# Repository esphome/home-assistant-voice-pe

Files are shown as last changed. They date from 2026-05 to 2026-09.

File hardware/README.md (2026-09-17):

# Home Assistant Voice Preview Edition

This repo contains the KiCad project files for the Home Assistant Voice Preview Edition device.

It is licensed under the CERN-OHL-P v2.

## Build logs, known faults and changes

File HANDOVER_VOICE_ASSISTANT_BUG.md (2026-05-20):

# Handover: Voice Assistant Microphone Restart Bug

## Summary

**Bug**: Voice PE starts listening before TTS audio finishes playing, causing the device to hear itself and re-trigger STT.

**Root Cause**: In `esphome/components/voice_assistant/voice_assistant.cpp`, the `RESPONSE_FINISHED` state transitions to `START_MICROPHONE` without waiting for the media player to finish playing.

**Fix Location**: `esphome/esphome` repository, file `esphome/components/voice_assistant/voice_assistant.cpp`

---

## Related Issues

- **Existing Issue**: https://github.com/esphome/home-assistant-voice-pe/issues/563
  - Title: "Microphone re-opens before announcement finishes playing in continuous conversation mode"
  - Status: Open
  - Created: 2026-03-20
  - Has 2 thumbs up reactions

- **Slack Thread**: https://openhomefoundation.slack.com/archives/C08MUM89GUW/p1779288998390289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

---

## Bug Details

### Symptoms

1. User configures Voice PE with:
   - OpenAI gpt-4o-transcribe for STT
   - Claude Sonnet for conversation engine
   - OpenAI TTS

2. When the assistant asks a follow-up question, the microphone starts listening **before** the TTS audio finishes playing

3. The device hears its own TTS output and re-triggers STT, causing conversation failures

### Log Evidence (from Slack)

**With OpenAI TTS (BROKEN)** - Only 2 seconds for 4+ second audio:
```
[16:32:34][D][voice_assistant:490]: Desired state set to STREAMING_RESPONSE
[16:32:34][D][voice_assistant:631]: Event Type: 2
[16:32:34][D][voice_assistant:773]: Assist Pipeline ended
[16:32:34][D][http_media_source:069]: Starting
[16:32:36][D][voice_assistant:483]: State changed from STREAMING_RESPONSE to RESPONSE_FINISHED
[16:32:36][D][voice_assistant:483]: State changed from RESPONSE_FINISHED to START_MICROPHONE
```

**With HA Cloud TTS (WORKING)** - 9 seconds matches audio length:
```
[16:44:04][D][http_media_source:069]: Starting
[16:44:13][D][voice_assistant:483]: State changed from STREAMING_RESPONSE to RESPONSE_FINISHED
```

### Why It Happens

- OpenAI TTS streams audio data faster than real-time playback
- The HTTP download completes in ~2 seconds
- But the audio file is 4+ seconds long
- The state machine sees "streaming complete" and transitions immediately
- No check exists for media player playback completion

---

## Technical Analysis

### State Machine Flow

```
STREAMING_RESPONSE 
    → (audio data streaming finishes)
    → RESPONSE_FINISHED 
    → (if continue_conversation_) 
    → START_MICROPHONE  ← BUG: No wait for media player!
```

### Current Code (voice_assistant.cpp)

```cpp
case State::RESPONSE_FINISHED: {
#ifdef USE_SPEAKER
  if (this->speaker_ != nullptr) {
    // Checks for speaker buffer - works for internal speaker
    if (this->speaker_buffer_size_ > 0) {
      this->write_speaker_();
      break;
    }
    if (this->speaker_->has_buffered_data() || this->speaker_->is_running()) {
      break;
    }
    // ... speaker cleanup
  }
#endif
  // BUG: When using media_player_ (not speaker_), no wait occurs!
  if (this->continue_conversation_) {
    this->set_state_(State::START_MICROPHONE, State::START_PIPELINE);
  } else {
    this->set_state_(State::IDLE, State::IDLE);
  }
  break;
}
```

### The Problem

When `speaker_` is `nullptr` (user configured `media_player:` instead of `speaker:`), the speaker buffer checks are skipped entirely. The code immediately checks `continue_conversation_` and transitions to `START_MICROPHONE`.

---

## Proposed Fix

Add a media player announcement check before transitioning to `START_MICROPHONE`:

```cpp
case State::RESPONSE_FINISHED: {
#ifdef USE_SPEAKER
  if (this->speaker_ != nullptr) {
    if (this->speaker_buffer_size_ > 0) {
      this->write_speaker_();
      break;
    }
    if (this->speaker_->has_buffered_data() || this->speaker_->is_running()) {
      break;
    }
    ESP_LOGD(TAG, "Speaker has finished outputting");
    this->speaker_->stop();
    this->cancel_timeout("speaker-timeout");
    this->cancel_timeout("playing");
    this->clear_buffers_();
    this->wait_for_stream_end_ = false;
    this->stream_ended_ = false;
    this->tts_stream_end_trigger_.trigger();
  }
#endif

  // === NEW CODE START ===
#ifdef USE_MEDIA_PLAYER
  // When using media_player (not internal speaker), wait for announcement to finish
  if (this->speaker_ == nullptr && this->media_player_ != nullptr) {
    if (this->media_player_->is_announcing()) {
      break;  // Keep waiting until media player finishes
    }
    ESP_LOGD(TAG, "Media player has finished announcing");
  }
#endif
  // === NEW CODE END ===

  if (this->continue_conversation_) {
    this->set_state_(State::START_MICROPHONE, State::START_PIPELINE);
  } else {
    this->set_state_(State::IDLE, State::IDLE);
  }
  break;
}
```

### Why This Fix Works

1. Only activates when `speaker_` is null AND `media_player_` is configured
2. Uses existing `is_announcing()` method from MediaPlayer component
3. Keeps looping in `RESPONSE_FINISHED` state until announcement completes
4. Minimal change, follows existing pattern for speaker checks

---

## Files to Modify

| File | Change |
|---|---|
| `esphome/components/voice_assistant/voice_assistant.cpp` | Add media player check in `RESPONSE_FINISHED` case |

---

## Testing

1. Configure Voice PE with:
   ```yaml
   voice_assistant:
     media_player: external_media_player
     # ... other config
   ```

2. Use a TTS provider that streams faster than real-time (OpenAI TTS)

3. Trigger a conversation that results in a follow-up question

4. Verify:
   - Microphone does NOT start until TTS audio finishes playing
   - Device does NOT hear itself
   - Continuous conversation works correctly

---

## Component Structure Reference

```
esphome/components/voice_assistant/
├── __init__.py          # ESPHome codegen, config schema
├── voice_assistant.h    # Class definition, State enum
└── voice_assistant.cpp  # Implementation, state machine (FIX HERE)
```

### Key Types

```cpp
enum class State {
  IDLE,
  START_MICROPHONE,
  STARTING_MICROPHONE,
  WAIT_FOR_VAD,
  WAITING_FOR_VAD,
  START_PIPELINE,
  STARTING_PIPELINE,
  STREAMING_MICROPHONE,
  STOP_MICROPHONE,
  STOPPING_MICROPHONE,
  AWAITING_RESPONSE,
  STREAMING_RESPONSE,
  RESPONSE_FINISHED,  // ← Bug is in handling of this state
};

// Member variables involved:
// - media_player::MediaPlayer *media_player_{nullptr};
// - speaker::Speaker *speaker_{nullptr};
// - bool continue_conversation_{false};
```

---

## PR Checklist

- [ ] Add media player check in `RESPONSE_FINISHED` state
- [ ] Add debug log message when media player finishes
- [ ] Test with OpenAI TTS + continuous conversation
- [ ] Test with HA Cloud TTS (regression check)
- [ ] Test with internal speaker (regression check)
- [ ] Link to issue #563 in PR description

---

## References

- Voice Assistant docs: https://esphome.io/components/voice_assistant/
- MediaPlayer component: https://esphome.io/components/media_player/
- Issue #563: https://github.com/esphome/home-assistant-voice-pe/issues/563
- ESPHome voice_assistant source: https://github.com/esphome/esphome/blob/dev/esphome/components/voice_assistant/voice_assistant.cpp

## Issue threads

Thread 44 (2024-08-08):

Enable out-of-the-box compatibility with third-party voice-kits like the FutureProofHomes Satellite1 PCB Dev Kit and Seeed Studio’s newReSpeaker Lite Voice Assistant Kit?

Hedda, 2024-08-08:
Maybe this is the wrong place to ask but wondering if there are plans to work in some template framework for ESPHome components like the [voice_assistant](https://github.com/esphome/voice-kit/tree/dev/esphome/components/voice_assistant) components and the [i2s_audio](https://github.com/esphome/voice-kit/tree/dev/esphome/components/i2s_audio) component for ESPHome to allow for out-of-the-box compability with third-party voice-kits that are also based on ESPHome and using similar hardware with the XMOS DSP chips and ESP32-S3 combination but perhaps are using different pins or maybe another SKU/model of XMOS xCORE DSP chip? Perhaps also reusable firmware builds for the most common XMOS xCORE DSP chips?

I know this is all still very early in development and Nabu Casa has not even yet formerly announced your upcoming voice-kit hardware platform but there are already some third-party ESP32-based voice-kits being made available or announced, such as example the newly released "**_ReSpeaker Lite Voice Assistant Kit_**" by @Seeed-Studio and the upcoming "**_Satellite1 PCB Dev Kit_**" open-source hardware product from @FutureProofHomes (which I understand is that project that @gnumpi and @ben-gineering also joined), and I am sure that we will see a few more related projects with hardware specifications before the end of this year. See:

- https://wiki.seeedstudio.com/xiao_respeaker/
  - https://wiki.seeedstudio.com/respeaker_lite_ha/
  - https://www.seeedstudio.com/ReSpeaker-Lite-Voice-Assistant-Kit-Full-Kit-of-2-Mic-Array-pre-soldered-XIAO-ESP32S3-Mono-Enclosed-Speaker-and-Enclosure.html
  - https://www.seeedstudio.com/ReSpeaker-Lite-Voice-Assistant-Kit-p-5929.html

- https://futureproofhomes.net/products/satellite1-pcb-dev-kit
  - https://github.com/FutureProofHomes/Satellite1-Hardware
  - https://www.youtube.com/watch?v=dRTLjQHfjSM

I spotted @nielsnl68 and @nanosonde writing they are using XMOS’s XK-VOICE-L71 (xCORE Voice Reference Design Evaluation Kit)and XFV3610-IN respectively which though very expensive might be still be interesting as an reference hardware for development if could use the same codebae for custom firmware builds with different XMOS DSP chips:

* https://www.xmos.com/xk-voice-l71

Then there should maybe is the future consideration of additional other projects that might not use XMOS xCORE DSPs but other hardware accelerated DSP solutions, such as for example this project by @alextrical where he is instead using ZL38063, though I understand if that would be out of scope at this point in time.

- https://community.home-assistant.io/t/far-field-satellite-with-an-elegant-3d-printed-enclosures/699893/
  - https://community.rhasspy.org/t/question-would-anyone-be-interested-in-a-open-source-dsp-mic-array/4941/

PS: Off-topic but just wanted to add that personally I am hoping to also see one ore more variants of updated ready-made clones of the "Onju Voice" open-source hardware PCB design project in the future with XMOS xCORE DSP chips that are drop-in replacements for all various models of Google Nest speakers and Google Home displays or Amazon Echo / Show voice assistant products that can work out-of-the-box so that users can reuse the enclosure and speakers of their existing products that might soon be outdated or irrelevant once we start fully moving over to Home Assistant's Voice Assistants ecosystem.

* https://github.com/justLV/onju-voice/
  * https://github.com/justLV/onju-voice/issues/59

tbrasser, 2024-08-08:
Quick reaction/question (on that last part), what is the current onju lacking with respect to xmos based i2s dacs? (that voice-kit relies on?)

Hedda, 2024-08-08:
> Quick reaction/question (on that last part), what is the current onju lacking with respect to xmos based i2s dacs? (that voice-kit relies on?)

Current onju-voice PCB design does not feature an XMOS chip, instead it only has ESP32-S3. See feature request discussion here:

* https://github.com/justLV/onju-voice/issues/59

kahrendt, 2024-08-11:
We are moving fast and breaking things as we figure out the best way for these components to interact, but we will add all the code to the base ESPHome project once things are stable and working well. One goal for this repo is to not be reliant on specific hardware configurations. These other boards you linked are quite exciting, and I believe they should be compatible (or relatively easily made compatible) with our changes. For example, all the I2S settings and pins are still configurable in yaml, so it should be straightforward to add support for similar boards.

Very little of the code is reliant specifically on the XMOS chip (and the few lines that are should be adaptable or won't even be there in the final version as we clean up the code), so it should be possible to add support for other DSPs in the future.

Hedda, 2024-08-13:
> it should be possible to add support for other DSPs in the future.

This is great! Yeah, I think that could be a very cool idea there could be to use the RP2040 or the new RP2350 MCU chip (from Raspberry Pi) and run open-source software audio DSP instead of the propriatory XMOS xCORE MCU chip.

That is, combine an ESP32 with RP2040 (or RP2350) on the same development board as I believe that combinatu would make for interesting development kit that could attract developers from other projects as well.

There are a few projects that use the PIO (Programmable Input Output) of the RP2040 / RPi Pico to create a audio DSP. However I could not find any projects that have voice specific software for audio DSPs, but maybe someone else know of such?

There are even projects that make sure of RP2040 (and Raspberry Pi Pico) as a GPU for graphic output to a display.

PS: I would think that having an reference hardware platform as a dev-kit for sale that would be attractive to other projects as well would be benefitial to achievibg better economy-of-scale that should keep the price down, which in turn should attract even more developers, especially those who like the concept of keeping everything 100% open-source.

Hedda, 2024-08-13:
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

@kahrendt Awesome timing! FYI, Raspberry Pi Foundation themselves has just a few days ago posted this bog article about Real-time ML audio noise suppression on Raspberry Pi Pico 2:

https://www.raspberrypi.com/news/real-time-ml-audio-noise-suppression-on-raspberry-pi-pico-2/

That blog delve into how an existing ML-based audio noise suppression algorithm can be deployed to Raspberry Pi’s RP2350 microcontroller used in the new Pico 2 board.

nielsnl68, 2024-08-16:
> I spotted @nielsnl68 and @nanosonde writing they are using XMOS’s XK-VOICE-L71 (xCORE Voice Reference Design Evaluation Kit)and XFV3610-IN
You spotted that wrong 😆 i'm using the M5Atom Echo for my Combadge project and th Raspaudio protokits for my inhouse audio services :D

Closed 2024-08-19.

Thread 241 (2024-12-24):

Voice PE bootloops after power reconnect and wifi is connected (watchdog) (v 24.12.8)

BobMcGlobus, 2024-12-24:
I received two voice pe today. After the first setup the bootloop problems started. When I reflash the boards everything works until I remove the power, then they just bootloop.
Does anyone have the same problem, or has an idea?
```
[18:01:54][I][wifi:617]: WiFi Connected!
[18:01:54][C][wifi:428]:   Local MAC: 20:F8:3B:09:30:F4
[18:01:54][C][wifi:433]:   SSID: 'MyWifi'[redacted]
[18:01:54][C][wifi:436]:   IP Address: 192.168.2.78
[18:01:54][C][wifi:439]:   BSSID: 5C:E9:31:B1:71:F2[redacted]
[18:01:54][C][wifi:441]:   Hostname: 'home-assistant-voice-0930f4'
[18:01:54][C][wifi:443]:   Signal strength: -44 dB ▂▄▆█
[18:01:54][C][wifi:447]:   Channel: 6
[18:01:54][C][wifi:448]:   Subnet: 255.255.255.0
[18:01:54][C][wifi:449]:   Gateway: 192.168.2.1
[18:01:54][C][wifi:450]:   DNS1: 192.168.2.160
[18:01:54][C][wifi:451]:   DNS2: 1.1.1.1
[18:01:54][C][api:026]: Setting up Home Assistant API server...
[18:01:54][C][micro_wake_word:083]: Setting up microWakeWord...
[18:01:54][C][micro_wake_word:109]: Micro Wake Word initialized
[18:01:54][I][app:062]: setup() finished successfully!
[18:01:58][D][esp-idf:000][wifi]: I (20245) wifi:
[18:01:58][D][esp-idf:000][wifi]: <ba-add>idx:1 (ifx:0, 5c:e9:31:b1:71:f2), tid:0, ssn:0, winSize:64
[18:01:58][D][esp-idf:000][wifi]:
[18:01:58]
[18:01:59]E (21342) task_wdt: Task watchdog got triggered. The following tasks/users did not reset the watchdog in time:
[18:01:59]E (21342) task_wdt:  - loopTask (CPU 0)
[18:01:59]E (21342) task_wdt: Tasks currently running:
[18:01:59]E (21342) task_wdt: CPU 0: IDLE0
[18:01:59]E (21342) task_wdt: CPU 1: IDLE1
[18:01:59]E (21342) task_wdt: Aborting.
[18:01:59]E (21342) task_wdt: Print CPU 0 (current core) backtrace
[18:01:59]
[18:01:59]
[18:01:59]
[18:01:59]
[18:01:59]Backtrace: 0x40383577:0x3fcaffc0 0x420b2d31:0x3fcaffe0 0x4038717b:0x3fcb0000
[18:01:59]
[18:01:59]
[18:01:59]
[18:01:59]
[18:01:59]ELF file SHA256: c77aced757c7321d
[18:01:59]
[18:01:59]Rebooting...
```

aaron-baff-ad-net, 2024-12-26:
I'm getting the exactly same thing. I'm using a discrete IOT VLAN/WiFi, which has no Internet access. Successfully got it added (after doing `esptool erase_flash` and then re-flashing with `ha-voice-8mb-esp32s3.factory.bin`. Tried with both 24.12.8, and now 24.12.9 just today. I was logging from the USB Serial port, from the first boot, adding to WiFi, then clicking the Setup Voice Assistant on the ESPHome Device and subsequent start of boot loop.

[voice-pe.log](https://github.com/user-attachments/files/18256057/voice-pe.log)

Drizzt321, 2024-12-27:
I'm getting the exactly same thing. I'm using a discrete IOT VLAN/WiFi, which has no Internet access. Successfully got it added (after doing esptool erase_flash and then re-flashing with ha-voice-8mb-esp32s3.factory.bin. Tried with both 24.12.8, and now 24.12.9 just today. I was logging from the USB Serial port, from the first boot, adding to WiFi, then clicking the Setup Voice Assistant on the ESPHome Device and subsequent start of boot loop.

Deleted and re-added to be my personal account, not my work account, oops.

[voice-pe.log](https://github.com/user-attachments/files/18256467/voice-pe.log)

Bre77, 2024-12-27:
I am getting the same thing, seperate IOT VLAN except it has full internet access, and plently of other ESPHome devices on it. Moving my Voice PE to the same subnet as my Home Assistant instance has fixed the issue.

Drizzt321, 2024-12-27:
My HA instance is dual-homed, a VM on FreeBSD, with 2 virtual NICs, one on my Public, and one on my IOT VLANs, so there's no particular reason why there would be an issue. Both have the same IPs, so not routed.

eastman-tech, 2024-12-27:
I am experiencing the same issue (specifically task watchdog trigged/forced repeating reboot). I do have vlans in my network, but they are unrelated and HA and the Voice PE device are on the same vlan.

Drizzt321, 2024-12-27:
@eastman-tech is the VLAN that HA & Voice PE are on able to connect to the internet or not?

Drizzt321, 2024-12-27:
I actually just had a thought, when starting the Voice Setup, I see the UI in HA saying something about checking for updates, and I wonder if something in that, with the Voice PE firmware, since in my case it can't connect to the internet, even though HA can, but on a different NIC than the Voice PE, unable to connect to the internet is why Voice PE is bootlooping?

eastman-tech, 2024-12-27:
> @eastman-tech is the VLAN that HA & Voice PE are on able to connect to the internet or not?

Yes, but I do have a pihole and Unifi gear with some custom rules.

Drizzt321, 2024-12-27:
Hmph. I wonder if, despite the 24.12.8 supposedly fixing it (according to the email I got back from support), it still expects to be able to talk to the Internet, rather than HA talking to the internet, and the Voice PE not, officially, needing to since it's supposed to be able to do everything locally via HA.

jackwilsdon, 2024-12-27:
Update checks (and updating from the official releases) are performed by the Voice PE itself, so it needs internet for that.

Drizzt321, 2024-12-27:
@jackwilsdon I thought part of the point of Voice PE was being able to be completely offline, including HA. I'll definitely agree that any updates would necessarily need access to the internet somehow, although I would imagine that manual updates would be possible if someone was so drive to download elsewhere and copy the files over, or that it could be updated from HA, rather than itself.

I would still contend that lack of internet shouldn't cause a crash/bootloop however.

eastman-tech, 2024-12-28:
It might have been an issue with my piholes. Rebooted and patched them, and I'm not experiencing the issue anymore currently. Will report back if the issue returns.

I concur though that I'd love for those of us trying to run as much as possibly locally, including not bootlooping if it thinks the internet is down for some reason.

Drizzt321, 2024-12-28:
Because, well, the internet can be down sometimes anyways!

jf-uu, 2024-12-28:
I think it's pretty clear that it isn't intended for it to crash without internet - there's a fix open on the esphome repo already.

The Voice PE was never marketed as an offline device from what I can tell - it's marketed as a privacy focused device. It is meant to work without internet, you just won't get updates.

I agree it would be nice if it didn't require internet for updates. You could take control of the device in ESPHome Device Builder, which would allow pushing updates (but it seems like it's not recommended if you aren't making changes).

Drizzt321, 2024-12-28:
> The Voice PE was never marketed as an offline device from what I can tell - it's marketed as a privacy focused device. It is meant to work without internet, you just won't get updates.
>
> I agree it would be nice if it didn't require internet for updates. You could take control of the device in ESPHome Device Builder, which would allow pushing updates (but it seems like it's not recommended if you aren't making changes).

The way I read https://voice-pe.home-assistant.io/guides/update/ is that HomeAssistant was the one that checked for updates, not the device itself.

And on it's main page https://www.home-assistant.io/voice-pe/

```
Let’s make open, local, and private voice assistants a reality
```

Local, to me, means offline, with some which way to update it as needed.

Under `Can I run this voice assistant fully local?`
```
Yes, provided your language is supported and you have hardware powerful enough to run local text-to-speech and speech-to-text models at a speed that is acceptable to you. Speech-to-text is the main limiting factor for many languages to run locally, as it has mixed results and often requires powerful hardware.
```

Which is talking about the host (aka HA) hardware requirements, but "Yes", to me, is not needing to access the Internet. Other than to install any necessary HA Add-Ons or the like of course.

So I suppose it's a communications/expectations failure/misalignment. I expected updates to come through the HA instance that it was connected to, and otherwise never need the internet. Unless I wanted to use the HA Cloud Voice part, in which case that would be done through the HA instance that the device was connected.

Drizzt321, 2024-12-28:
Hopefully the potential bugfix in upstream ESPHome gets pulled in quickly, and a new Voice PE firmware version gets built soon.

latargere, 2024-12-30:
Same issue on my side, any update for the fix?

aaron-baff-ad-net, 2024-12-30:
> Same issue on my side, any update for the fix?

The linked ticket https://github.com/esphome/esphome/pull/8018 in ESPHome hasn't been merged yet. Seems ready to go, but with the holidays and all it's not surprising that it hasn't been finished off and merged. Wish it would be, but it is what it is.

Drizzt321, 2024-12-30:
> Same issue on my side, any update for the fix?

The linked ticket https://github.com/esphome/esphome/pull/8018 in ESPHome hasn't been merged yet. Seems ready to go, but with the holidays and all it's not surprising that it hasn't been finished off and merged. Wish it would be, but it is what it is.

Drizzt321, 2025-01-09:
Confirming this works fine after the new firmware.

Closed 2025-01-02.

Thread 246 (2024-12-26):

tensorflow/lite/core/c/common.h: No such file or directory

VACIndustries, 2024-12-26:
Received two PEs; setup in earlier today (maybe 8 hours ago?) and the firmware update went fine.  Just tried to setup the second one and now I'm receiving this:

```
INFO ESPHome 2024.12.2
INFO Reading configuration /config/esphome/home-assistant-voice-0916d9.yaml...
INFO Updating https://github.com/esphome/home-assistant-voice-pe@dev
WARNING GPIO0 is a strapping PIN and should only be used for I/O with care.
Attaching external pullup/down resistors to strapping pins can cause unexpected failures.
See https://esphome.io/guides/faq.html#why-am-i-getting-a-warning-about-strapping-pins
WARNING GPIO3 is a strapping PIN and should only be used for I/O with care.
Attaching external pullup/down resistors to strapping pins can cause unexpected failures.
See https://esphome.io/guides/faq.html#why-am-i-getting-a-warning-about-strapping-pins
WARNING GPIO45 is a strapping PIN and should only be used for I/O with care.
Attaching external pullup/down resistors to strapping pins can cause unexpected failures.
See https://esphome.io/guides/faq.html#why-am-i-getting-a-warning-about-strapping-pins
INFO Generating C++ source...
INFO Updating https://github.com/espressif/esp-protocols.git@mdns-v1.3.2
INFO Updating https://github.com/espressif/esp-tflite-micro@v1.3.1
INFO Compiling app...
Processing home-assistant-voice-0916d9 (board: esp32-s3-devkitc-1; framework: espidf; platform: https://github.com/pioarduino/platform-espressif32.git#51.03.07)
--------------------------------------------------------------------------------
HARDWARE: ESP32S3 240MHz, 320KB RAM, 8MB Flash
 - framework-espidf @ 3.50105.0 (5.1.5)
 - tool-cmake @ 3.21.3
 - tool-esptoolpy @ 4.8.1
 - tool-mklittlefs @ 3.2.0
 - tool-ninja @ 1.7.1
 - tool-riscv32-esp-elf-gdb @ 12.1.0+20221002
 - tool-xtensa-esp-elf-gdb @ 12.1.0+20221002
 - toolchain-esp32ulp @ 2.35.0-20220830
 - toolchain-riscv32-esp @ 12.2.0+20230208
 - toolchain-xtensa-esp32s3 @ 12.2.0+20230208
Reading CMake configuration...
Dependency Graph
|-- esp-audio-libs @ 1.0.0
|-- noise-c @ 0.1.6
|-- ESPMicroSpeechFeatures @ 1.1.0
Compiling .pioenvs/home-assistant-voice-0916d9/src/esphome/components/api/api_connection.cpp.o
Compiling .pioenvs/home-assistant-voice-0916d9/src/esphome/components/i2c/i2c.cpp.o
Compiling .pioenvs/home-assistant-voice-0916d9/src/esphome/components/i2c/i2c_bus_arduino.cpp.o
Compiling .pioenvs/home-assistant-voice-0916d9/src/esphome/components/i2c/i2c_bus_esp_idf.cpp.o
Compiling .pioenvs/home-assistant-voice-0916d9/src/esphome/components/i2s_audio/i2s_audio.cpp.o
Compiling .pioenvs/home-assistant-voice-0916d9/src/esphome/components/i2s_audio/speaker/i2s_audio_speaker.cpp.o
Compiling .pioenvs/home-assistant-voice-0916d9/src/esphome/components/light/addressable_light.cpp.o
In file included from src/esphome/components/i2s_audio/i2s_audio.h:5,
                 from src/esphome/components/i2s_audio/i2s_audio.cpp:1:
/data/cache/platformio/packages/framework-espidf@src-6e6cd5244a43bdfe453daac50cfe73b6/components/driver/deprecated/driver/i2s.h:27:2: warning: #warning "This set of I2S APIs has been deprecated, please include 'driver/i2s_std.h', 'driver/i2s_pdm.h' or 'driver/i2s_tdm.h' instead. if you want to keep using the old APIs and ignore this warning, you can enable 'Suppress leagcy driver deprecated warning' option under 'I2S Configuration' menu in Kconfig" [-Wcpp]
   27 | #warning "This set of I2S APIs has been deprecated, \
      |  ^~~~~~~
Compiling .pioenvs/home-assistant-voice-0916d9/src/esphome/components/light/automation.cpp.o
Compiling .pioenvs/home-assistant-voice-0916d9/src/esphome/components/light/esp_color_correction.cpp.o
In file included from src/esphome/components/i2s_audio/speaker/../i2s_audio.h:5,
                 from src/esphome/components/i2s_audio/speaker/i2s_audio_speaker.h:5,
                 from src/esphome/components/i2s_audio/speaker/i2s_audio_speaker.cpp:1:
/data/cache/platformio/packages/framework-espidf@src-6e6cd5244a43bdfe453daac50cfe73b6/components/driver/deprecated/driver/i2s.h:27:2: warning: #warning "This set of I2S APIs has been deprecated, please include 'driver/i2s_std.h', 'driver/i2s_pdm.h' or 'driver/i2s_tdm.h' instead. if you want to keep using the old APIs and ignore this warning, you can enable 'Suppress leagcy driver deprecated warning' option under 'I2S Configuration' menu in Kconfig" [-Wcpp]
   27 | #warning "This set of I2S APIs has been deprecated, \
      |  ^~~~~~~
In file included from src/esphome/components/micro_wake_word/micro_wake_word.h:6,
                 from src/esphome/components/voice_assistant/voice_assistant.h:16,
                 from src/esphome/components/api/api_connection.cpp:22:
src/esphome/components/micro_wake_word/streaming_model.h:9:10: fatal error: tensorflow/lite/core/c/common.h: No such file or directory
    9 | #include <tensorflow/lite/core/c/common.h>
      |          ^~~~~~~~~~~~~~~~~~~~~~~~~~~~~~~~~
compilation terminated.
*** [.pioenvs/home-assistant-voice-0916d9/src/esphome/components/api/api_connection.cpp.o] Error 1
========================== [FAILED] Took 5.03 seconds ==========================

```

kahrendt, 2024-12-26:
The I2S deprecation is just a warning, the code itself runs fine.

I'm not sure why you are getting this error, as it seems to be missing the TensorFlow libraries, but they should automatically be added by ESPHome. How are you running the ESPHome device builder?

In general, you do not need to take control of the Voice PE firmware unless you are modifying it. You should be able to add, use, and update the device in HA without needing the ESPHome device builder.

VACIndustries, 2024-12-26:
Correct! That's why I was taking control/updating before replicating the repo and making some adjustments -- just running the ESPHome Device Builder add on off of my HAOS x86 laptop

VACIndustries, 2024-12-30:
Problem went away "magically" (I assume a backend dependency issue?).  Closing as a result

Closed 2024-12-30.

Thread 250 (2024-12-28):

Can't join WiFI with WPA3 enabled

lordexorr, 2024-12-28:
It seems the Voice PE devices are unable to connect to WiFi networks with WPA3 enabled. I was unable to get either of my 2 devices to connect to my network. As a test I created a guest network with WPA2 only and was able to connect the devices to WiFi.

My network also has Management Frame Protection enabled; but I'm not sure this is related. I suspect it's the WPA3 item, but wanted to mention it just in case.

I was running the Firmware Shipped with the devices at the time; I have since upgraded to the latest (24.12.8).

The thread below shows another user had the same issue.

https://community.home-assistant.io/t/voice-pe-unable-to-connect-to-wifi/817454/8

Drizzt321, 2024-12-28:
Is your WiFi WPA3 _only_, or does it allow mixed WPA3 & WPA2 devices?

I think they're at the mercy of ESP WiFi hardware, which probably only supports WPA2.

lordexorr, 2024-12-28:
It allows mixed; WPA2/3 as well as using MLO to combine 2.4/5/6GHz bands in one. If it doesn’t support some of these types of networks or frequencies that should be documented and noted prior to purchasing.

Drizzt321, 2024-12-28:
Hm, what channel width on 2.4GHz are you running with?

So the [specs](https://www.home-assistant.io/voice-pe/) specifically say 2.4GHz WiFi, and says ESP32-S3. So easy to find the [datasheet](https://www.espressif.com/sites/default/files/documentation/esp32-s3_datasheet_en.pdf). Which for WiFi specs/MAC says, most important bits:

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

So make sure your WiFi settings would on 2.4GHz would support it, allow older N clients, and only 20 or 40 MHz channels.

lordexorr, 2024-12-29:
The specs say 2.4GHz WiFi and my network supports 2.4GHz WiFi. I have many other smart home devices that support only 2.4GHz devices and have no issues joining my network (the first one below). Below are screenshots of the network configurations.

Network that does NOT work;
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

Network that does work;
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

What aspect of the first network is preventing it from working? It still seems like a bug to me which is why I'm posting it here.

Drizzt321, 2024-12-29:
Do you know if any of those other devices are ESP chips? If so then it's something with this particular firmware.

I'm unfamiliar with whatever AP/router software that those are screenshots of, but what's the channel width on whichever WiFi that it's unable to connect to? Specifically on the 2.4GHz network. It can only handle 20 or 40 MHz channel width. Which for 2.4GHz, unless you live way out away from other folks, the 20MHz channels are better, and choose one of 1, 6, or 11.

lordexorr, 2024-12-29:
It's not something I can specifically set when using WiFi 7/MLO. However, it supports below. Any device that requires any of these should be supported and should be able to join the network without me needing to configure anything else.

2.4GHz BE: 4x4 (Tx/Rx) 4096 QAM 20/40MHz, up to 1376Mbps
5GHz BE: 4x4 (Tx/Rx) 4096 QAM 20/40/80/160MHz, up to 5764Mbp
6G-1Hz BE: 4x4 (Tx/Rx) 4096 QAM 20/40/80/160/320MHz, up to 11529Mbp
6G-2Hz BE: 4x4 (Tx/Rx) 4096 QAM 20/40/80/160/320MHz, up to 11529Mbp

I do not know if anything else uses ESP chips; that's above my knowledge :)

Drizzt321, 2024-12-30:
Hm, so I see there's a WiFi7 checkbox. Does that mean it's WiFi7 only? Or just WiFi7 with WiFi7 clients? Really not sure what's going on here. Maybe someone more familiar with WiFi7, or WiFi in general, could help troubleshoot what might be the issue? I still suspect it's something to do with the modes that it's in that isn't compatible with the underlying ESP32 hardware.

lordexorr, 2024-12-30:
Ok; its not the ESP32 hardware. I ordered 2 ratgdo32's for my garage doors and set them up today. They had zero issues connecting to my WiFi.

aaron-baff-ad-net, 2024-12-30:
That's a great sample, really not sure what's going on then.

Drizzt321, 2024-12-30:
That's a great sample, not sure what's going on then.

kbx81, 2025-01-09:
FWIW, all of my ESPHome devices are connecting to an SSID shared among 2.4, 5 and 6 GHz bands and with only WPA3 enabled. I have no issues with it at all and there's nothing special in my ESPHome configs.

sokyrko, 2025-02-24:
@lordexorr looking on you screenshots, I have the same or similar router. I tried wpa2 network too, but it did not work. However, disabling `Roaming assistant` feature on 2.4Ghz band helped, not a single disconnect since then.

lordexorr, 2025-04-05:
I decided to reset these to factory defaults today and add again. This time it joined my normal network with no issues. A firmware update must've resolved this issue.

Closed 2025-04-05.

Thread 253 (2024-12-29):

stops responding to wake word

bbrendon, 2024-12-29:
The button on top works to activate and recognize commands but it stops recognizing the wake word. Reboot fixes it for a few hours. So far I've been rebooting 3-5 times per day.

I have two units, and it happens to both of them.

RichardMawdsley, 2025-01-03:
+1 for me too. I have two of these but it only happens to one of them.

If I change a setting on the device such as the wake word or anything, then it usually kicks it into gear and it starts listening again. It's as if it goes to sleep or something.

RichardMawdsley, 2025-01-09:
> "Hey Jarvis" does not work well. Only one or two tries, then it needs a reboot. If you switch to "Okay Nabu" it works quite stable for me.

I've got two and it's absolutley fine on one, and has this issue on the other. Not convinced the wake word is the issue.

bbrendon, 2025-01-10:
I'm starting to try ok nabu and it seems to be better. Jarvis is atrocious.

jlpouffier, 2025-01-17:
Do you have logs of pressing the button and not being able to use the wake words afterwards please?

bbrendon, 2025-01-19:
@jlpouffier I don't think anyone here has that issue.

RichardMawdsley, 2025-01-20:
I've pretty much narrowed this down to 'Hey Jarvis', but only on one of my units.  If I leave it set as Hey Nabu or Hey Mycroft, it's absolutely fine and always responds.  Leave it on Hey Jarvis, it becomes intermittent after a 'while' (anywhere from hours to days).

Again, this only happens on one of my two units.  The other, set to Hey Jarvis, is absolutely perfect.

Unsure how to troubleshoot this further, if there's any particular information you need please let me know.

jlpouffier, 2025-01-22:
> [@jlpouffier](https://github.com/jlpouffier) I don't think anyone here has that issue.

Then what is the issue exactly.
> The button on top works to activate and recognize commands but it stops recognizing the wake word.

For what I understand, if you use the center button, then the wake word does not work afterwards?

RocketRammer, 2025-01-22:
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

The issue is the 'Hey Jarvis' wake word stops responding.  Pressing the center button works as expected and then afterwards, Hey Jarvis responds absolutely fine.. until it doesn't again.

It's as if its going to sleep on it...  though I say that when actually some of the time it seems like it's not listening at its maximum ability.  If I get completely, lip to lip close to it and 'Hey Jarvis' it, it works... and then continues to work from normal distances.

I completely understand I'm giving very odd circumstances, just trying to report what I'm finding with this one unit.  If there's anything specific I can provide please let me know.

jlpouffier, 2025-01-22:
If I read between the lines, it's just a problem of difficulties triggering a wake word.
The center button has nothing to do with this, right?

RocketRammer, 2025-01-22:
Correct.  There is no fault with the center button.  That works every time.

jlpouffier, 2025-01-23:
OK, then this is, unfortunately, expected.
We're working hard on improving the wake words, but you need to understand that there is no shortcut on this process, unfortunately.

Wake words are initially trained on synthetic samples of the wake word generated from Piper.
What is skyrocketing the quality of our wake word is to fine-tune it with real data samples.

This is why we opened the Wake Word Collective, you can read more about it on [our blog](https://www.home-assistant.io/blog/2024/10/24/wake-word-collective/)

As of today, we are working on improving the quality of `OK Nabu`.
We may open the wake word collective to other wake words once we are happy with the quality of `OK Nabu`.

I suggest participating in the wake word collective, and, again, unfortunately, being patient.

Again, there are no shortcuts when creating good quality wake words, it's a huge undertaking.

Thx for your understanding!

Closing this issue for now.

JLo

RocketRammer, 2025-01-23:
If only people wanted 'OK Nabu'...

bbrendon, 2025-01-24:
I would suggest removing Jarvis until it’s at least usable.

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

Closed 2025-01-23.

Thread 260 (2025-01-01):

Radio Stream fails on Music Assistant

ramapge123, 2025-01-01:
Attempting to play a Radio stream from Music Assistant on the device however fails after a few seconds up to 30 seconds on different stations.

Radio stations work fine on other devices such as a satellite or google homes.

Is there further debugging I can do to get better logs?

[14:31:44][D][media_player:080]: 'Media Player' - Setting
[14:31:44][D][media_player:087]:   Media URL: http://192.168.1.4:8098/flow/media_player.home_assistant_voice_0908c7_media_player/3b53ed54ca384bb2a6bc20e49a379b5d.mp3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
[14:31:44][D][nabu_media_player.pipeline:173]: Reading MP3 file type
[14:31:46][D][nabu_media_player.pipeline:184]: Decoded audio has 2 channels, 48000 Hz sample rate, and 16 bits per sample
[14:31:48][E][nabu_media_player:299]: The media pipeline's audio decoder encountered an error.

ramapge123, 2025-01-02:
Issue was fixed with Music Assistant Update.

kahrendt, 2025-01-03:
This should be fixed with Music Assistant 2.3.5. Previous versions were sending an mp3 stream instead of FLAC, and the mp3 decoder on the device is a bit fragile. If it still is problematic after updating, please reopen!

marcelveldt, 2025-01-22:
One additional comment on this is that you may have to delete the player from MA and re-add it to clear any old config where the codec was enforced to MP3. Also, if you are not running the default firmware for Voice PE provided by Nabu Casa but a custom one, ensure that you do not change the model name. We currently use a [hardcoded list of model names ](https://github.com/music-assistant/server/blob/dev/music_assistant/providers/hass_players/__init__.py#L101)to detect ESPHome based media players that run the new media player component.

Closed 2025-01-03.

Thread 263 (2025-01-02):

Built-in speaker and 3.5mm at the same time

mackeapple22, 2025-01-02:
I would like to use the Voice PE mainly as a network media player. I have connected it using 3.5mm to an AV receiver, but once I connect it with 3.5mm it shuts off the internal speaker of the Voice PE.
I would like a choice of having Assist responses through the Voice PE's internal speaker, and music playing through my AV system (I can't get an audio response from the Voice PE if my receiver is turned off).

jackwilsdon, 2025-01-03:
It looks like the speaker muting is implemented in hardware from the [schematic](https://voice-pe.home-assistant.io/resources/home_assistant_voice_pe_schematic_v1.0_241009.pdf):

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

MICDET is normally connected to GND but is disconnected when a jack is inserted, causing Q2 to turn on (pulled up by R26). This pulls AMP_CTL down and turns off the amplifier for the built-in speaker. The ESP can control the amplifier with AUDIO_PA_EN, but it can't overpower Q2.

ItsHarper, 2025-02-25:
The ReSpeaker's headphone jack detection circuit seems to work similarly to this one (at a bare minimum in that `MICDET` is connected to ground when no plug is inserted into the jack), and their documentation explains that you can short `MICDET` to ground in order to disable detection, enabling software control. It even documents how to switch the output on the TLV320AIC3204 DAC/codec (the same one used in the Voice PE).

https://github.com/respeaker/ReSpeaker_Lite?tab=readme-ov-file#disable-the-headphone-jack-detection-circuit

Now, the ReSpeaker is physically designed so that it's very easy to short `MICDET` to ground. I don't know if the Voice PE is set up that way or not (and of course you'll have to disassemble the device regardless).

BTW, I'm sure it's not a coincidence that the circuitry is similar and that they use the same codec, as it appears that both devices were designed by Seeed Studio.

WhiteSockedDancer, 2025-03-01:
I got exactly the same usecase.

But this would just disable the detection of the jack? How would we control output with software then?

Closed 2025-01-03.

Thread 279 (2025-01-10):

Turn off the microfrontend autogain and noise_suppression?

StuartIanNaylor, 2025-01-10:
https://github.com/google-ai-edge/LiteRT/tree/main/tflite/experimental/microfrontend

I wasn't sure if the config_yaml actually disables microfrontend autogain and noise_suppression or remember if they are disabled training params.
The xmos algs have AGC and NS so if active you likely have a duplication and the microfrontend libs are likely inferior
noise_suppression_level: 0
auto_gain: 0 dbfs

https://github.com/google-ai-edge/LiteRT/blob/main/tflite/experimental/microfrontend/python/ops/audio_microfrontend_op.py
```
def audio_microfrontend(audio,
                        sample_rate=16000,
                        window_size=25,
                        window_step=10,
                        num_channels=32,
                        upper_band_limit=7500.0,
                        lower_band_limit=125.0,
                        smoothing_bits=10,
                        even_smoothing=0.025,
                        odd_smoothing=0.06,
                        min_signal_remaining=0.05,
                        enable_pcan=True,
                        pcan_strength=0.95,
                        pcan_offset=80.0,
                        gain_bits=21,
                        enable_log=True,
                        scale_shift=6,
                        left_context=0,
                        right_context=0,
                        frame_stride=1,
                        zero_padding=False,
                        out_scale=1,
                        out_type=dtypes.uint16):
```
Seems to be enabled in the python microfrontend for training so presuming is also in https://github.com/google-ai-edge/LiteRT/blob/main/tflite/experimental/microfrontend/ops/audio_microfrontend_op.cc
Dunno but likely both should be disabled when using the xmos and datasets normalised to xmos levels

kahrendt, 2025-01-17:
The mWW models do not work well if you just turn off the AGC and NS, as they were trained with them on. Ideally, we would train on audio processed by XMOS's algorithms, but there doesn't seem to be a straightforward way to do this.

We tested several different versions of the audio fed into mWW. Only AEC applied, AEC + Noise Supression, AEC + NS + Interference Cancellation, and AEC + NS + IC + Automatic Gain Control. We had the best results with AEC + NS + IC, so that's what the firmware uses. Duplicating the AGC increased the number of false activations. The XMOS NS and IC algorithms don't seem to interfere with the microfeature's NS algorithm.

StuartIanNaylor, 2025-01-17:
I am saying turn off AGC and NS in training so you can turn off AGC and NS of audio fed into mWW.
Its very likely the TF4Micro NS is more rudimentary than the Xmos NS/Voice extraction but is further up the audio stream so reducing Xmos input to the TF4Micro NS alg...

You tested several different versions of the audio fed into mWW and never changed the training ?!
AGC is just Automatic Gain Control and recording via a constant wyoming broadcast with no mWW would give you a dataset to assess at the 0.3-3m what levels the AGC give that you can duplicate in a dataset.
It would be really good if the Xmos USB Audio class libs where enabled but unfortunately only the DFU driver is enabled.
Then it would be plug&play from Pi to PC but a straight to Wyoming setup could be used to analyse the AGC.
The need for TF4Micro NS is likely it produces artifacts that are being introduced in training...

Its not just you are wasting the purchased in speech enhancement by forcing it through basic algs to run on a selection of low end microcontrollers you are wasting all those ops on the esp32-S3.
'closed this as not planned' ?!? ok...

Closed 2025-01-17.

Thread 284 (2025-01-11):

The components are not compatible with the i2s microphone

KristopherMackowiak, 2025-01-11:
If we want to use the code in a DIY project, after changing the microphone from nuba to i2s the device gets a bootloop

Error:
Guru Meditation Error: Core 1 panic'ed (LoadProhibited). Exception was unhandled.

KristopherMackowiak, 2025-01-11:
To test you can flash esphome code to clean ESP32 S3 board with replace microphone section to

microphone:
  - platform: i2s_audio
    id: asr_mic
    i2s_din_pin: GPIO15
    adc_type: external
    bits_per_sample: 32bit
    i2s_audio_id: i2s_input

and set mic id in wake word and assistant section

synesthesiam, 2025-01-14:
The various nabu components are being upstreamed into ESPHome, but this will take time.

ItsHarper, 2025-02-25:
ESPHome 2025.2 moves a lot of the code here upstream, I would look into this again

whc2001, 2025-03-18:
Same here, the microphone component on 2025.3 still does not support `TickType_t ticks_to_wait`, and using the microphone component in this repo I got something wrong in the underlying I2S reading process:
```
[20:13:21][D][micro_wake_word:379]: Starting wake word detection
[20:13:21]Guru Meditation Error: Core  0 panic'ed (LoadProhibited). Exception was unhandled.
[20:13:21]
[20:13:21]Core  0 register dump:
[20:13:21]PC      : 0x4205f2c8  PS      : 0x00060630  A0      : 0x8200e0d3  A1      : 0x3fcc8e50
WARNING Decoded 0x4205f2c8: i2s_read at C:\Users\WHC\.platformio\packages\framework-espidf\components\driver\deprecated/i2s_legacy.c:1739 (discriminator 2)
[20:13:21]A2      : 0x00000000  A3      : 0x3c1f4670  A4      : 0x00000140  A5      : 0x3fcc8e90
[20:13:21]A6      : 0x00000000  A7      : 0x3fca2e28  A8      : 0x3fca2e28  A9      : 0x00000001
[20:13:21]A10     : 0x03cc8200  A11     : 0x3fcc8200  A12     : 0xb33fffff  A13     : 0xfffffffd
[20:13:21]A14     : 0x00000404  A15     : 0x0000000a  SAR     : 0x00000001  EXCCAUSE: 0x0000001c
[20:13:21]EXCVADDR: 0x00000014  LBEG    : 0x400570e8  LEND    : 0x400570f3  LCOUNT  : 0x00000000
[20:13:21]
[20:13:21]
[20:13:21]Backtrace: 0x4205f2c5:0x3fcc8e50 0x4200e0d0:0x3fcc8e90 0x420ed479:0x3fcc8ec0 0x4201331a:0x3fcc8ee0
WARNING Found stack trace! Trying to decode it
WARNING Decoded 0x4205f2c5: i2s_read at C:\Users\WHC\.platformio\packages\framework-espidf\components\driver\deprecated/i2s_legacy.c:1739 (discriminator 2)
WARNING Decoded 0x4200e0d0: esphome::i2s_audio::I2SAudioMicrophone::read(short*, unsigned int) at E:\ESPHome_Projects\esp32-voice-assistant\.esphome\build\esp32-voice-assistant/src/esphome/components/i2s_audio/microphone/i2s_audio_microphone.cpp:161
WARNING Decoded 0x420ed479: esphome::microphone::Microphone::read(short*, unsigned int, unsigned long) at E:\ESPHome_Projects\esp32-voice-assistant\.esphome\build\esp32-voice-assistant/src/esphome/components/microphone/microphone.h:31
WARNING Decoded 0x4201331a: esphome::micro_wake_word::MicroWakeWord::preprocessor_task_(void*) at E:\ESPHome_Projects\esp32-voice-assistant\.esphome\build\esp32-voice-assistant/src/esphome/components/micro_wake_word/micro_wake_word.cpp:165
```

Hedda, 2025-05-09:
Will be solved by https://github.com/esphome/home-assistant-voice-pe/pull/392 once or ESPHome 2025.5.0 has been released?

* https://github.com/esphome/home-assistant-voice-pe/pull/392

  * https://github.com/esphome/esphome/pull/8645

    * https://esphome.io/changelog/

Closed 2025-05-21.

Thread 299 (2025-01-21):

Poor wake word pickup

vhamburger, 2025-01-21:
Hey, got my device last week and I notice that it really is poorly performing when using the wake word.
I have set it to "Okay Nabu" and it sits in my living room next to my Alexa (which I want to get rid of...).
However, when I calmly say "Okay Nabu" it never picks up my voice - from like 2m away. I have to raise my voice clearly to let it pick up.
On the funny side - I have a self built voice assistant based on a raspberry pi and mic hat - which picks up my command every time - but it is sitting some 12 meters away in my home office. That cant be correct.

Is there a way to adopt the microphone gain / or set the xmos different to make it work better? Because right now, wife approval factor is below 0 since it never picks up any command.
I am happy to adopt it in ESP home and change the params manually if necessary - just want to make it work reliably.

RocketRammer, 2025-01-23:
+1 for wife approval factor.  I understand that these are Preview kits, but that's not how consumer law works when you've marketed it as having X feature.  Having to sit with my face pressed against it is not how it's marketed.

Warren-0, 2025-01-30:
I have this issue too. Okay Nabu will only wait it 1 in 43 times or so. I tried Hey Jarvis and I have to be few inches away from it to respond.

Australian accent here though. I do have the pi zero* and mic hat and that picks up every time.  I can use the PE this in the office for now, but not in a room where it must sit 1 to 8 meters away at any time. Just feedback nothing more from me.

RassK, 2025-02-02:
Not sure if this is mic / hw issue. Faster whisper with large-v3 model seems very good even with a very rare accent (estonian). In the other hand, wake word works very poorly here too.

grigi, 2025-02-05:
I found that if I deliberately say the wake words in a higher pitch it's significantly more likely to get it, but it's really not good enough for me.
I tried to setup openwakeword (the add-on) but i can't get it added to wyoming, nor can I find where to configure it in the assist config. If it was deprecated the documentation isn't making it clear. A bit frustrating.

jf-uu, 2025-02-05:
@grigi the Voice PE uses microWakeWord to perform on-device wake word detection, so you won't be able to use openWakeWord with it.

vhamburger, 2025-02-20:
Is anyone working on this one or is this only my device. Since ESPHome 2025.2.0 it has gotten worse. I practically have to yell at the device standing 1m in front of it. Is my device broken? Do I have to return it - or is this just "how it is"?
Can anyone let me know if you see a similar pattern?
For comparison - I have built an assist satellite on an RPI with a 2mic hat and it works flawlessly any time - even from across the room. However, it streams the wake word to HA which probably has a more powerful detection engine and noise cancellation capabilities.

The current state makes the Voice PE unusable in my household, no one wants to use it as it is never picking up the wake word. Sad.

RocketRammer, 2025-02-20:
I've entirely stopped using mine for Voice @vhamburger and purely use them as speakers now.  Raised a few times across issues here that they are terrible at this, but much like the PE, it seems to fall on deaf ears.

For voice now, I've just setup the action button on our Samsung Galaxy Watches to be Assist and it works incredibly well.  I use local Whisper/Piper with fallback to OpenAI and it's absolutely Rapid.  I wish PE was capable to provide this too.

RassK, 2025-02-22:
Same here, unusable without a good wake word support.

vhamburger, 2025-02-24:
Hey all - so since no one from Home Assistant or the Voice PE team even got back to this (not sure if just ignoring or too much to do otherwise) I started to experiment around on my own. For the following "fix" you need to adopt your device and _slightly_ edit the firmware yaml - if that is not for you, may be the home assistant folks pick this up and fix it in a later release.
I must say I am a bit disappointed that I did not even get a reaction to this - they claim they get so much good response to the device and that it is awesome - which it is don't get me wrong - but also if you look in the issues part in GitHub you can clearly see that I am not the only one with this issue.

However - "Never give up, never surrender" (quote: Captain Peter Quincy Taggart) - so I started to play with. options and I think a found a combination wich works great for my setting (I am a native German speaker - so it might vary for you ;)

I made the following changes to the original yaml:
```
micro_wake_word:
  id: mww
  models:
    - model: https://github.com/kahrendt/microWakeWord/releases/download/okay_nabu_20241205.4/okay_nabu.json # original: https://github.com/kahrendt/microWakeWord/releases/download/okay_nabu_20241226.3/okay_nabu.json
      id: okay_nabu
      probability_cutoff: 0.78 # Added this to lower detection barrier - may lead to more false positives though
```

So I switched to an older "okay nabu" model by @kahrendt (thanks for all your hard work on that buddy!) Interestingly, the older model seems to be picking up my voice much easier, better and faster. I no more have to "yell" at the device. The lower probability cutoff helps as well.
Note: I have played with lowering the cutoff only, but that didn't create the wanted results. It helped a bit to detect more wake words, but it also lead to a lot of false positives (mostly during movies where someone said something with "Ok" and a German word that is phonetically similar to "nabu" like "nanu, Kanu, Manu, etc..)

Long story short: Since I switched to an older wake word model it improved a lot for me. Until @kahrendt might improve the existing model, I plan to stick to that one. It also proves that my devices microphones are fine (I could verify that easily since all voice commands always work - it is just the wake word pickups that is flawed).

I hope this might help some people. The only "barrier" to this is that you need to adopt the device in ESP Home. If you have never done it, it is quite straightforward. Just remember you probably need to setup your wifi and api encryption key to make it work - but there are plenty of guides on how to do that.

Enjoy your voice PE. I will keep this updated if I find out more... (or another improvement - still need to test it more with the whole family...)

StrandmonYellow, 2025-03-03:
I thought it was just me, but it feels like it got worse indeed with later versions when compared to an erlier one. Is this being picked up? @synesthesiam  🙃

StuartIanNaylor, 2025-03-17:
Its sort of the same here with no reply but the wake words are never going to work well with the dataset and training routines they have that are incredably poor.

https://github.com/kahrendt/microWakeWord/issues/28#issuecomment-2564783183

mirml, 2025-03-21:
Both of my google mini and nest picks wake word far better than voice assistant pe 😔👎

vhamburger, 2025-05-18:
Hey - this topic seems to be highly ignored by the Voice PE team - I wonder why that is?
So maybe I do have a faulty device - it is hard to tell. The other day I set up an M5 Stack Mini and it was picking up "OK Nabu" from across the room when Voice PE did not pick it up? How is that even possible with its tiny microphone...

Is there a way to debug the wake word sound? Can you set it to debug mode or something to examine the audio it picks up. I am really upset now since basically my whole family is rejecting the device as it almost never picks up the wake word - never.
Everybody is revering back to Alexa now and is making fun of it... Kind of sad, as I wanted to get rid of the Amazon spy...

StrandmonYellow, 2025-05-18:
I don't want to judge because the team is doing many things, but indeed this topic has been open for a while. I have to say the wakeword twice or three times allmost every time for it to trigger correctly. I don't know why that is the case and currently do not have the time to dig deeper into this issue unfortunately.

kahrendt, 2025-05-20:
Let me start by apologizing for our delay in responding to this issue! I do understand that the wake word performance can be a frustrating experience with the device, and hopefully we can improve it.

This will be a longer response, so let me first start by sharing some summarized plans to help improve this, and then I will go into more details on the reasoning/difficulties each one has.

First, the next Voice PE firmware will include a [selector for wake word sensitivity](https://github.com/esphome/home-assistant-voice-pe/pull/403). Keep in mind, it being more sensitive means it's more likely to have false accepts where no one said the wake word.

Second, the microphone gain for the audio fed into microWakeWord is too low for some specific devices, causing false rejections. We will share some experimental firmwares to help find the best settings. One firmware will have an auto-tuned gain level and the other will have expose all the settings to experiment with the many different settings on the device. We want to collect feedback on what works and what doesn't. Once we are confident with either the auto-tuning algorithm or better default settings are an improvement, then we will include it in the stable firmware.

Third, the training process for microWakeWord needs to be improved. This is an open-ended problem with no clear approaches that will guarantee better performance, but there are many research papers available on this topic that could potentially help.

-----

Technical details for those curious and those who want to help:

When I tuned the probability cutoffs, I set it so that there were no false accepts on the [Dinner Party corpus](https://www.amazon.science/publications/dipco-dinner-party-corpus), which contains several hours of recordings (from many different microphones) where groups of people converse. This is probably too strict, and having a selector will let you have a choice in the false rejection vs false acceptance rate that is best for you. One thing other note is that the "Hey Mycroft" models and "Hey Jarvis" models don't fully meet the no false-accepts standard I set above. When I trained those two models, the probability cutoffs were only tuned against the first channel on the first microphone unit. The "Okay Nabu" model is tuned against every microphone channel and unit. All future models I train will train will be tuned against all channels and units.
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
StrandmonYellow, 2025-05-20:
@kahrendt Thankyou for the detailed explanation and the amount of work that is going into this! Very much appreciated!

vhamburger, 2025-05-20:
Thanks for this very thorough and detailed reply! Highly appreciated!
Also - if there is any data you need for improvement - let us know and I am sure most of us would be happy to share!

StrandmonYellow, 2025-05-23:
I updated my VPE, I will do some tests this evening!

kahrendt, 2025-05-27:
I have one of the experimental firmwares ready to go for testing. [This PR comment](https://github.com/esphome/home-assistant-voice-pe/pull/410#issuecomment-2912639610) has instructions on how to download and upload the firmware to your VPE.

It attempts to set the gain level so that the RMS sound level is near a target value. It initially targets -75 dB, but there is a number entity to change what it targets. Keep in mind this is meant to change things on long time scales, so it won't necessarily immediately be noticeable. The device needs to be in a quiet room for it to start adapting (quiet room meaning the RMS and peak dB levels are within 20 dB over the span of 30 seconds).

I'd appreciate anyone taking the time to run it and reporting there results! I'm curious if it affects how many false activations and false rejections you experience. If you experiment with the target dB level, please report if any particular setting is better or worse!

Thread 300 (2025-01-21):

[REQUEST] Add an ESP32-C6 as "coprocessor" and "IEEE 802.15.4 radio" module to future voice boards (making a single PCB that have both a ESP32-S3 and a ESP32-C6) so that second SoC can be used as Touchscreen Display Controller and/or Thread Border Router

Hedda, 2025-01-21:
For the next-generation voice satellite board design/schematics please consider also adding another ESP32 SoC to the same PCB board as well as code support for that secondary ESP32 SoC to in the future be used as a Touchscreen Display Controller and/or Thread Border Router. Specifically suggest adding an [ESP32-C6](https://www.espressif.com/en/products/socs/esp32-c6) as a second radio SoC to the same so PCB and make that secondary act as a "co-processor" and "IEEE 802.15.4 radio" module.

The two main real-world use cases I see justify adding an ESP32-C6 SoC as coprocessor and radio module are primarily two-fold:

1. That ESP32-C6 could be used as a display/controller (or offload some other related things to free up resources and make it more future-proof):

2. Perhaps more interestingly, the ESP32-C6 has a built-in IEEE 802.15.4 radio which means it can be used as a "Thread Border Router" (with OpenThread Border Router RCP firmware), to enable a Thread network and another entry point that can be used by Matter standard fabric. So if add this and could get it working as a TBR/OTBR then it would be super easy for users to add multiple Thread Border Routers to their network.

* https://www.home-assistant.io/integrations/thread/
    * https://www.home-assistant.io/integrations/matter/

Regardless if having an integrated "Thread Border Router" would be the most practical new feature or not in the long-run. For the short-term I personally believe that the coolness of having a alternative model variant of Home Assistant voice satellite is the coolest fearute that woulc attract the most new users and developers, as having at least one early model with a a relativly large touchscreen should attract interest for even those users and developers who are not interested in voice.

As such having the suggested secondary ESP32 on the same board should in theory allow support for a capacitive touchscreen display with a local UI without sacrificing resources on the primary ESP32. It would at least be awesome to have a variant of a Home Assistant Voice Satellite with a large touchscreen display (.i.e. something similar in design to the existing Google Nest Hub / Google Home Hub and the Amazon Echo Show products).

  * Check out for example this 7-inch series of capacitive touchscreen displays from Elecrow with display driver for embedded ESP32 (which actually do have a microphone so could potentially be used as-is for development) -> https://www.cnx-software.com/2025/01/17/crowpanel-advance-esp32-s3-displays-with-replaceable-wifi-6-thread-zigbee-lora-and-2-4ghz-wireless-modules/    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

From a marketing point of view it would also allow you to add Thread's Thread Border Router icons on the product box

* https://csa-iot.org/wp-content/uploads/2023/08/Matter-Retail-Education-Presenation.pdf

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

One downside of adding an extra ESP32 (ESP32-C6 or ESP32-H2) it obviously that it would take up some additional space on the PCB and complitate FCC certification a little because of it now having multiple radios, however I do not believe it would add that much larger BOM cost, but the additional possibilities such an extra ESP32 SoC could add should hopefully more than make-up for that slightly higher cost(?).

While I think that it having "Thread Border Router" will be of most interest to many users in the future, and alternativly use case for ESP32-C6 could be to instead use it as a remote Zigbee Coordinator (also known as a Serial-over-IP Zigbee controller adapter) for [Home Assistant's built-in ZHA integration (native Zigbee Gateway)](https://www.home-assistant.io/integrations/zha), see/follow this work-in-progress but note that the ESP Zigbee radio for zigpy is is still very experimental and not yet fully working with ZHA:

* https://github.com/lhespress/zigpy-espzb
  * https://github.com/zigpy/zigpy-cli/pull/45
    * https://github.com/zigpy/zigpy/issues/1052

And yet another option could of course be to also use the ESP32-C6 as a "coprocessor" module a a dedicated Bluetooth Proxy chip with ESPHome:

* https://esphome.io/components/bluetooth_proxy.html

Note that the reason main you want to combine ESP32-S3 and ESP32-C6 is not only to off-load those processes but more importantly so you separate Wi-Fi signals from Thread/Zigbee signals, and that is due to WiFi tendacy to overwhelm and interfer with Thread/Zigbee communication because how they both work. Same goes by the way for WiFi and Bluetooth Low Entergy but it usually is not a great impact on user experience as for Thread/Zigbee:

* https://www.home-assistant.io/integrations/zha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
* https://www.home-assistant.io/integrations/bluetooth#bluetooth-interference-with-other-devices

Anyway, what I think what would make a products like Home Assistant voice satellites perfect as a "Thread Border Router" is that a user can add multiple Thread Border Routers (TBR/OTBR) to their Thread/Matter network for redundacy (using fail-over) and having multiple voice assistant hardware apöliances around thier home is something that many Home Assistant users are likely to have many of and placed all over their home, so having many Thread Border Routers is one of the keys to getting a more robust Thread network.

* https://www.home-assistant.io/integrations/thread/#about-thread-border-routers

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

_Image taken from [the Thread Smart Home Fact Sheet](https://www.threadgroup.org/support#Resources) by the Thread Group. It illustrates the landscape of Matter, Thread, and Border routers. Instead of Matter, you could also see another protocol here, such as HomeKit._

_Unlike other IoT protocols, Thread can use multiple border routers in a single network. This increases wireless coverage and reduces the risk of a single point of failure. Ideal for home automation, with a potentially large number of devices spread over a large area._

Slightly different image here on the threadgroup.org when they describe a Thread based Matter fabric using the same text but also mentioning that _Thread Border Router can be built int many devices such as access points, **smart speakers**, etc._:

* https://www.threadgroup.org/BUILT-FOR-IOT/Smart-Home

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

Also check out this blog which better describe what a Thread Border Router actually is and why it is very good to have many:

* https://www.threadgroup.org/news-events/blog/ID/356/WHAT-IS-A-THREAD-BORDER-ROUTER-AND-HOW-IS-IT-DIFFERENT-FROM-A-HUB-OR-BRIDGE

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

As proof-of-concept for the idea of using a ESP32-S3 + ESP32-H2 combination board made for this purpose check out the "**_ESP Thread Border Router_**" board which is an official Espressif official SDK reference hardware for this purpose (can that use used as either Thread Border Router or as a remote Zigbee Coordinator):

* https://openthread.io/guides/border-router/espressif-esp32

  * https://www.sparkfun.com/products/25497

Not tested myself but suposedly you can already get those working with Home Assistant's Thread integration:

* https://www.youtube.com/watch?v=nHH7j--lfDo

  * https://github.com/home-assistant-libs/python-otbr-api/issues/61

Development is primarily being done with Espressif's ESP Thread Border Router SDK hardware (based on ESP32-H2-MINI-1 module):

- https://docs.espressif.com/projects/esp-thread-br/en/latest/
  - https://github.com/espressif/esp-zigbee-sdk/tree/main/examples/esp_zigbee_gateway
    - https://github.com/espressif/esp-thread-br
    - https://github.com/espressif/esp-idf/tree/master/examples/openthread/ot_br
    - https://openthread.io/guides/border-router/espressif-esp32

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

OpenThread Border Router Example as in a similar two-SoC setup combining both a ESP32-S3 and ESP32-H2 in the same solution:

* https://github.com/espressif/esp-idf/tree/master/examples/openthread/ot_br

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

Hedda, 2025-03-11:
For reference, FYI, looks like [clydebarrow](https://github.com/clydebarrow) is working on adding a serial packet transport platform to ESPHome which could maybe be used to facilitate sending data between two ESPHome devices?

- https://github.com/esphome/esphome/pull/8214

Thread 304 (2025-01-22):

new Voice PE - unable to listen (deaf)

frostworx, 2025-01-22:
I received my Voice PE today.
It was immediately detected after enabling BLE.
Adding it to the network worked straightforward.

Initially it was not allowed to access the internet, but did not complain.

Problem:

I am not allowed to test the "Okay Nabu" in the setup wizard, as the device was set to "deaf":

```
Sag „Okay Nabu“, um das Gerät zu aktivieren

Die Einrichtung wird fortgesetzt, sobald das Gerät aktiviert ist.

Dein Gerät ist taubgeschaltet

Bitte hebe die Taubschaltung deines Geräts auf, um fortzufahren.
```

Button presses are registered, but don't make the device listen.

toggling `home_assistant_voice_XXXXX_mute` doesn't help as well.

after enabling internet access in the firewall, a firmware update was found which flashed without any problems _(Firmware: 25.1.0 (ESPHome 2024.12.2)_

the problem persists though and is reproducible when re-entering the "Voice Assistant Set Up"

no idea if voice testing in the debug mode is implemented (especially as only text mode is documented here https://www.home-assistant.io/voice_control/troubleshooting/) but it is greyed out here.

12 entities were created, HA switches do work, button presses on the device as well.
`binary.sensor.home_assistant_voice_XXXXX_assist_in_arbeit `is disabled, in case that is important.

no idea how to proceed from here without deeper troubleshooting.
would be nice if someone has a clue.

dgolovach, 2025-01-22:
Same here, debugging via serial shows that nic doesn't seem to work
https://github.com/esphome/home-assistant-voice-pe/issues/303

frostworx, 2025-01-23:
thank you for confirming, @dgolovach! (sorry for the late reply, I did not get any notification email...).

Just wanted to update the issue and mention that removing the device from HA, factory resetting it and adding it again into HA didn't help as well.

So no need to try the steps from [this manual](https://voice-pe.home-assistant.io/guides/reset/)

cogneato, 2025-01-23:
Is the physical mute switch toggled? I saw someone else who thought it was a power switch.

frostworx, 2025-01-23:
waaaah, that's the first thing I tried yesterday, but now it just worked indeed! a bit embarrassing tbh...
Thank you so much, I guess I would not have tried it again so fast :)

frostworx, 2025-01-23:
@dgolovach
As you have a separate issue open anyway, I'll close here. I wish you good luck with your (likely different) problem!

Closed 2025-01-23.

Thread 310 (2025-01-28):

Music (file) starts then stops

BillBlight, 2025-01-28:
The media pipeline's audio decoder encountered an error.

Have tested with multiple formats, same result, occasionally a file will play completely but about 1 in 25

Have tried with just Media and Music Assistant, same results.

relevant log section:

`[16:01:02][D][debug:035]: ESPHome version 2024.12.4
[16:01:02][D][debug:039]: Free Heap Size: 122960 bytes
[16:01:02][D][debug:217]: Chip: Model=ESP32-S3, Features=WIFI_BGN,BLE, Cores=2, Revision=2
[16:01:02][D][debug:226]: ESP-IDF Version: 5.1.5
[16:01:02][D][debug:231]: EFuse MAC: 20:F8:3B:09:29:38
[16:01:02][D][debug:137]: Reset Reason: Software Reset Digital Core
[16:01:02][D][debug:279]: Wakeup Reason: Unknown
[16:01:29][D][media_player:080]: 'Media Player' - Setting
[16:01:29][D][media_player:087]:   Media URL: http://172.16.16.10:8097/flow/media_player.jarvis_1_media_player/c5d7ca9f337d4d6488419cfeaa49f0f6.mp3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
[16:01:29][D][ring_buffer:034]: Created ring buffer with size 48000
[16:01:29][D][ring_buffer:034]: Created ring buffer with size 48000
[16:01:29][D][ring_buffer:034]: Created ring buffer with size 65536
[16:01:29][D][ring_buffer:034]: Created ring buffer with size 65536
[16:01:29][D][nabu_media_player.pipeline:173]: Reading MP3 file type
[16:01:31][D][nabu_media_player.pipeline:184]: Decoded audio has 2 channels, 48000 Hz sample rate, and 16 bits per sample
[16:01:31][D][ring_buffer:034][speaker_task]: Created ring buffer with size 19200
[16:01:31][D][i2s_audio.speaker:111]: Starting Speaker
[16:01:31][D][i2s_audio.speaker:116]: Started Speaker
[16:01:32][E][nabu_media_player:299]: The media pipeline's audio decoder encountered an error.
[16:03:36][D][media_player:080]: 'Media Player' - Setting
[16:03:36][D][media_player:087]:   Media URL: http://172.16.16.10:8097/flow/media_player.jarvis_1_media_player/c5d7ca9f337d4d6488419cfeaa49f0f6.mp3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
[16:03:36][D][nabu_media_player.pipeline:173]: Reading MP3 file type
[16:03:40][D][nabu_media_player.pipeline:184]: Decoded audio has 2 channels, 48000 Hz sample rate, and 16 bits per sample
[16:03:41][E][nabu_media_player:299]: The media pipeline's audio decoder encountered an error.
[16:03:52][D][media_player:080]: 'Media Player' - Setting
[16:03:52][D][media_player:087]:   Media URL: http://172.16.16.10:8097/flow/media_player.jarvis_1_media_player/37af76f39f5e4a15b02828fb4ee05ddc.mp3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
[16:03:52][D][nabu_media_player.pipeline:173]: Reading MP3 file type
[16:03:54][D][nabu_media_player.pipeline:184]: Decoded audio has 2 channels, 48000 Hz sample rate, and 16 bits per sample
[16:03:54][E][nabu_media_player:299]: The media pipeline's audio decoder encountered an error.
[16:03:58][D][media_player:080]: 'Media Player' - Setting
[16:03:58][D][media_player:087]:   Media URL: http://172.16.16.10:8097/flow/media_player.jarvis_1_media_player/be097d8151334db2bef61b3f979d11d1.mp3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
[16:03:58][D][nabu_media_player.pipeline:173]: Reading MP3 file type
[16:04:00][D][nabu_media_player.pipeline:184]: Decoded audio has 2 channels, 48000 Hz sample rate, and 16 bits per sample
[16:04:01][E][nabu_media_player:299]: The media pipeline's audio decoder encountered an error.
[16:09:45][D][media_player:080]: 'Media Player' - Setting
[16:09:45][D][media_player:087]:   Media URL: http://172.16.16.10:8097/flow/media_player.jarvis_1_media_player/1bc3c244b0604927bdb5c70837aa2003.mp3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
[16:09:45][D][nabu_media_player.pipeline:173]: Reading MP3 file type
[16:09:46][D][nabu_media_player.pipeline:184]: Decoded audio has 2 channels, 48000 Hz sample rate, and 16 bits per sample
[16:10:54][D][media_player:080]: 'Media Player' - Setting
[16:10:54][D][media_player:087]:   Media URL: http://172.16.16.10:8097/flow/media_player.jarvis_1_media_player/3e56bc6baf344438bfa0c0e3abf76d6b.mp3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
[16:10:54][W][component:237]: Component nabu.media_player took a long time for an operation (75 ms).
[16:10:54][W][component:238]: Components should block for at most 30 ms.
[16:10:54][D][nabu_media_player.pipeline:173]: Reading MP3 file type
[16:10:56][D][nabu_media_player.pipeline:184]: Decoded audio has 2 channels, 48000 Hz sample rate, and 16 bits per sample
[16:11:24][D][media_player:080]: 'Media Player' - Setting
[16:11:24][D][media_player:087]:   Media URL: http://172.16.16.10:8097/flow/media_player.jarvis_1_media_player/1b07dfce94564203b42382fa4be2f6f7.mp3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
[16:11:25][D][nabu_media_player.pipeline:173]: Reading MP3 file type
[16:11:27][D][nabu_media_player.pipeline:184]: Decoded audio has 2 channels, 48000 Hz sample rate, and 16 bits per sample
[16:11:29][E][nabu_media_player:299]: The media pipeline's audio decoder encountered an error.
`

efschu, 2025-04-16:
same for me

kahrendt, 2025-05-22:
Thanks for reporting! A potential fix is included in the latest beta firmware (25.5). If it continues to be a problem with that VPE firmware, then please open a new issue.

Closed 2025-05-22.

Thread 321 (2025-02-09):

Home Assistant Voice PE Microphone Not Responding to Wake Word Activation

BlueMahib, 2025-02-09:
I followed the setup instructions for adding the Home Assistant Voice PE Microphone to my Home Assistant system. However, the device does not respond to speech for wake word activation. I have tried multiple wake words (Okay Nabu, Hey Jarvis, Hey Mycroft), but none seem to work.

Steps Taken:

- Successfully added the device to Home Assistant.
- Verified that the device appears in the Home Assistant UI.
- Attempted multiple wake words with no response.
- Repeated the setup process multiple times (factory reset) without success.

Expected Behavior:

- The device should detect the wake word as expected.

Actual Behavior:

- The device does not respond to any wake words, even after multiple attempts.

Would appreciate any troubleshooting guidance or insights from others who have experienced a similar issue.

fly2806, 2025-02-09:
Hello everyone, I have the same problem and an additional issue:

- I was able to connect the Voice PE to Home Assistant via the setup process. I can use HA to control the LED ring, for example.

- The microphones do not work at all. They do not respond to the wake word, nor does the voice recognition work. They appear to be muted, even though they are not (neither via the switch nor via the software).

- Audio via the loudspeaker does not work. The playback is so slow and distorted that you can't understand anything. This applies to text to speech, playback of music and even if you perform a reset (press and hold the button), the announcement cannot be understood.

I have already reinstalled the software. Unfortunately no improvement. Any support is welcome. Let me know if there is anything I can do to help with more information, testing, etc.

lstanton428, 2025-02-10:
I too am having this issue. In the logs (viewing from here https://esphome.github.io/home-assistant-voice-pe/) I see:
```
...
[13:17:30][E][voice_kit:026]: Communication with Voice Kit failed
[13:17:30][E][component:119]: Component voice_kit was marked as failed.
[13:17:30][E][component:164]: Component voice_kit set Error flag: unspecified
...
```
And then
```
...
[13:17:41][E][component:082]:   Component voice_kit is marked FAILED
...
```

lstanton428, 2025-03-26:
Yes, I was also able to have my hardware replaced.

BlueMahib, 2025-03-29:
Closing this issue as the hardware needs to be replaced.

Closed 2025-03-29.

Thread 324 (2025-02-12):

Not compiling on esphome beta

tbrasser, 2025-02-12:
```yaml
substitutions:
  name: home-assistant-voice-0905d2
  friendly_name: Eetkamer Voice
packages:
  Nabu Casa.Home Assistant Voice PE: github://esphome/home-assistant-voice-pe/home-assistant-voice.yaml@dev
esphome:
  name: ${name}
  name_add_mac_suffix: false
  friendly_name: ${friendly_name}

wifi:
  ssid: !secret wifi_ssid
  password: !secret wifi_password
```
```
INFO ESPHome 2025.2.0b1
INFO Reading configuration /config/esphome/home-assistant-voice-0905d2.yaml...
INFO Updating https://github.com/esphome/home-assistant-voice-pe@dev
WARNING GPIO0 is a strapping PIN and should only be used for I/O with care.
Attaching external pullup/down resistors to strapping pins can cause unexpected failures.
See https://esphome.io/guides/faq.html#why-am-i-getting-a-warning-about-strapping-pins
WARNING GPIO3 is a strapping PIN and should only be used for I/O with care.
Attaching external pullup/down resistors to strapping pins can cause unexpected failures.
See https://esphome.io/guides/faq.html#why-am-i-getting-a-warning-about-strapping-pins
Failed config light.esp32_rmt_led_strip: [source /data/packages/f1018e04/home-assistant-voice.yaml:556]
platform: esp32_rmt_led_strip
id: leds_internal
pin: GPIO21
This feature is not available for the IDF framework version 5.
rmt_channel: 1
num_leds: 12
rgb_order: GRB
chipset: WS2812
default_transition_length: 0ms
power_supply: led_power
```

aryajuanda, 2025-02-13:
the `rmt_channel: 1` is not available in new idf framework, need to be removed

tbrasser, 2025-02-13:
after fixing that (using !remove) I get:

```
Traceback (most recent call last):
File "/usr/local/bin/esphome", line 8, in <module> sys.exit(main()) ^^^^^^
File "/esphome/esphome/__main__.py", line 1049, in main return run_esphome(sys.argv) ^^^^^^^^^^^^^^^^^^^^^
File "/esphome/esphome/__main__.py", line 1036, in run_esphome rc = POST_CONFIG_ACTIONS[args.command](args, config) ^^^^^^^^^^^^^^^^^^^^^^^^^^^^^^^^^^^^^^^^^^^^^^^
File "/esphome/esphome/__main__.py", line 503, in command_run exit_code = write_cpp(config) ^^^^^^^^^^^^^^^^^
File "/esphome/esphome/__main__.py", line 212, in write_cpp generate_cpp_contents(config)
File "/esphome/esphome/__main__.py", line 224, in generate_cpp_contents CORE.flush_tasks()
File "/esphome/esphome/core/__init__.py", line 674, in flush_tasks self.event_loop.flush_tasks()
File "/esphome/esphome/coroutine.py", line 246, in flush_tasks next(task.iterator)
File "/esphome/esphome/__main__.py", line 204, in wrapped await coro(conf)
File "/esphome/esphome/components/audio/__init__.py", line 121, in to_code cg.add_library("esphome/esp-audio-libs", "1.1.1")
File "/esphome/esphome/cpp_generator.py", line 603, in add_library CORE.add_library(Library(name, version, repository))
File "/esphome/esphome/core/__init__.py", line 748, in add_library raise ValueError( ValueError:
Version pinning failed!
Libraries esphome/esp-audio-libs@1.1.1 and esphome/esp-audio-libs@1.0.0 requested with conflicting versions!
```

goofy1988, 2025-02-13:
Hey there,

i have the same issue.

Ive got the same error message when compiling. My try to remote the LED and Add a new one without the rmt_channel: 1 gave me the same error as you mentioned:

INFO ESPHome 2025.2.0b2
INFO Reading configuration /config/esphome/home-assistant-voice-090fa9.yaml...
INFO Updating https://github.com/esphome/home-assistant-voice-pe@dev
WARNING 'wz_nabu_voiceassistant': Using the '_' (underscore) character in the hostname is discouraged as it can cause problems with some DHCP and local name services. For more information, see https://esphome.io/guides/faq.html#why-shouldn-t-i-use-underscores-in-my-device-name
WARNING GPIO3 is a strapping PIN and should only be used for I/O with care.
Attaching external pullup/down resistors to strapping pins can cause unexpected failures.
See https://esphome.io/guides/faq.html#why-am-i-getting-a-warning-about-strapping-pins
WARNING GPIO45 is a strapping PIN and should only be used for I/O with care.
Attaching external pullup/down resistors to strapping pins can cause unexpected failures.
See https://esphome.io/guides/faq.html#why-am-i-getting-a-warning-about-strapping-pins
INFO Generating C++ source...
Traceback (most recent call last):
  File "/usr/local/bin/esphome", line 8, in <module>
    sys.exit(main())
             ^^^^^^
  File "/esphome/esphome/__main__.py", line 1049, in main
    return run_esphome(sys.argv)
           ^^^^^^^^^^^^^^^^^^^^^
  File "/esphome/esphome/__main__.py", line 1036, in run_esphome
    rc = POST_CONFIG_ACTIONS[args.command](args, config)
         ^^^^^^^^^^^^^^^^^^^^^^^^^^^^^^^^^^^^^^^^^^^^^^^
  File "/esphome/esphome/__main__.py", line 503, in command_run
    exit_code = write_cpp(config)
                ^^^^^^^^^^^^^^^^^
  File "/esphome/esphome/__main__.py", line 212, in write_cpp
    generate_cpp_contents(config)
  File "/esphome/esphome/__main__.py", line 224, in generate_cpp_contents
    CORE.flush_tasks()
  File "/esphome/esphome/core/__init__.py", line 674, in flush_tasks
    self.event_loop.flush_tasks()
  File "/esphome/esphome/coroutine.py", line 246, in flush_tasks
    next(task.iterator)
  File "/esphome/esphome/__main__.py", line 204, in wrapped
    await coro(conf)
  File "/esphome/esphome/components/audio/__init__.py", line 121, in to_code
    cg.add_library("esphome/esp-audio-libs", "1.1.1")
  File "/esphome/esphome/cpp_generator.py", line 603, in add_library
    CORE.add_library(Library(name, version, repository))
  File "/esphome/esphome/core/__init__.py", line 748, in add_library
    raise ValueError(
ValueError: Version pinning failed! Libraries esphome/esp-audio-libs@1.1.1 and esphome/esp-audio-libs@1.0.0 requested with conflicting versions!

_____________________________________________

This is the remove and readd part in my code:

light:

  - id: !remove leds_internal

  # Hardware LED ring. Not used because remapping needed
  - platform: esp32_rmt_led_strip
    id: leds_internal
    pin: GPIO21
    #rmt_channel: 1
    num_leds: 12
    rgb_order: GRB
    chipset: WS2812
    default_transition_length: 0ms
    power_supply: led_power

rccoleman, 2025-02-17:
Simply bumping the `esp-audio-libs` dependency to 1.1.1 in https://github.com/esphome/home-assistant-voice-pe/blob/dev/esphome/components/nabu/media_player.py isn't enough (generates more errors during the compilation, so hopefully there's a PR out there to make the Voice PE config functional with the new ESPHome beta.

[esphome-2025.2-beta-voice-pe.txt](https://github.com/user-attachments/files/18832481/esphome-2025.2-beta-voice-pe.txt)

matze19999, 2025-02-19:
This now also happens on ESPHome Stable. Can we only use esphome/esp-audio-libs@1.0.0?

Magicpulse, 2025-02-19:
Upgraded ESPHome to 2025.2.0 and I confirm this happens.

vhamburger, 2025-02-19:
Same error here - seems the yaml / firmware needs some fixing please! (pretty please?)

kahrendt, 2025-02-19:
The yaml config has been updated in the last hour or two with the required change to make it build on ESPHome 2025.2.0. A new beta will be published soon as well if you haven't taken control of the firmware.

Thanks for reporting!

rccoleman, 2025-02-19:
Working fine for me, thanks!

Closed 2025-02-19.

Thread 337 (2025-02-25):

Device stops playing stream and returns to idle at random intervals.

nevvob, 2025-02-25:
Whilst playing a radio stream through the device after a short, usually random between 5-15 minutes the music stops and the device switches back to Idle, it does this regardless of whether I trigger it from an automation, or select the radio station manually through the browser, it also does this for music being streamed from a samba share on the local network.

I have made sure it is running the latest firmware.

Please see https://community.home-assistant.io/t/voice-assistant-pe-randomly-stops-playing-radio-station/840851 for other users experiencing the same.

Happy to help debug.

Thanks

kahrendt, 2025-03-04:
Could you try using Music Assistant to send the audio instead of using the radio browser in HA and reporting back if it is still problematic?

bradwick, 2025-03-04:
I also have this issue. I exclusively play filesystem content from Music Assistant. Most recent stable versions of PE firmware, Music Assistant, and Home Assistant.

nevvob, 2025-03-05:
Hi - yes it happens if I stream files from the SSD on my Home Assistant Yellow as well.

jgdf42, 2025-04-12:
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

I'm having the same issue playing back locally stored mp3. I retired my google home speakers to use voice device with an external speaker and the results are worse due to this bug.

tommyjlong, 2025-04-15:
Playing from the radio to the Voice PE use to work (forget the release but around 25.1.0 when I last tested), but now it only plays a couple of seconds and fails (this is after the VAPE has been running a couple of days).

Here is the versions:
```
[17:53:00.842][I][app:100]: ESPHome version 2025.3.3 compiled on Apr  1 2025, 00:42:56
[17:53:00.842][I][app:102]: Project Nabu Casa.Home Assistant Voice PE version 25.3.4
```
Here is the error
```
[17:43:23.731][D][media_player:074]: 'Media Player' - Setting
[17:43:23.733][D][media_player:081]:   Media URL: https://MY_HA_URL/api/esphome/ffmpeg_proxy/af4c9c675d7cb094c1dac9ec15481fa6/RP8fjACrQz0R87liRNxVMA.flac
[17:43:23.734][D][speaker_media_player:426]: State changed to PLAYING
[17:43:24.298][D][esp-idf:000][med_read]: I (532236525) esp-x509-crt-bundle: Certificate validated

[17:43:24.429][D][ring_buffer:034][med_read]: Created ring buffer with size 1000000
[17:43:24.429][D][speaker_media_player.pipeline:114]: Reading FLAC file type
[17:43:27.879][D][speaker_media_player.pipeline:124]: Decoded audio has 2 channels, 48000 Hz sample rate, and 16 bits per sample
[17:43:37.069][D][ring_buffer:034]: Created ring buffer with size 19200
[17:43:37.070][D][speaker_mixer:310]: Starting speaker mixer
[17:43:37.083][D][speaker_mixer:318]: Started speaker mixer
[17:43:38.823][E][speaker_media_player:330]: The media pipeline's audio decoder encountered an error.
[17:43:40.043][D][speaker_media_player:426]: State changed to IDLE
[17:43:40.044][D][speaker_mixer:323]: Stopping speaker mixer
```
Here is the action I use for testing purposes:
```
action: media_player.play_media
data:
  media_content_id: >-
    https://samcloud.spacial.com/api/listen?sid=111415&rid=194939&f=mp3,any&br=128000,any&m=sc
  media_content_type: audio/mpeg
target:
  device_id: MY_HA_VAPE_DEVICE_ID
```

If I power cycle the VAPE, it works again, but sometimes only for a couple of minutes, and then rolls over without any errors in the logs.
(BTW, I'm connecting to VAPE using aioesphomeapi-logs to capture logs)

Mirkbot, 2025-05-10:
I am experiencing the same issue. It used to work for me (unfortunately I can't tell exactly with which update it stopped), but now the voice PE goes to idle and pauses playback after a couple of seconds every time I try to play some media.

jszust, 2025-05-14:
I’m having a very similar issue. My voice PE will play the first song in a Tidal playlist then will go idle and the playlist queue clears and no other songs play

xkjq, 2025-08-03:
Just to confirm this issue still occurs on 2025.7.0

Happy to provide logs if someone can guide me how to get them.

2600box, 2025-08-07:
Hello, I found this thread searching for the same issue, except I don't don't use voice PE or music assistant or anything like that as far as I know.

I have a dlna speaker, and have home assistant media player, play a long nature sounds file from the media folder, on single repeat.

At some point randomly, it returns to idle. Can be an hour or 36 hours...

I am thinking to solve this by monitoring for the idle status and restarting automatically at that time.

This would appear to be a home assistant core issue? Or a coincidence?

Closed 2025-05-21.

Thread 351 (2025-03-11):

[REQUEST] Extend and improve ESPHome's native media player(s) to make it/them have both high-quality audio output and advanced music playback features similar to Squeezelight client?

Hedda, 2025-03-11:
Do Nabu Casa developers have a plan to further improve ESPHome's native media player(s) and music streaming client playback?

Are there any ongoing development efforts or roadmap to make ESPHome native media player have much more advanced music playback features like multi-room audio grouping and stereo pair support similar to Squeezelight client to be able to make Home Assistant Voice Preview Edition hardware and similar products based on ESPHome and ESP32 + XMOS act like a reference that is capable of replacing other so-called "music streamers" (i.e. network music streamer receivers meant for)?

Could there be a roadmap goal of improving ESPHome native media player(s) to make it have feature parity with competing open-source music streaming clients like Squeezelite and Snapcast or similar?

PS: My reason to hope and push for such efforts are partially because all of Google's Chromecast Audio (audio-only Google Cast device) dongle just now stopped working globally for everyone in the whole world as there are no alternatives which are inexpensive and have similal feature set, like multi-room audio grouping and stereo pair support. So for exsiting Chromecast Audio users there is currently no equivalent Google Cast audio-only product you can buy as a replacement as a Google Cast audio (music) music receiver and network-attached audio-jack output adapter product, so many users are stuck in limbo now. For more information see this Home Assistant community forum thread:

* https://community.home-assistant.io/t/chromecast-audio-and-2nd-gen-chromecast-video-all-stopped-working-worldwide-in-google-home-with-untrusted-device-error/861989

janhense, 2025-03-11:
Maybe you can use the Music Assistant Addon https://www.home-assistant.io/blog/2024/05/09/music-assistant-2/ . There is also a blueprint for voice control [https://github.com/music-assistant/voice-support]

Hedda, 2025-03-12:
> Maybe you can use the Music Assistant Addon https://www.home-assistant.io/blog/2024/05/09/music-assistant-2/ .

Not by itself as Music Assistant depends on what media player features are supported by the "Player Provider" on the client-side, see:

* https://www.music-assistant.io/player-support/

As the fact is ESPHome's native media player(s) does not yet support those features (like audio grouping and stereo pair, etc).. See:

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

Hedda, 2025-03-18:
> I spoke to the music assistant team and they mentioned they do have plans to get voice PE working as a multi-room setup with snapcast but I don't think there is a timeline.
>
> You can see it here https://github.com/orgs/music-assistant/discussions/3391

Yes have seen that, though again noted that support for Squeezelite client/  Slim Protocol (a.k.a. SlimProto) is currently the best today:

* https://www.music-assistant.io/player-support/squeezelite/

Subsonic/Airsonic could be another open-source alternative today, but Music Assistant do not yet have an Subsonic player provider:

* https://www.music-assistant.io/player-support/

PS: Long-term for the future I hope that "Matter Casting" also will be extended upstream too and adopted by the whole industry:

* https://github.com/esphome/home-assistant-voice-pe/issues/353

kahrendt, 2025-05-22:
This is a more general ESPHome feature request rather than a VPE specific request, so I'm going to close it here.

We are working on adding synced audio support to ESPHome, but it is in the early stages. One task related to it as already available on our project board: https://github.com/orgs/esphome/projects/7?pane=issue&itemId=109541647&issue=esphome%7Cbacklog%7C20

Closed 2025-05-22.

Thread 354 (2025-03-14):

Home Assistant Voice PE microphone not responding to wake word activation; no sound through media player

bwip, 2025-03-14:
Similar to #321

Successfully added the device to Home Assistant.
It worked for one day.

After one day, no response on the wake word.

Verified that the device appears in the Home Assistant UI.
Attempted multiple wake words with no response.
Repeated the setup process multiple times (factory reset) without success.

The device is controlable via HA (led ring, ...).

The media player and voice inputs do not work and produce a lot of errors in the esp log:

```
[23:17:25][W][i2s_audio.speaker:143]: Error writing to I2S: ESP_ERR_INVALID_SIZE
[23:17:25][W][i2s_audio.speaker:143]: Error writing to I2S: ESP_ERR_INVALID_SIZE
[23:17:25][W][i2s_audio.speaker:143]: Error writing to I2S: ESP_ERR_INVALID_SIZE
[23:17:25][W][i2s_audio.speaker:143]: Error writing to I2S: ESP_ERR_INVALID_SIZE
[23:17:26][W][i2s_audio.speaker:143]: Error writing to I2S: ESP_ERR_INVALID_SIZE
[23:17:26][W][i2s_audio.speaker:143]: Error writing to I2S: ESP_ERR_INVALID_SIZE
[23:17:26][W][i2s_audio.speaker:143]: Error writing to I2S: ESP_ERR_INVALID_SIZE
[23:17:26][W][i2s_audio.speaker:143]: Error writing to I2S: ESP_ERR_INVALID_SIZE
[23:17:26][D][voice_assistant:646]: Event Type: 0
[23:17:26][E][voice_assistant:783]: Error: stt-stream-failed - speech-to-text failed
[23:17:26][D][voice_assistant:628]: Signaling stop...
[23:17:26][D][voice_assistant:509]: State changed from STREAMING_MICROPHONE to STOP_MICROPHONE
[23:17:26][D][voice_assistant:516]: Desired state set to IDLE
[23:17:26][D][voice_assistant:509]: State changed from STOP_MICROPHONE to STOPPING_MICROPHONE
[23:17:26][D][light:036]: 'voice_assistant_leds' Setting:
[23:17:26][D][light:051]:   Brightness: 76%
[23:17:26][D][light:058]:   Red: 100%, Green: 0%, Blue: 0%
[23:17:26][D][light:109]:   Effect: 'Error'
[23:17:26][D][voice_assistant:646]: Event Type: 2
[23:17:26][D][voice_assistant:742]: Assist Pipeline ended
[23:17:26][D][voice_assistant:509]: State changed from STOPPING_MICROPHONE to IDLE
[23:17:26][D][voice_assistant:509]: State changed from IDLE to IDLE
[23:17:26][W][i2s_audio.speaker:143]: Error writing to I2S: ESP_ERR_INVALID_SIZE
[23:17:26][W][i2s_audio.speaker:143]: Error writing to I2S: ESP_ERR_INVALID_SIZE
[23:17:26][W][i2s_audio.speaker:143]: Error writing to I2S: ESP_ERR_INVALID_SIZE
[23:17:26][D][power_supply:033]: Enabling power supply.
[23:17:26][W][i2s_audio.speaker:143]: Error writing to I2S: ESP_ERR_INVALID_SIZE
[23:17:26][D][power_supply:033]: Enabling power supply.
[23:17:27][D][power_supply:033]: Enabling power supply.
[23:17:27][D][light:036]: 'voice_assistant_leds' Setting:
[23:17:27][D][light:047]:   State: OFF
[23:17:27][D][light:109]:   Effect: 'None'
[23:17:37][D][power_supply:048]: Disabling power supply.
```

[esp-web-tools-logs.txt](https://github.com/user-attachments/files/19255388/esp-web-tools-logs.txt)

Is this a hardware problem?

BR

kahrendt, 2025-03-17:
Could you capture and post the logs right after rebooting showing all the setup? I'm suspecting a hardware failure where the XMOS chip isn't running and so it isn't generating a clock signal and the I2S driver can't send or receive audio data.

bwip, 2025-03-17:
Thank you for your interest, here is a log with a reboot: [esp-web-tools-logs (1).txt](https://github.com/user-attachments/files/19299229/esp-web-tools-logs.1.txt)

I returned the unit today and wait for a new one. The short time I could test it I was happy with it, especially with the good wake word detection.

kahrendt, 2025-03-17:
> Thank you for your interest, here is a log with a reboot: [esp-web-tools-logs (1).txt](https://github.com/user-attachments/files/19299229/esp-web-tools-logs.1.txt)
>
> I returned the unit today and wait for a new one. The short time I could test it I was happy with it, especially with the good wake word detection.

Thanks for those logs, they confirm a hardware failure with the XMOS chip since it says the voice_kit component failed. I'm glad to hear you returned it and requested a new one, as that should fix the problem.

ahmedsamer, 2025-04-18:
I'm facing the same problem, should I return it as well?

Closed 2025-03-17.

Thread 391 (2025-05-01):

Voice PE - hardware/molding issue causes mono playback with 3.5mm plug

whitty, 2025-05-01:
Apologies if this is the wrong place to log such an issue - this is physical issue with the Voice PE, and I could not find another place to log it, to ensure feedback gets to the right people before the next hardware revision.

An issue is discussed on the community Discourse:  https://community.home-assistant.io/t/voice-assistant-pe-voice-is-left-channel-only-music-is-dual-channel-stereo/837322

Description of Issue:

Mono playback can be heard when playing music through the 3.5mm connection.  You'll need music or sound files with clear left/right channels to demonstrate this.

The cause is summarised clearly [here](https://community.home-assistant.io/t/voice-assistant-pe-voice-is-left-channel-only-music-is-dual-channel-stereo/837322/2):

>  The plastic case of the VAPE has a hole that does not allow the connector housing of a 3.5 mm male to protrude inside. And female on the PCB inside is not close enough to the front so the receptable protrude. The result is that most 3.5 mm jacks do not properly connect.

The workaround proposed for users is to drill out the area as [shown here](https://community.home-assistant.io/t/voice-assistant-pe-voice-is-left-channel-only-music-is-dual-channel-stereo/837322/7)

Proposed solution:

The next revision of hardware should rework the plastic molding/recessing to allow the 3.5mm jack to be fully inserted.

kahrendt, 2025-05-01:
Thanks for reporting! More recently manufactured batches of the VPE have moved the 3.5mm connector closer to the edge of the PCB to minimize this issue.

nikita-squirrel, 2025-05-29:
This is an inexpensive non-destructive solution for VPEs that have the 3.5mm jack socket connection problem. [https://www.aliexpress.com/item/1005003232102582.html](url)

I had the problem with a new VPE purchased mid May 2025 but I realised that it was a fat jack plug that was snagging on the case rather than matching the slim jack socket. As it would not seat properly, it was to be expected that it would only work through the left channel. I found this cable on AliExpress and now that it has arrived, can confirm that the plug is slim enough to match the socket and thus does not snag the case.  The VPE is now playing back through both channels on my B&W Zeppelin and sounds awesome. I am delighted. Not only are the plugs slender, but also the cable is very lightweight and flexible. It was also coiled nicely in its package so does not have the awkward stiff kinks of the fat cable I tried first, that had been folded back on itself and tied with a wire fastener.

Closed 2025-05-01.

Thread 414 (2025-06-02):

Stuttering when getting a response sounds like it's buffering

kip3435423, 2025-06-02:
Just started happening when I get a response it sounds like it's buffering. It will stop mid way through a word and then continue.

I tested sending the same responses to other media devices no issues just to the voice PE

Installed lastest firmware

Firmware: 25.5.2 (ESPHome 2025.5.1)

kip3435423, 2025-06-02:
# [SOLVED] Voice PE constantly buffering on UniFi? Try this bandwidth fix

So my Voice PE has been driving me absolutely nuts with constant audio buffering. Like, every single TTS announcement would stutter and cut out. I was about ready to return it thinking it was broken.

## What was happening
- Audio buffering on literally everything - TTS, media, you name it
- Ping times all over the map (sometimes 9ms, sometimes 400ms+)
- UniFi controller showing "Poor Signal Balance" even though signal was strong
- Could upload fine but download speeds were garbage

## My setup
UniFi Dream Router 7 with a U6 Pro AP. Everything else on my network works perfectly.

## Turns out it's not broken
After way too much troubleshooting, figured out this is actually a known issue with ESP32 devices on UniFi networks. The access points basically send data too fast for the ESP32 to keep up with, so it starts dropping packets and everything goes to hell.

## The fix that actually worked
Create a bandwidth profile and limit the Voice PE:

1. UniFi Controller → Settings → Profiles → WiFi Speed Limit
2. Make a new one:
   - Name it whatever (I used "ESP32 Fix")
   - Set both download AND upload to **1 Mbps**
3. Go to Network → Clients, find your Voice PE, and apply that profile

## Why this works
1 Mbps is way more than enough for audio (only needs like 64k), but it stops UniFi from overwhelming the poor little ESP32 with data bursts.

## Results
Ping went from crazy variable (9-400ms) to super consistent (5-35ms). Zero buffering now, even during continuous playback.

I tried 100k first but the audio quality sucked. 1 Mbps is the sweet spot.

## Other stuff to check
- PMF should be "Optional" not "Required"
- Minimum data rate set to 1 Mbps not Auto
- Turn off band steering if you haven't already

Honestly can't believe something this simple fixed it. The Voice PE works great now - turns out it was never defective, just UniFi being too aggressive with data delivery.

Hope this saves someone else the headache I went through!

ethanbergstrom, 2025-09-27:
I had similar issues after upgrading firmware from 25.6.0 to 25.9.0, but not on a UniFi network. My case was with a Linksys EA6350v3 access point running OpenWrt 23.05.6.

Music streaming and text-to-speech were stuttering almost immediately after upgrading, when I'd not had issues prior.

Had tried implementing QoS to limit speeds, but it didnt seem to help in my case (OpenWRT uses NFTables to drop packets over the limit, which could just make jitter worse in my case).

Very preliminary, but seems to work much better for me after forcing the wifi channel width to 20MHz:

```
uci set wireless.radio0.htmode='HT20'
uci commit wireless
wifi reload
```

```
> iw dev phy0-ap0 info

Interface phy0-ap0
	ifindex 19
	wdev 0x5
	type AP
	wiphy 0
	channel 9 (2452 MHz), width: 20 MHz center1: 2452 MHz
	txpower 30.00 dBm
	multicast TXQ:
		qsz-byt	qsz-pkt	flows	drops	marks	overlmt	hashcol	tx-bytes	tx-packets
		0	0	1345	0	0	0	0	265780		1345
```

Closed 2025-06-02.

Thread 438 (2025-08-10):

Voice PE stuck "Enabling power supply"

EmilSepa, 2025-08-10:
After switching to Unifi APs my Voice PE is stuck in "Enabling power supply".
I attached one of my log files below.
I am aware of the "fast connect" problems for ESPs and hidden SSIDs.
The Wifi AP is a Unifi U7 Pro with a IoT VLAN for Homeassistant and the Voice PE on 2.4GhZ.

The different things I tried:

- different software version for Voice PE: 2025.5.1, 2025.5.2, 2025.6.0, 2025.7.0
- hidden SSID and not hidden
- IoT-only-Mode on Unifi
- Took over control with ESPHome and activated "Fast connect"

I have read some blog posts about using specific wifi channels for esp32.
Sadly, I don't have another AP to test this.
Before switching to Unifi, I've had a FritzBox and the Voice PE worked.

[esp-web-tools-logs.txt](https://github.com/user-attachments/files/21706055/esp-web-tools-logs.txt)

Deathbyteacup, 2025-08-14:
I had this issue (also with UniFi APs, coincidentally) when using a USB power supply that couldn't provide enough amps. USB on a computer for example won't be enough. I switched to an Anker USB adapter and it resolved it. So I think it is a power draw issue.

EmilSepa, 2025-09-04:
After debugging my voice pipeline for a while, I found the error.
It was never a power problem. My faster-whisper container was not working after changing my network setup for unraid.
Now I'm confused:
My piper is still working and reachable on the default network bridge (on unraid), my faster-whisper is not.
I had to move it to a custom bridge with an extra IP.

Closed 2025-09-04.

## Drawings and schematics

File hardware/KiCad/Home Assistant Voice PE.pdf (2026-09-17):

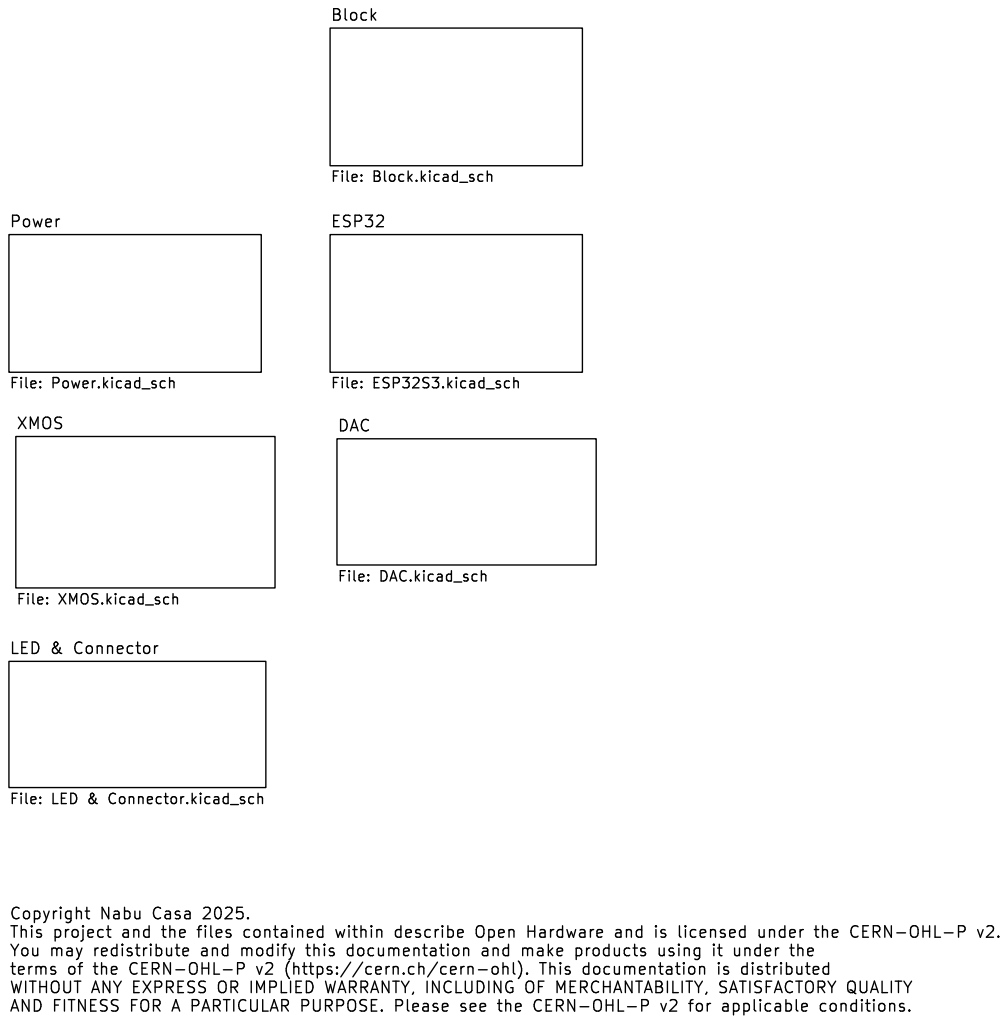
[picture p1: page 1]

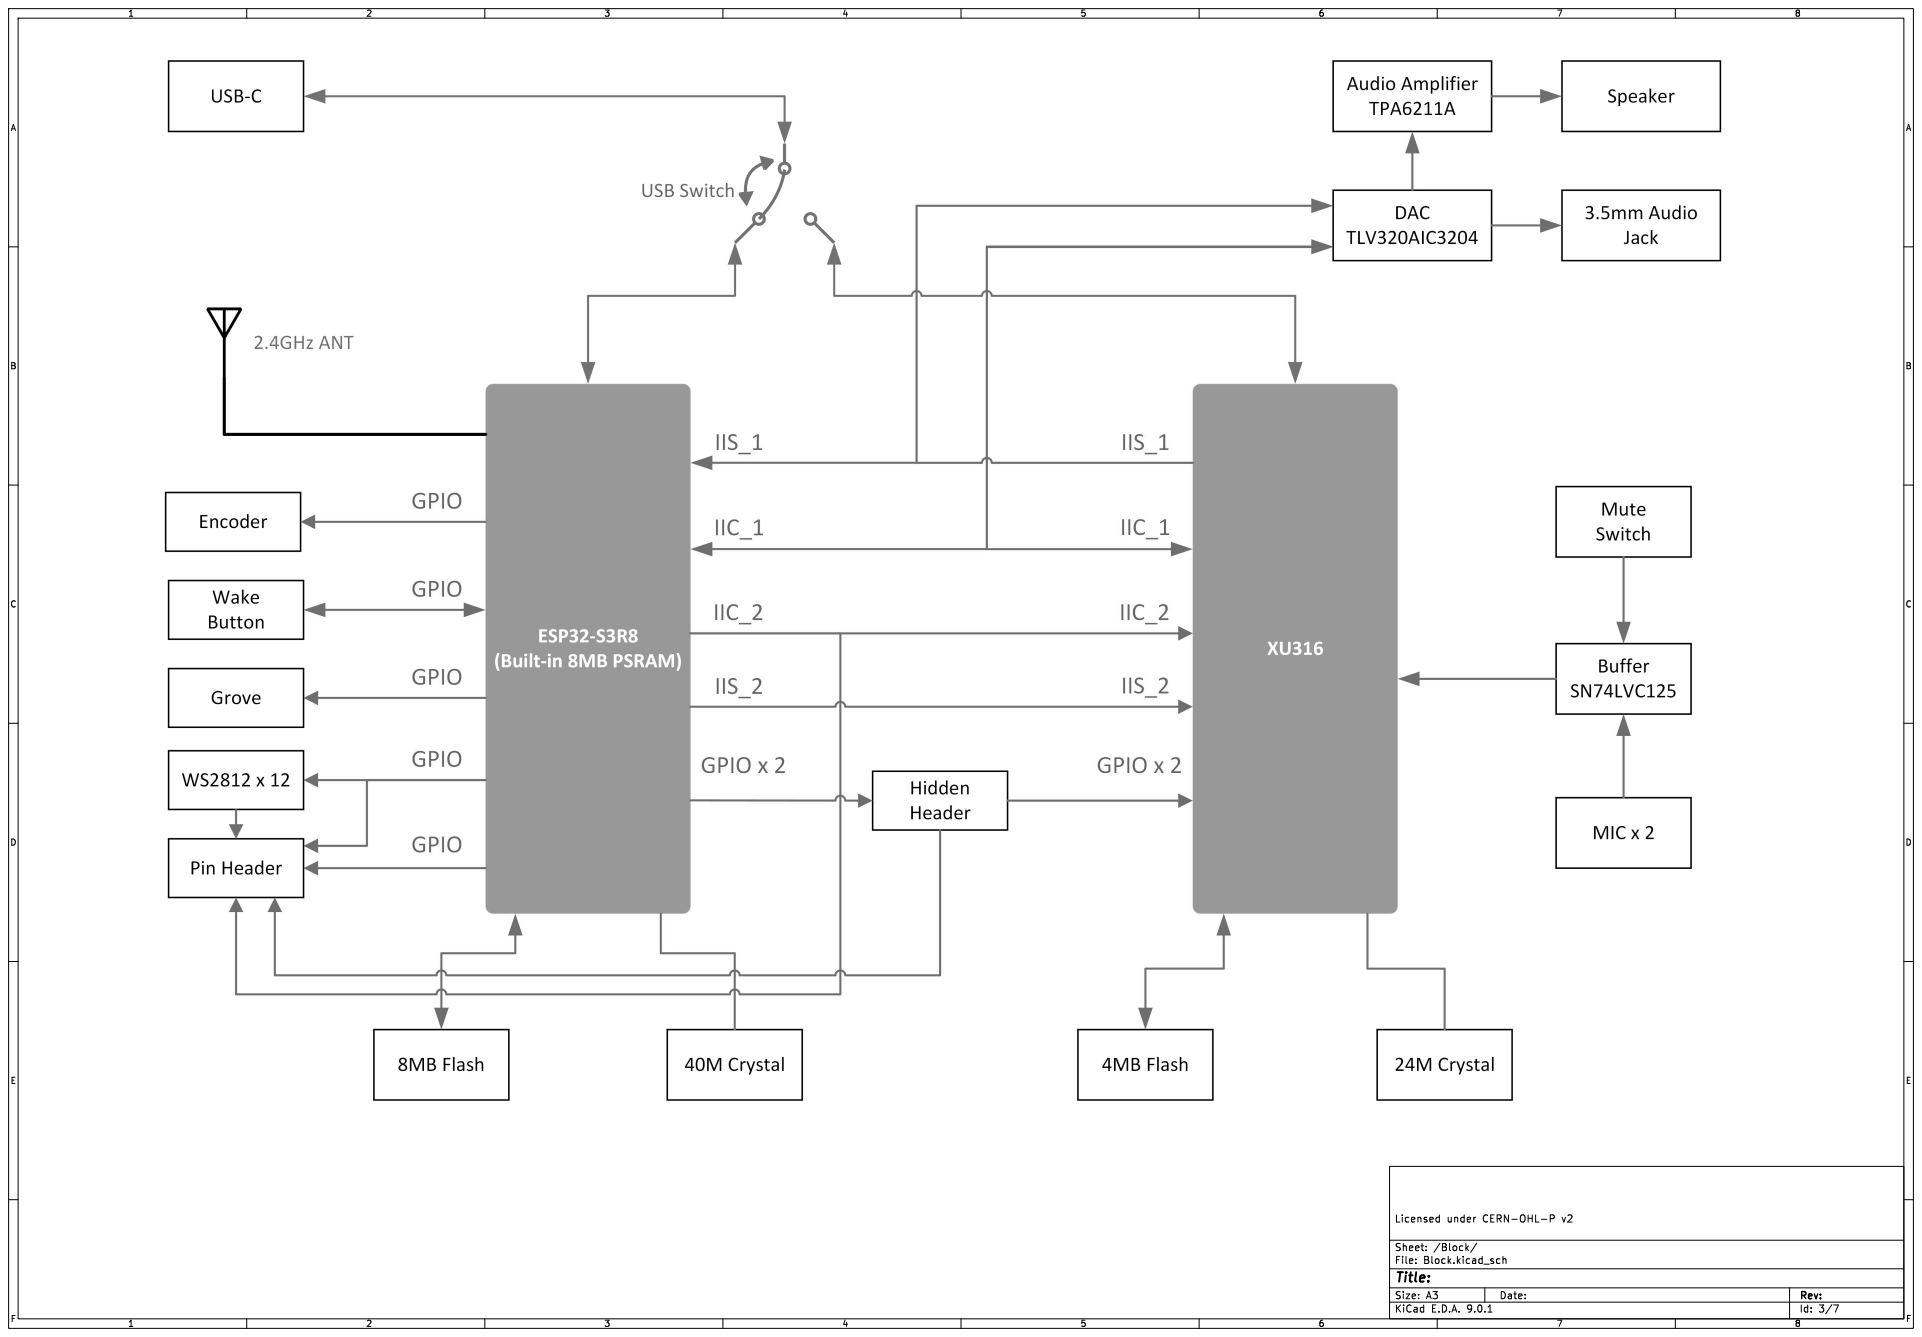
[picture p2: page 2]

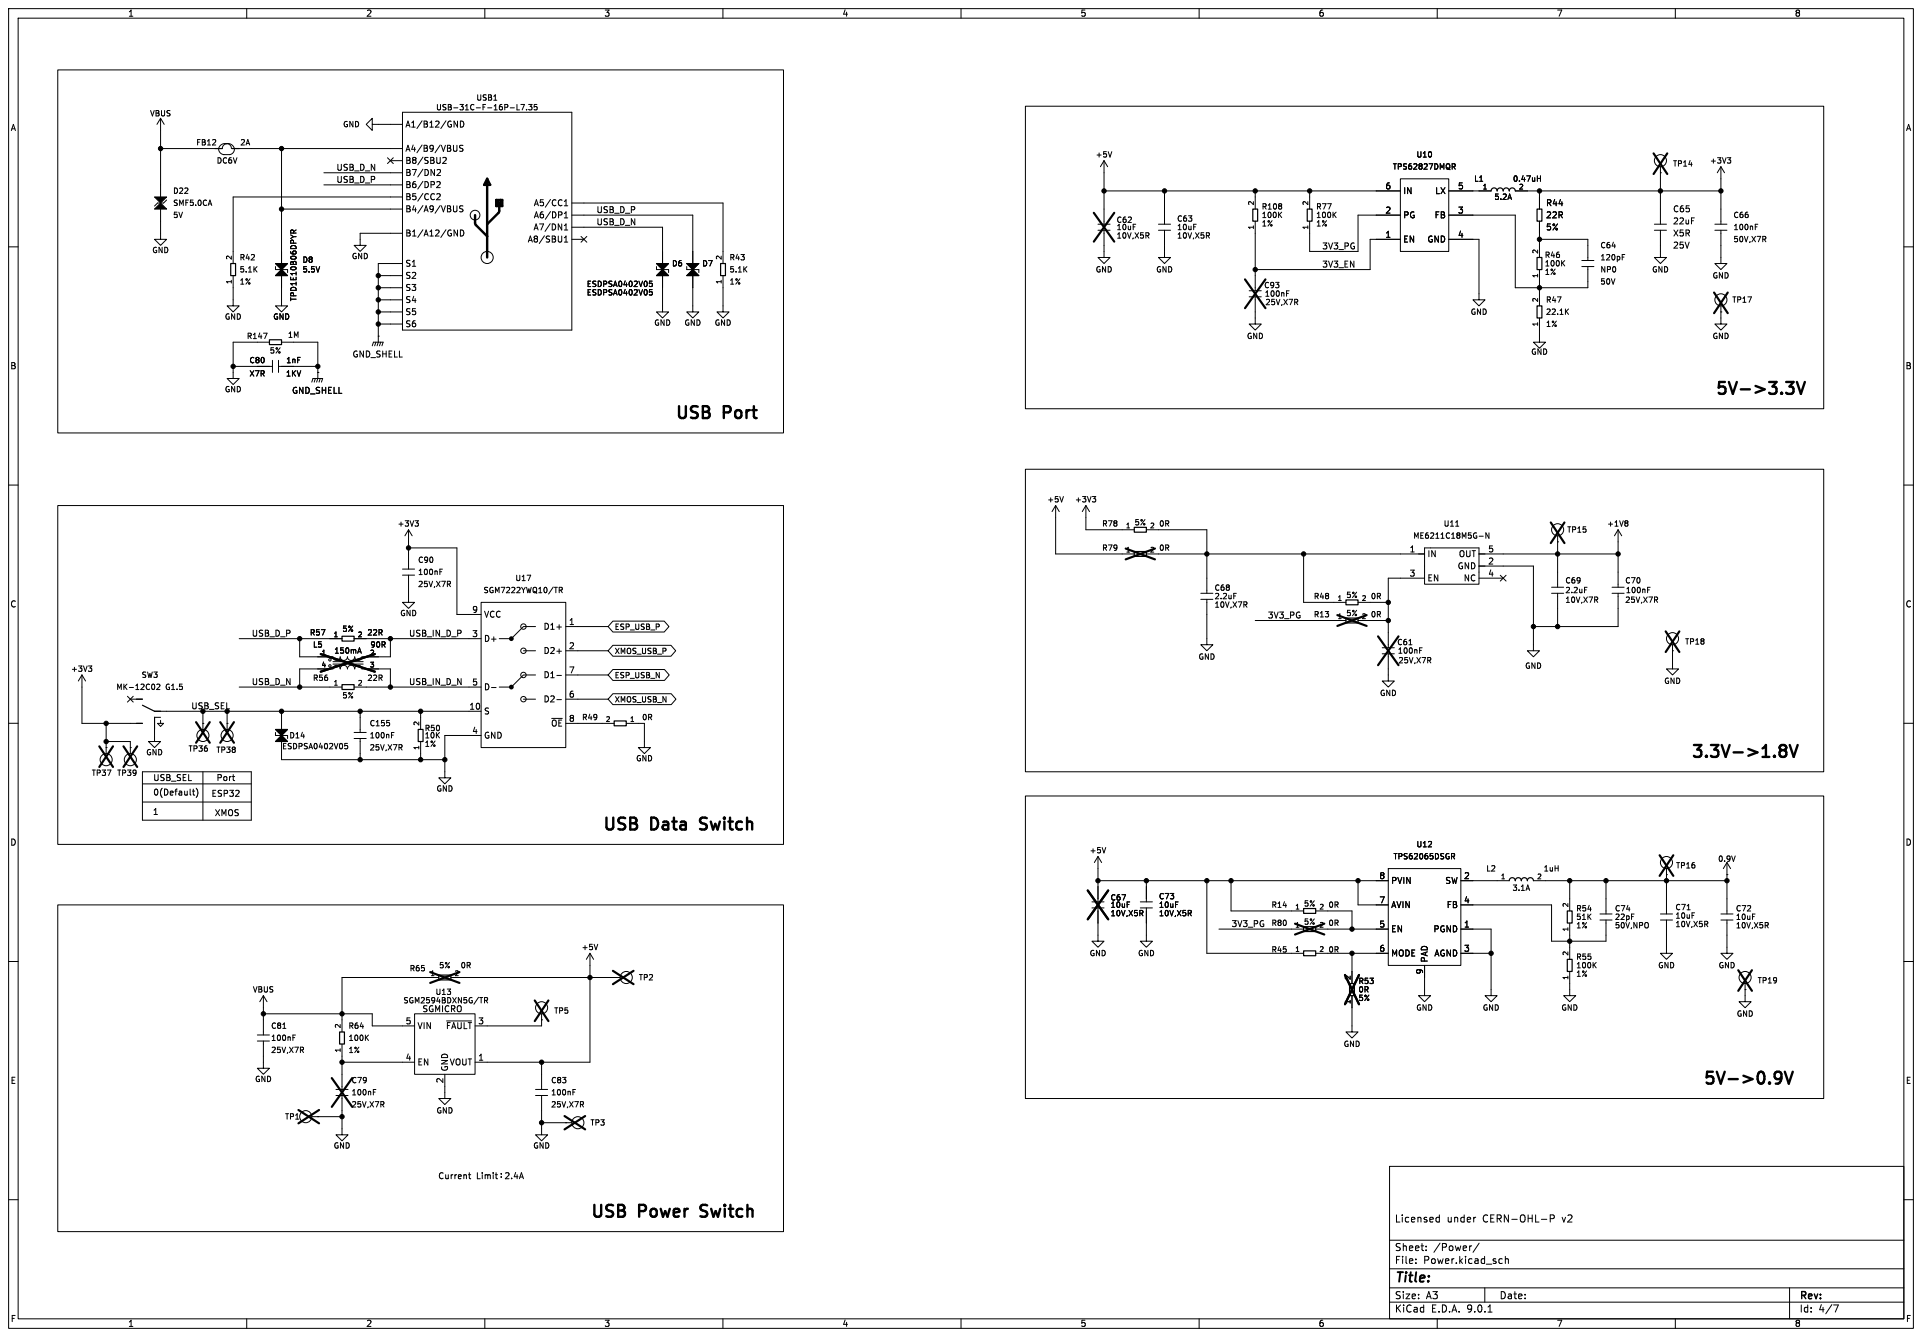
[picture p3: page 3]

9 SW 2 FB 4 PGND 1 AGND 3 U12 TPS62065DSGR

9 SW 2 FB 4 PGND 1 AGND 3 R53

2 ~{FAULT}3 VOUT 1 U13 SGM2594BDXN5G/TR SGMICRO

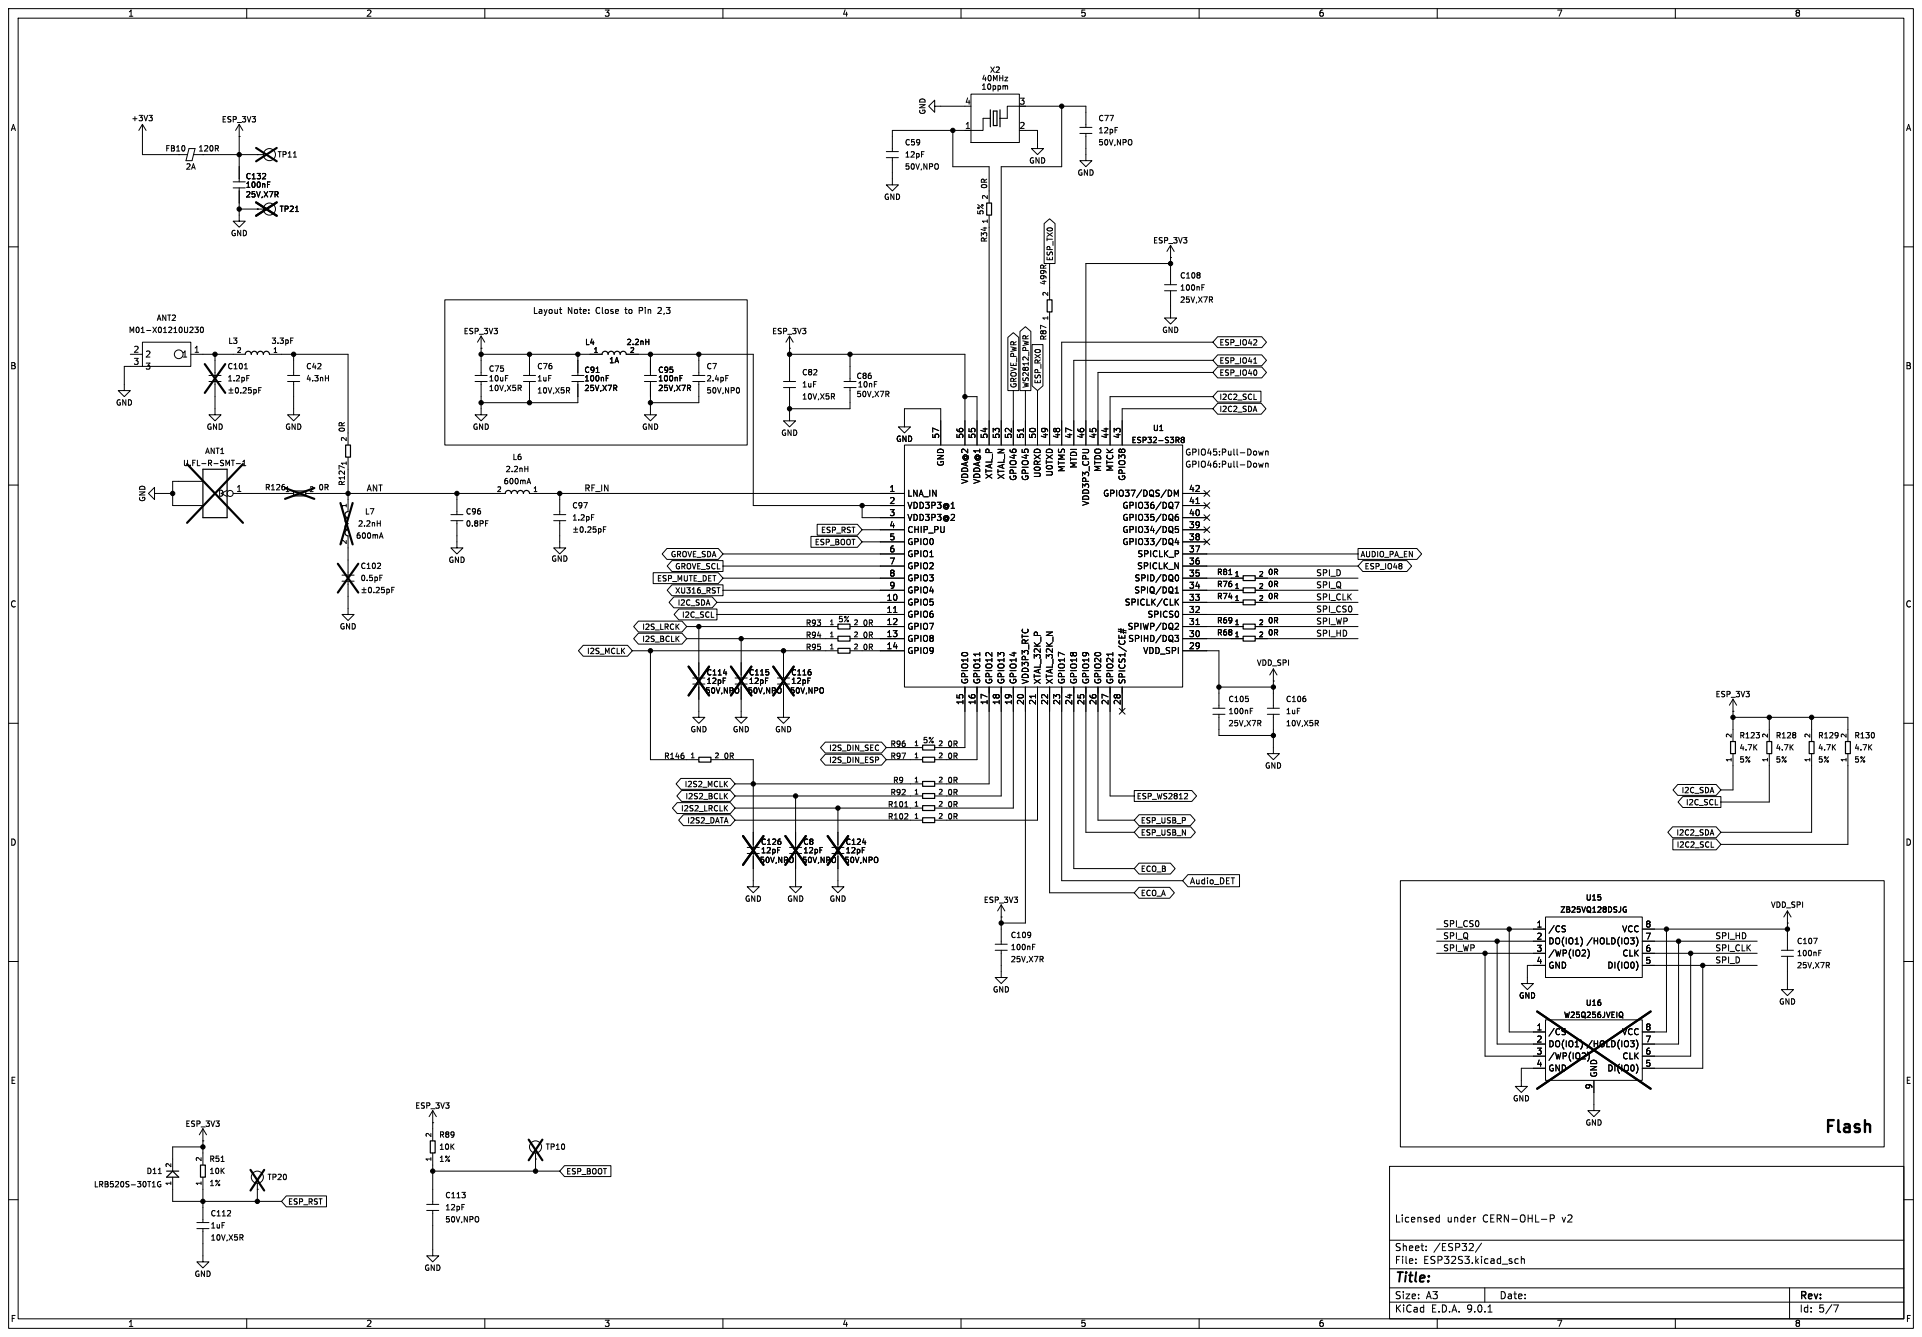
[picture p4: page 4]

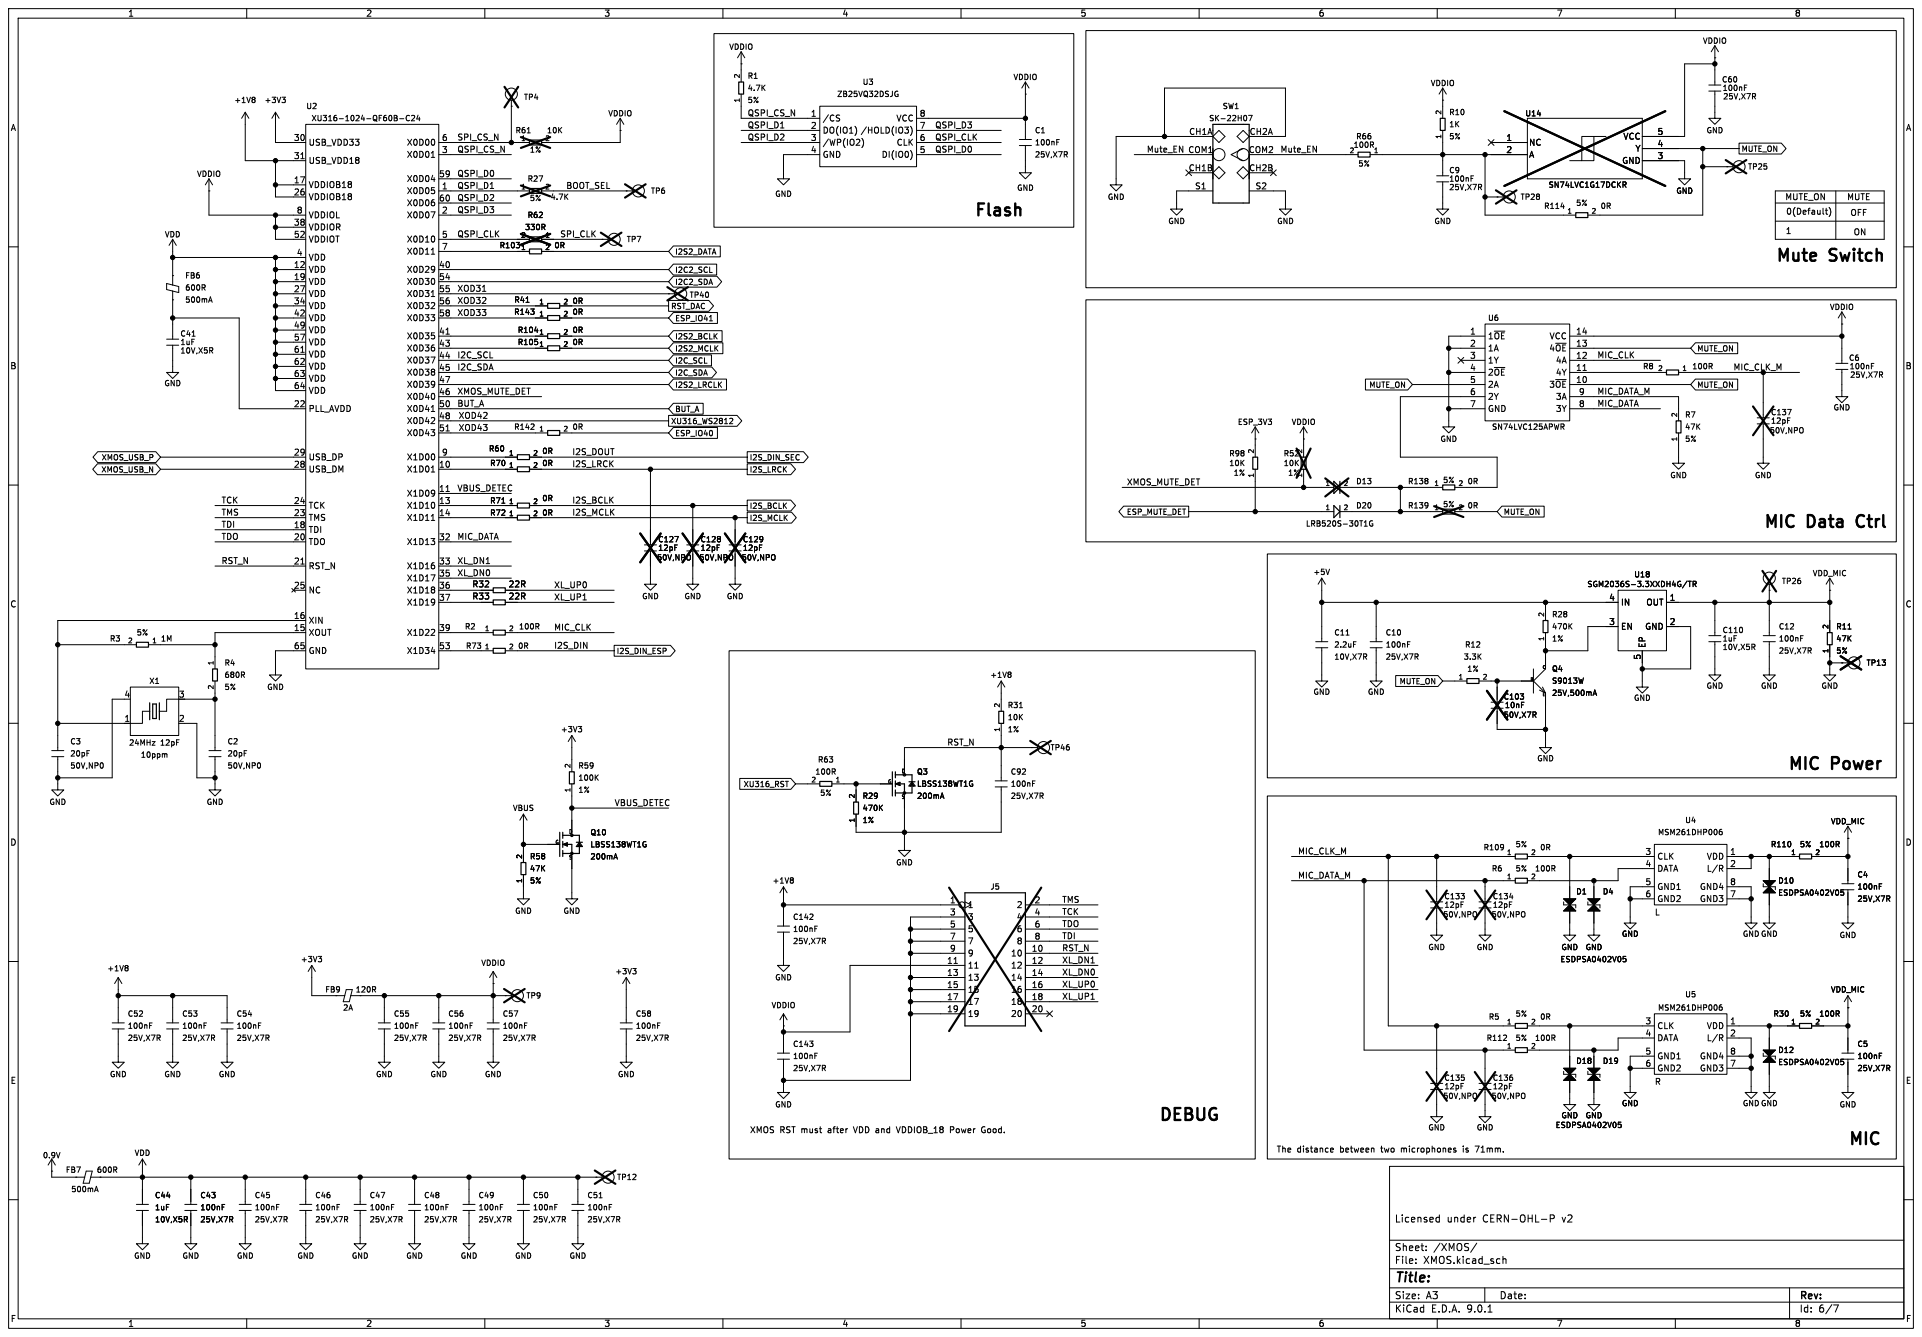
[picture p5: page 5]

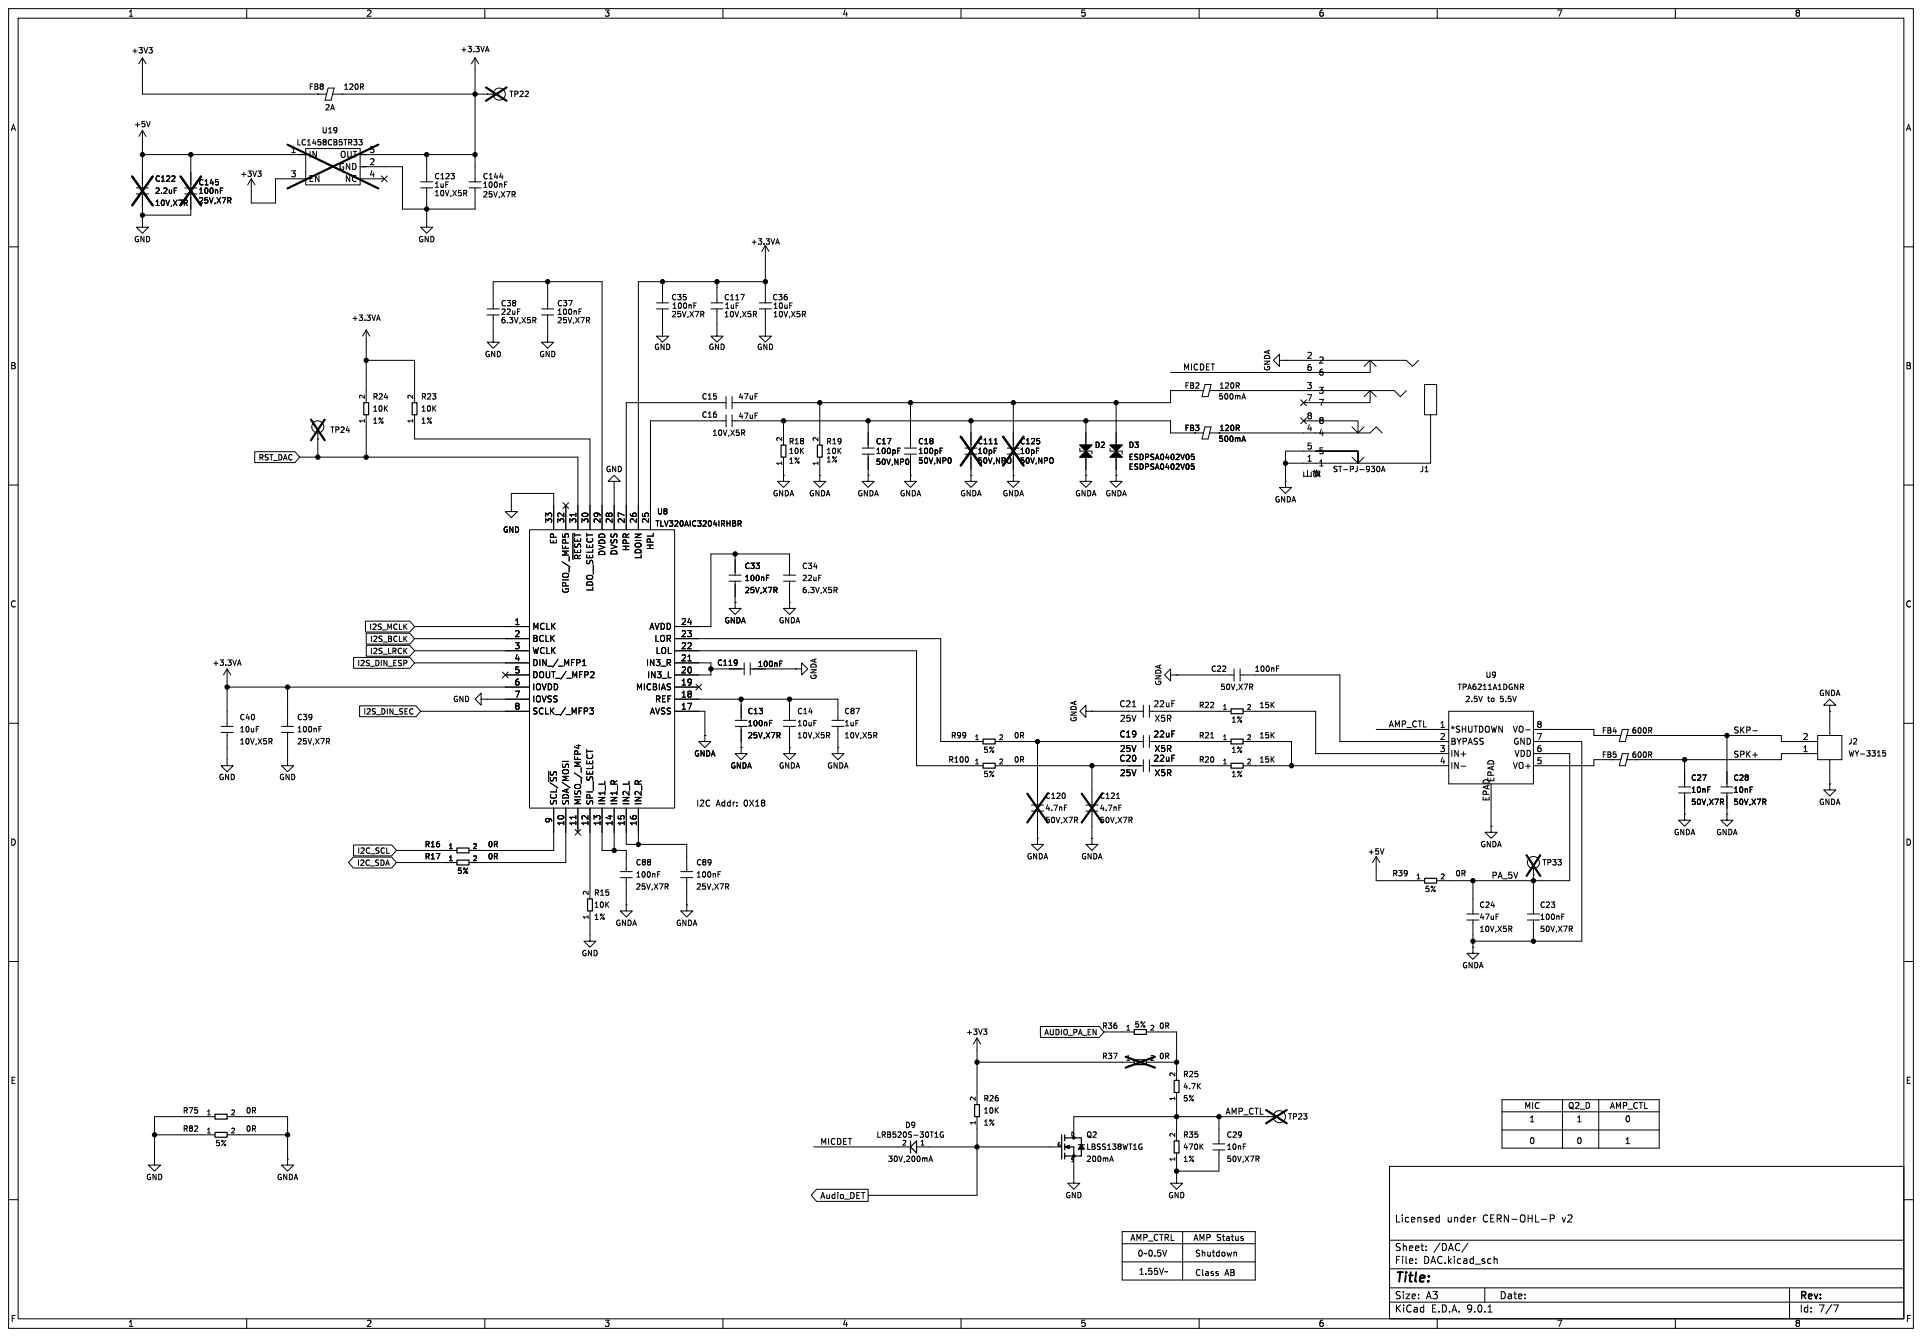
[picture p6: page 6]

VO- 8 GND 7 VDD 6 VO+ 5 U9 TPA6211A1DGNR

AMP Status Class AB
Shutdown

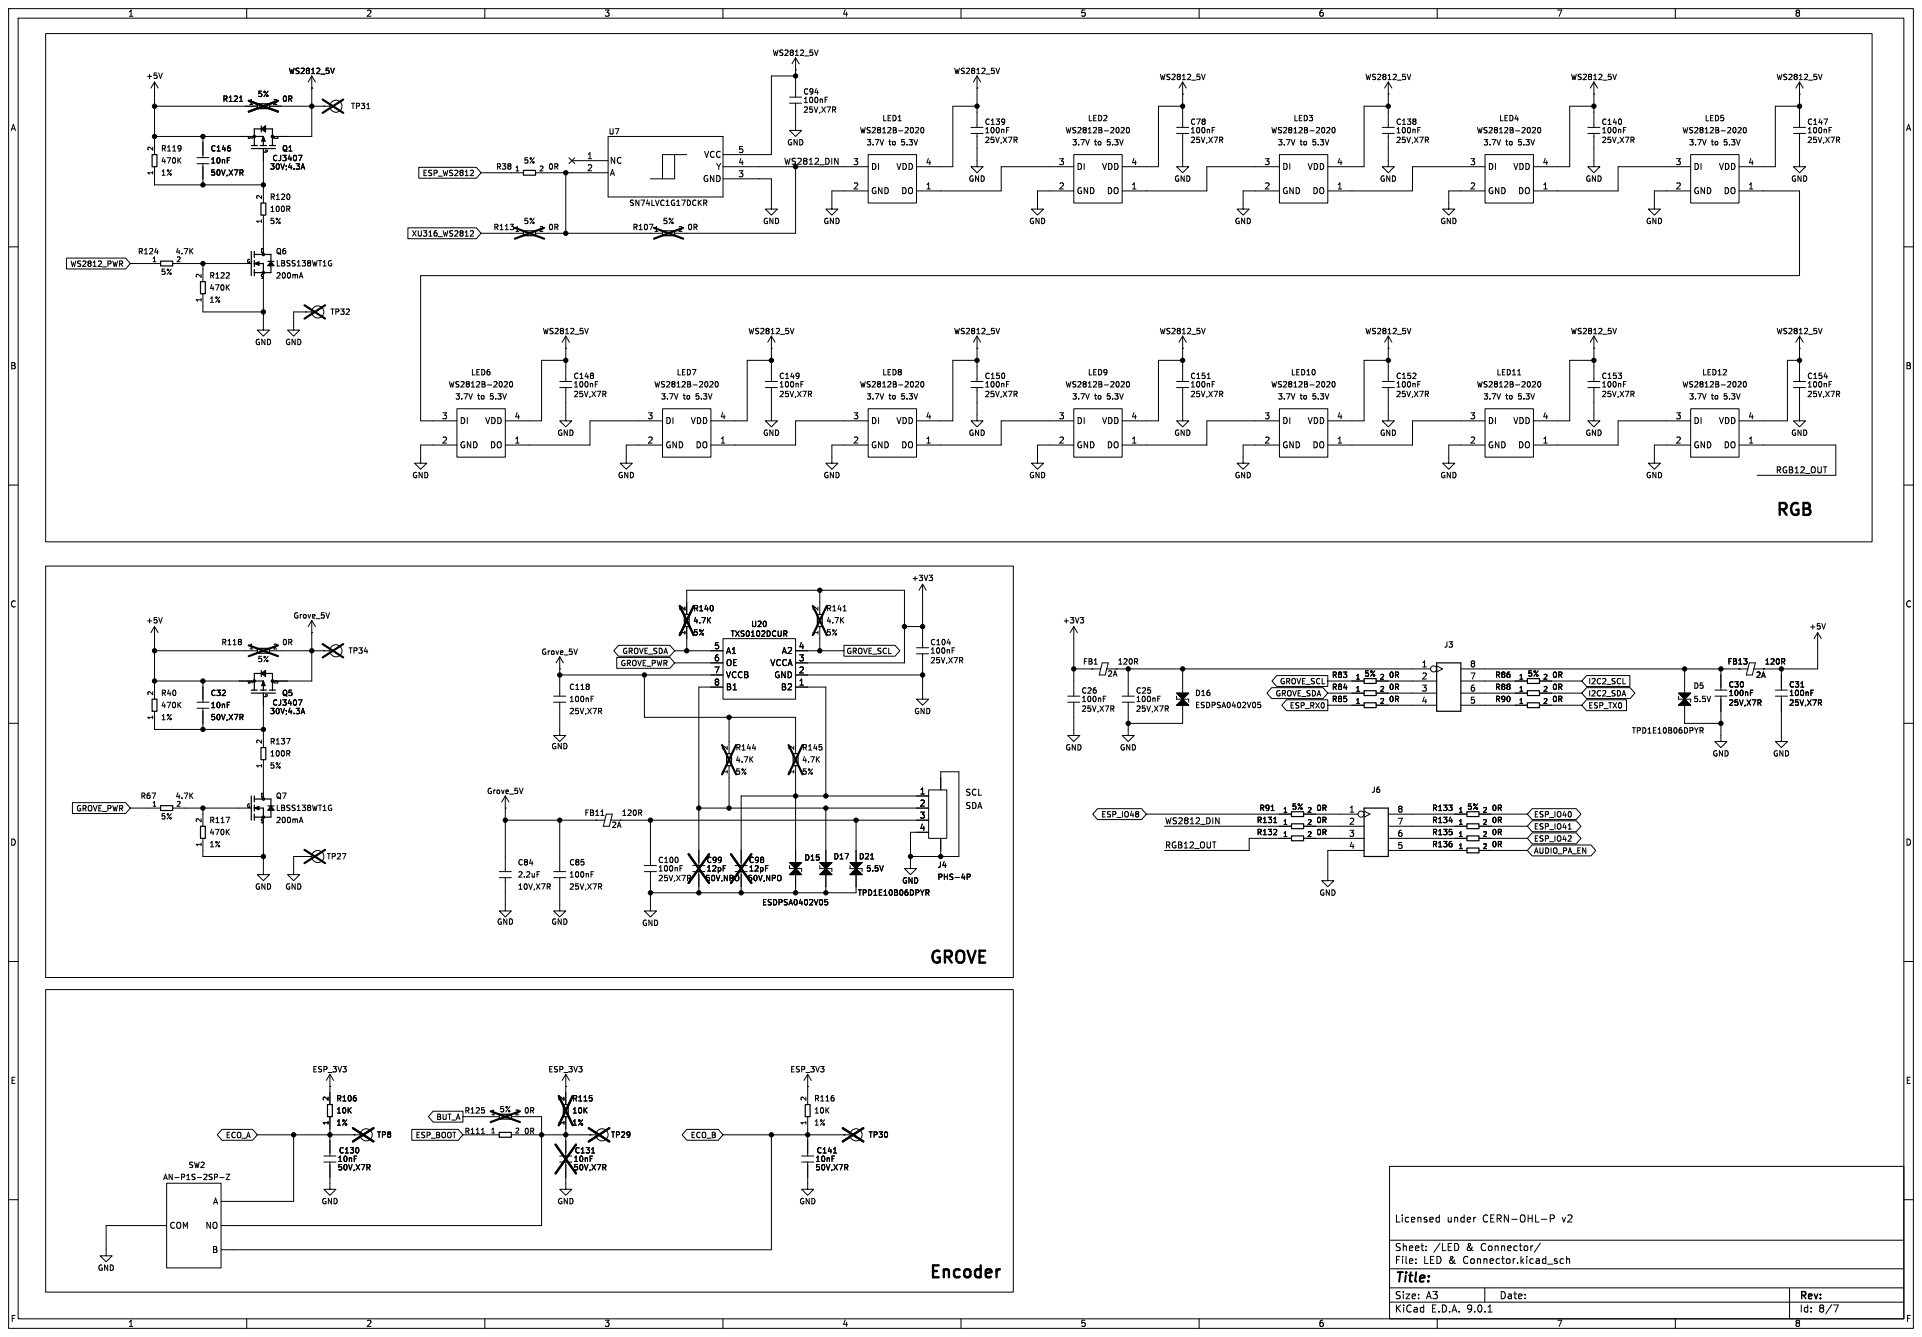
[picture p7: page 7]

2 U20 TXS0102DCURB2 1 GND 2 VCCA 3 A2 4 B1 8 VCCB 7 OE 6 A1 5 Q5 CJ3407
Grove_5V

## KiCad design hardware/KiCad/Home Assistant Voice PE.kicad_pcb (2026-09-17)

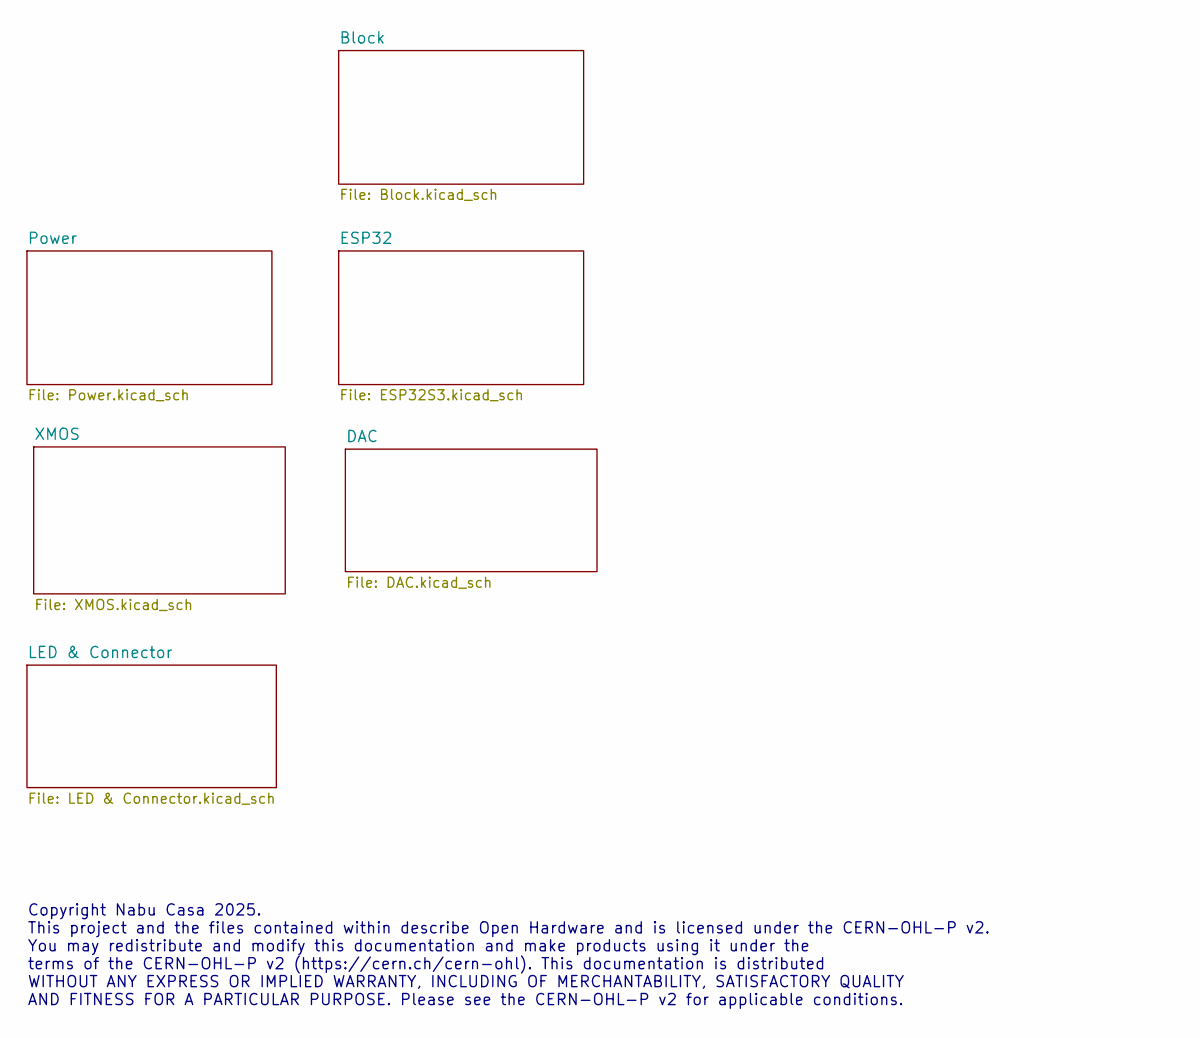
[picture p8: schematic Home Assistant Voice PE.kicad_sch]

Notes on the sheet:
Copyright Nabu Casa 2025. This project and the files contained within describe Open Hardware and is licensed under the CERN-OHL-P v2. You may redistribute and modify this documentation and make products using it under the terms of the CERN-OHL-P v2 (https://cern.ch/cern-ohl). This documentation is 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

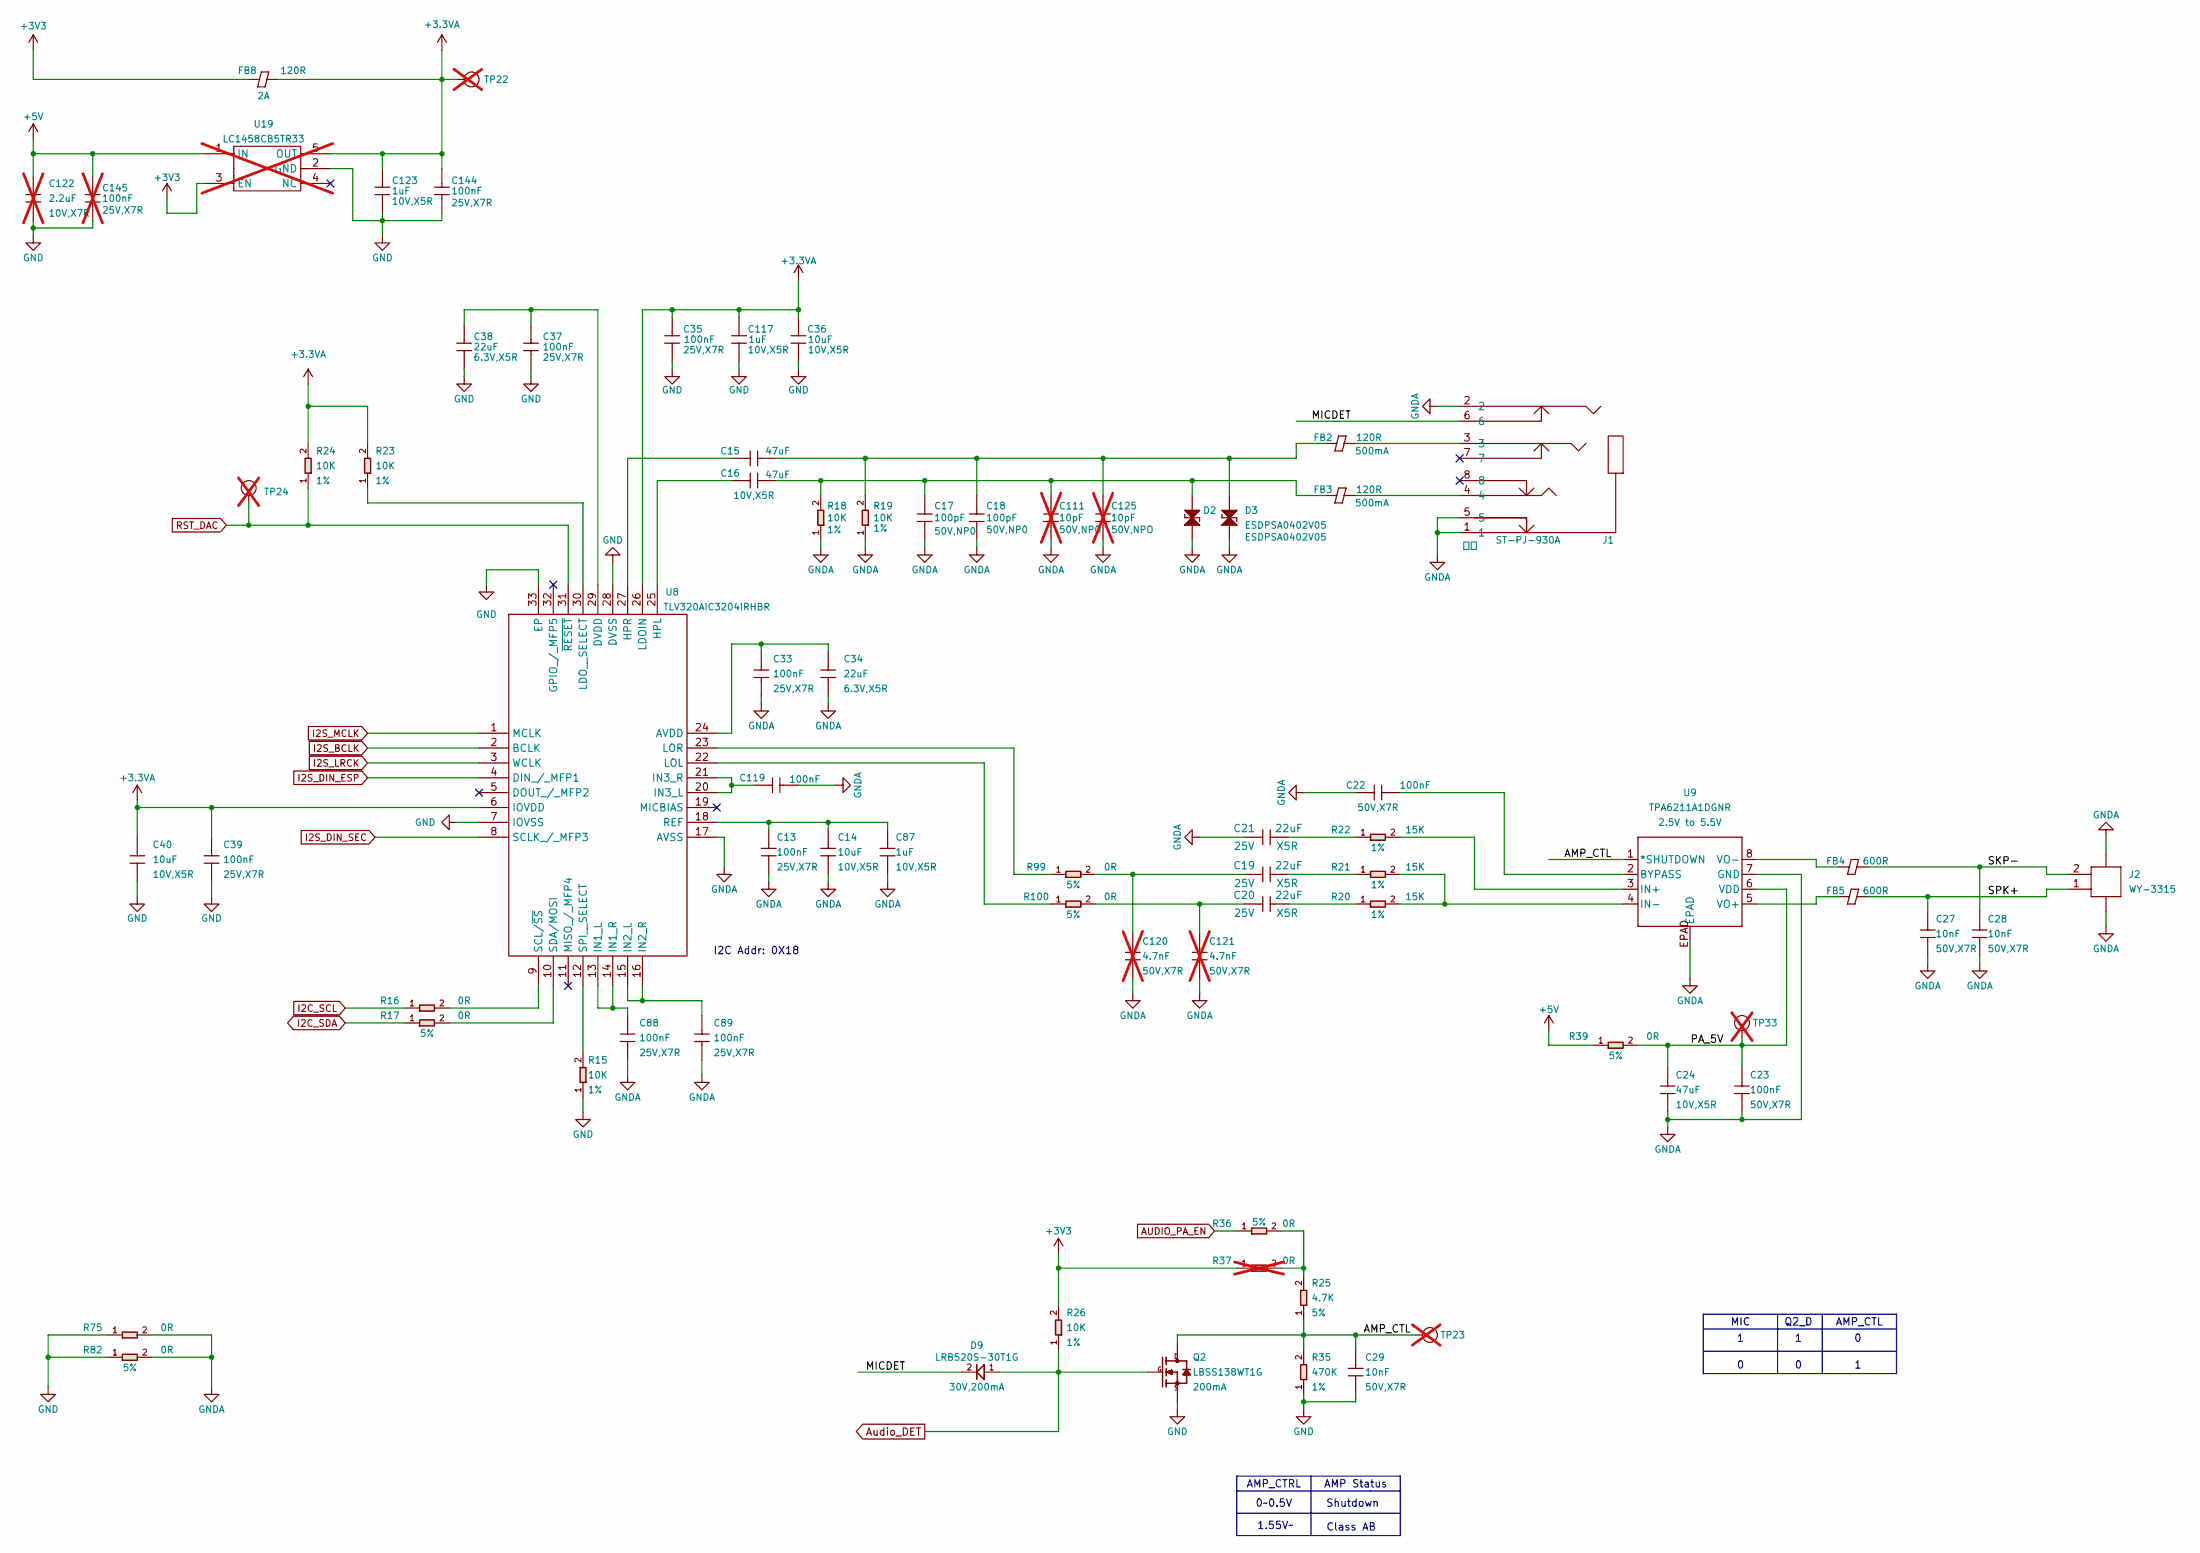
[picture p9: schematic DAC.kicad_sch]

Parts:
C13, C33, C35, C37, C39, C88, C89, C119, C144: 100nF; C0402; Voltage Rating 25V,X7R; MPN CC0402KRX7R8BB104
C14, C36, C40: 10uF; C0603; Voltage Rating 10V,X5R; MPN CL10A106KP8NNNC
C15, C16, C24: 47uF; C1206; Voltage Rating 10V,X5R; MPN CL31A476MPHNNNE
C17, C18: 100pF; C0402; Voltage Rating 50V,NP0; MPN CC0402FRNPO9BN101
C19, C20, C21: 22uF; C0805; Voltage Rating 25V; MPN CL21A226MAYNNNE
C22, C23: 100nF; C0603; Voltage Rating 50V,X7R; MPN CC0603KRX7R9BB104
C27, C28, C29: 10nF; C0402; Voltage Rating 50V,X7R; MPN CC0402KRX7R9BB103
C34, C38: 22uF; C0603; Voltage Rating 6.3V,X5R; MPN CL10A226MQ8NRNC
C87, C117, C123: 1uF; C0402; Voltage Rating 10V,X5R; MPN CL05A105KP5NNNC
C111, C125: 10pF; C0402; Voltage Rating 50V,NPO; MPN CC0402JRNPO9BN100; not fitted
C120, C121: 4.7nF; C0402; Voltage Rating 50V,X7R; MPN CC0402KRX7R9BB472; not fitted
C122: 2.2uF; C0603; Voltage Rating 10V,X7R; MPN CC0603KRX7R6BB225; not fitted
C145: 100nF; C0402; Voltage Rating 25V,X7R; MPN CC0402KRX7R8BB104; not fitted
D2, D3: ESDPSA0402V05; ESD-0402; MPN ESDPSA0402V05
D9: LRB520S-30T1G; SOD-523; Rating 30V,200mA; MPN LRB520S-30T1G
FB2, FB3: 120R; L0603; Rating 500mA; MPN BLM18AG121SN1D
FB4, FB5: 600R; L0603; Rating 500mA; MPN BLM18AG601SN1D
FB8: 120R; L0603; Rating 2A; MPN BLM18PG121SN1D
J1: ST-PJ-930A
J2: WY-3315; JST2P_1d25_7_55x4_25x4_8mm; MPN WY-3315
Q2: LBSS138WT1G; SOT-323; Rating 200mA; MPN LBSS138WT1G
R15, R18, R19, R23, R24, R26: 10K; R0402; Power Rating 1%; MPN RC0402FR-0710KL
R16, R17, R36: 0R; R0402; Power Rating 5%; MPN RC0402JR-070RL
R20, R21, R22: 15K; R0603; Power Rating 1%; MPN RC0603FR-0715KL
R25: 4.7K; R0402; Power Rating 5%; MPN RC0402JR-074K7L
R35: 470K; R0402; Power Rating 1%; MPN RC0402FR-07470KL
R37: 0R; R0402; Power Rating 5%; MPN RC0402JR-070RL; not fitted
R39, R99, R100: 0R; R0603; Power Rating 5%; MPN RC0603JR-070RL
R75, R82: 0R; R0805; Power Rating 5%; MPN RC0805JR-070RL
TP22, TP33: Test Point; TP-D45MIL; Part Type Test Point; not fitted
TP23, TP24: TEST-POINT; TP-D45MIL; not fitted
U8: TLV320AIC3204IRHBR; MPN TLV320AIC3204IRHBR; Mouser Part Number 595-V320AIC3204IRHBR
U9: TPA6211A1DGNR; DGN8_1d89X1P57; Rating 2.5V to 5.5V; MPN TI
U19: LC1458CB5TR33; SOT-23-5; MPN LC1458CB5TR33; not fitted

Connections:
+3.3VA: C35.1, C36.1, C39.1, C40.1, C117.1, C123.1, C144.1, FB8.2, R23.2, R24.2, TP22.1 (T), U8.6 (IOVDD), U8.26 (LDOIN), U19.5 (OUT)
+3V3: FB8.1, R26.2, R37.1, U19.3 (EN); also elsewhere on the board
+5V: C122.1, C145.1, R39.1, U19.1 (IN); also elsewhere on the board
/DAC/AMP_CTL: C29.1, Q2.3 (D), R25.1, R35.2, TP23.1 (T), U9.1 (*SHUTDOWN)
/DAC/MICDET: D9.2, J1.6
/DAC/PA_5V: C23.1, C24.1, R39.2, TP33.1 (T), U9.6 (VDD)
/DAC/SKP-: C28.1, FB4.2, J2.2
/DAC/SPK+: C27.1, FB5.2, J2.1
AUDIO_PA_EN: R36.1; also elsewhere on the board
Audio_DET: D9.1, Q2.1 (G), R26.1; also elsewhere on the board
GND: C29.2, C35.2, C36.2, C37.2, C38.2, C39.2, C40.2, C117.2, C122.2, C123.2, C144.2, C145.2, Q2.2 (S), R15.1, R35.1, R75.1, R82.1, U8.7 (IOVSS), U8.28 (DVSS), U8.33 (EP), U19.2 (GND); also elsewhere on the board
GNDA: C13.2, C14.2, C17.2, C18.2, C21.1, C22.1, C23.2, C24.2, C27.2, C28.2, C33.2, C34.2, C87.2, C88.2, C89.2, C111.2, C119.2, C120.2, C121.2, C125.2, D2.1, D3.1, J1.1, J1.2, J1.5, J2.3, J2.4, R18.1, R19.1, R75.2, R82.2, U8.17 (AVSS), U9.7 (GND), U9.EPAD
I2C_SCL: R16.1; also elsewhere on the board
I2C_SDA: R17.1; also elsewhere on the board
I2S_BCLK: U8.2 (BCLK); also elsewhere on the board
I2S_DIN_ESP: U8.4 (DIN_/_MFP1); also elsewhere on the board
I2S_DIN_SEC: U8.8 (SCLK_/_MFP3); also elsewhere on the board
I2S_LRCK: U8.3 (WCLK); also elsewhere on the board
I2S_MCLK: U8.1 (MCLK); also elsewhere on the board
unnamed: C19.2, R21.1
unnamed: C20.2, R20.1
unnamed: C21.2, R22.1
unnamed: C16.2, C17.1, C111.1, D2.2, FB3.1, R18.2
unnamed: C19.1, C120.1, R99.2
unnamed: C20.1, C121.1, R100.2
unnamed: C15.2, C18.1, C125.1, D3.2, FB2.1, R19.2
unnamed: FB2.2, J1.3
unnamed: FB3.2, J1.4
unnamed: R25.2, R36.2, R37.2
unnamed: C33.1, C34.1, U8.24 (AVDD)
unnamed: C37.1, C38.1, U8.29 (DVDD)
unnamed: C16.1, U8.25 (HPL)
unnamed: C15.1, U8.27 (HPR)
unnamed: C88.1, U8.13 (IN1_L), U8.14 (IN1_R)
unnamed: C89.1, U8.15 (IN2_L), U8.16 (IN2_R)
unnamed: C119.1, U8.20 (IN3_L), U8.21 (IN3_R)
unnamed: R23.1, U8.30 (LDO__SELECT)
unnamed: R100.1, U8.22 (LOL)
unnamed: R99.1, U8.23 (LOR)
unnamed: C13.1, C14.1, C87.1, U8.18 (REF)
unnamed: R16.2, U8.9 (SCL/~SS)
unnamed: R17.2, U8.10 (SDA/MOSI)
unnamed: R15.2, U8.12 (SPI__SELECT)
unnamed: C22.2, U9.2 (BYPASS)
unnamed: R22.2, U9.3 (IN+)
unnamed: R20.2, R21.2, U9.4 (IN-)
unnamed: FB5.1, U9.5 (VO+)
unnamed: FB4.1, U9.8 (VO-)
RST_DAC: R24.1, TP24.1 (T), U8.31 (~RESET); also elsewhere on the board

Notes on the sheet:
Shutdown
MIC
0~0.5V
Class AB
AMP_CTRL
AMP Status
AMP_CTL
1.55V~
Q2_D
I2C Addr: 0X18

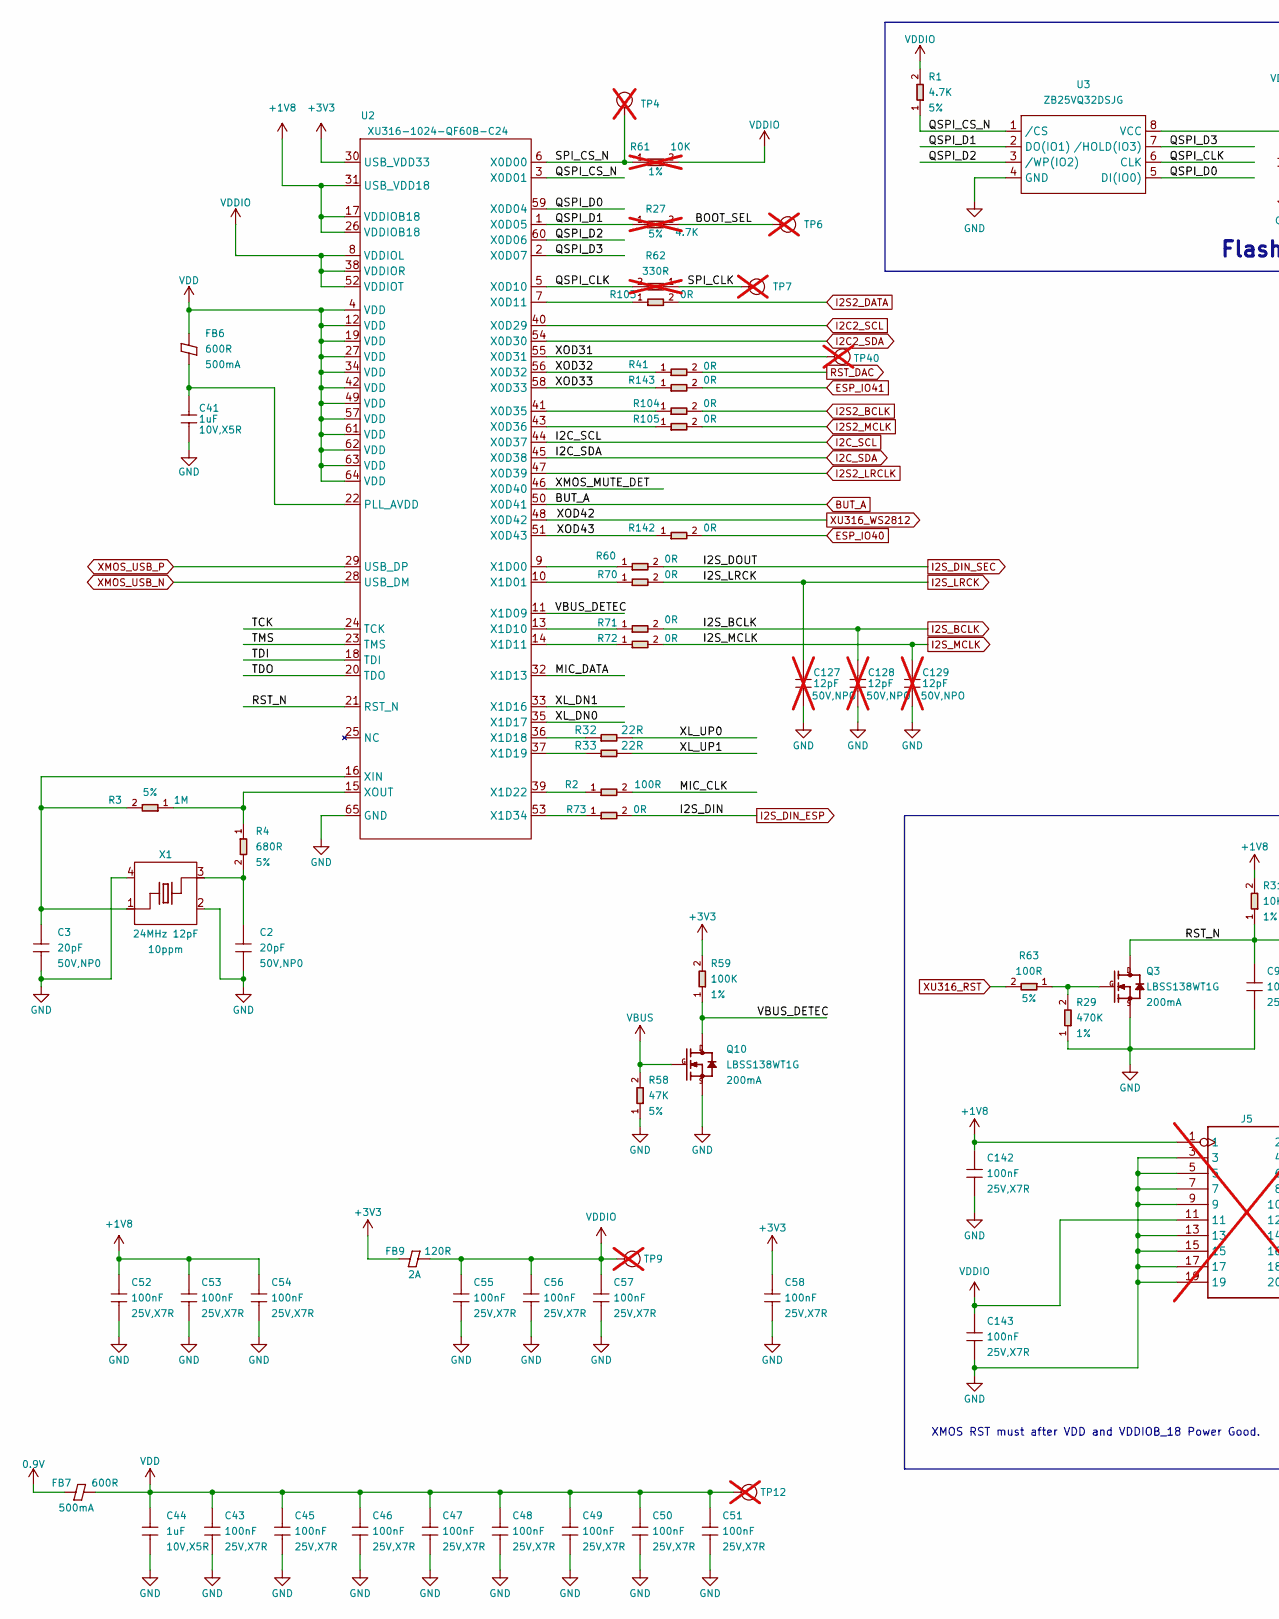
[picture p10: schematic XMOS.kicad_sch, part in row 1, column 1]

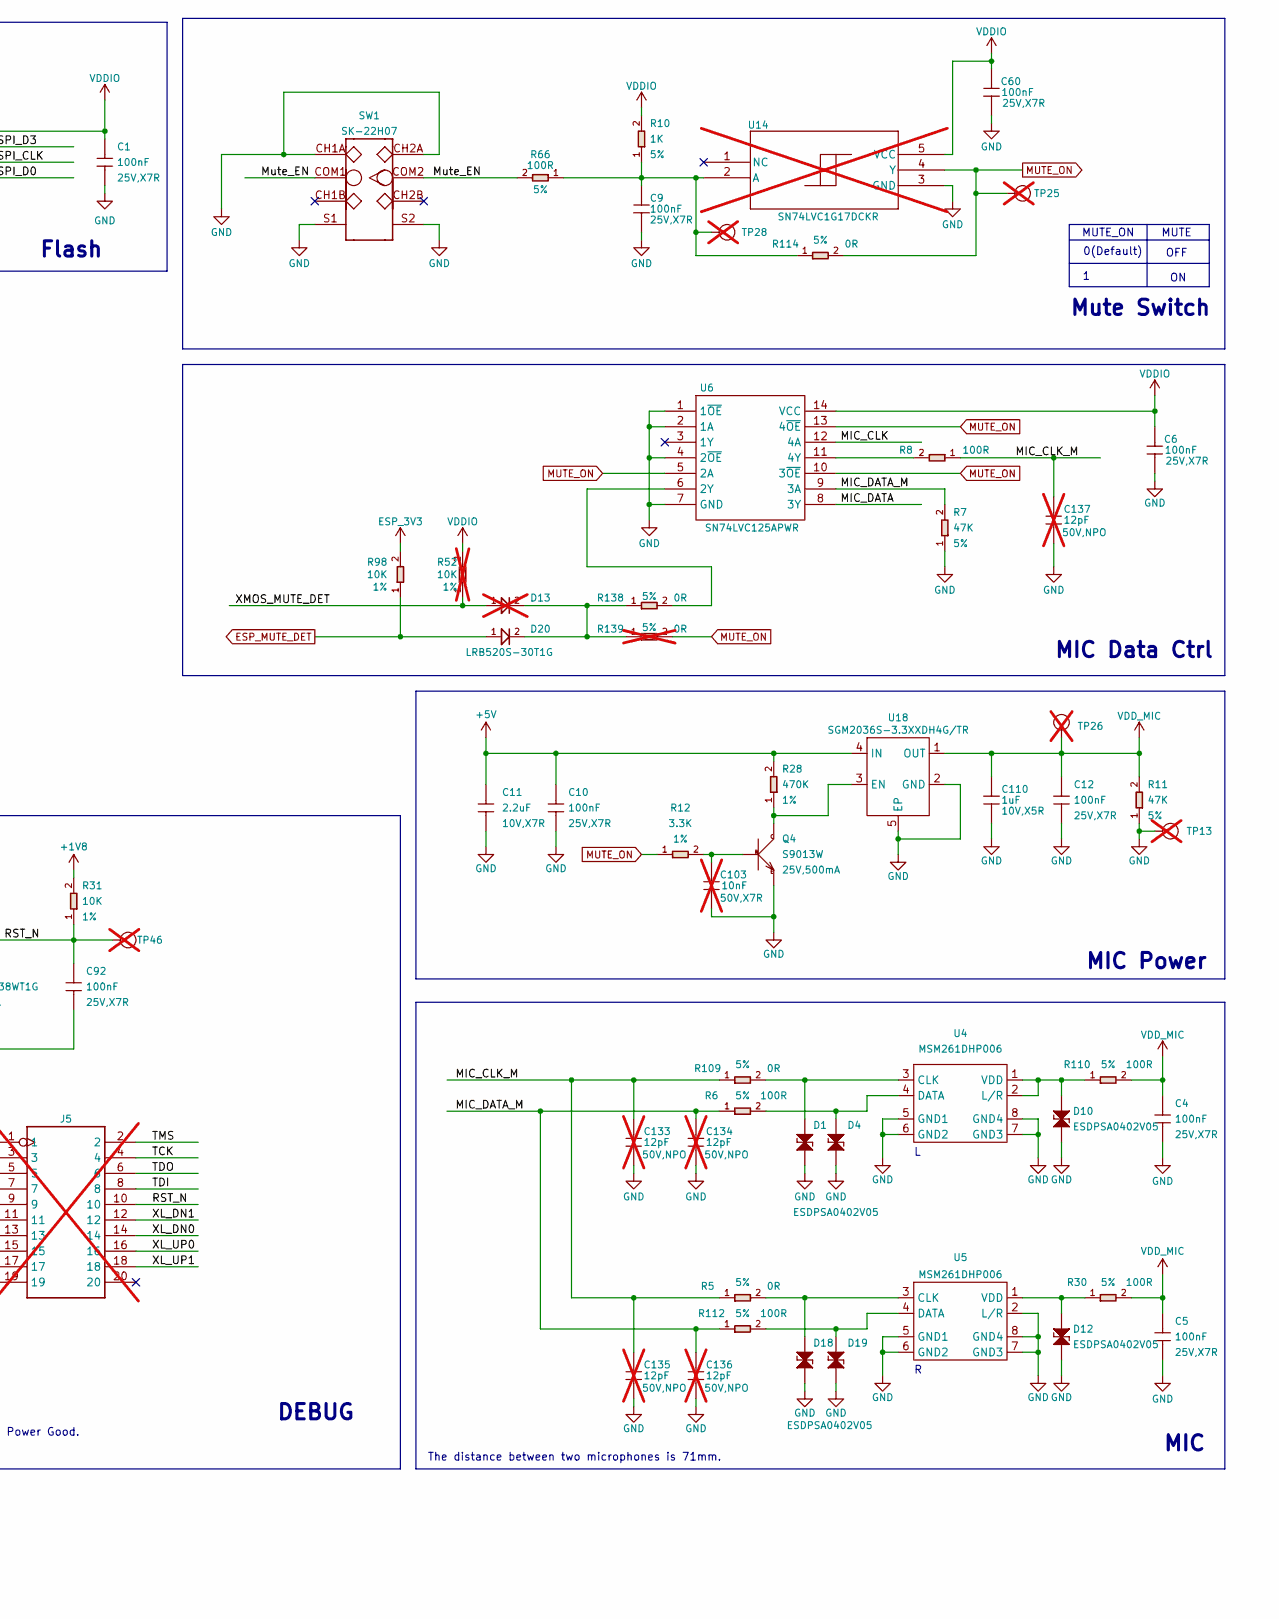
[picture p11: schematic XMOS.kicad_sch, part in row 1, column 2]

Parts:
C1, C4, C5, C6, C9, C10, C12, C43, C45, C46, C47, C48, C49, C50, C51, C52, C53, C54, C55, C56, C57, C58, C60, C92, C142, C143: 100nF; C0402; Voltage Rating 25V,X7R; MPN CC0402KRX7R8BB104
C2, C3: 20pF; C0402; Voltage Rating 50V,NP0; MPN CC0402JRNPO9BN200
C11: 2.2uF; C0603; Voltage Rating 10V,X7R; MPN CC0603KRX7R6BB225
C41, C44, C110: 1uF; C0402; Voltage Rating 10V,X5R; MPN CL05A105KP5NNNC
C103: 10nF; C0402; Voltage Rating 50V,X7R; MPN CC0402KRX7R9BB103; not fitted
C127, C128, C129, C133, C134, C135, C136, C137: 12pF; C0402; Voltage Rating 50V,NPO; MPN CC0402JRNPO9BN120; not fitted
D1, D4, D10, D12, D18, D19: ESDPSA0402V05; ESD-0402; MPN ESDPSA0402V05
D13: LRB520S-30T1G; SOD-523; Rating 30V,200mA; MPN LRB520S-30T1G; not fitted
D20: LRB520S-30T1G; SOD-523; Rating 30V,200mA; MPN LRB520S-30T1G
FB6, FB7: 600R; L0603; Rating 500mA; MPN BLM18AG601SN1D
FB9: 120R; L0603; Rating 2A; MPN BLM18PG121SN1D
J5: JTAG_2X10_1.27_SMD; Part Type Header; not fitted
Q3, Q10: LBSS138WT1G; SOT-323; Rating 200mA; MPN LBSS138WT1G
Q4: S9013W; SOT-323; Rating 25V,500mA; MPN S9013W
R1: 4.7K; R0402; Power Rating 5%; MPN RC0402JR-074K7L
R2, R6, R8, R30, R63, R66, R110, R112: 100R; R0402; Power Rating 5%; MPN RC0402JR-07100RL
R3: 1M; R0402; Power Rating 5%; MPN RC0402JR-071ML
R4: 680R; R0402; Power Rating 5%; MPN RC0402JR-07680RL
R5, R41, R60, R70, R71, R72, R73, R103, R104, R105, R109, R114, R138, R142, R143: 0R; R0402; Power Rating 5%; MPN RC0402JR-070RL
R7, R11, R58: 47K; R0402; Power Rating 5%; MPN RC0402JR-0747KL
R10: 1K; R0402; Power Rating 5%; MPN RC0402JR-071KL
R12: 3.3K; R0402; Power Rating 1%; MPN RC0402JR-073K3L
R27: 4.7K; R0402; Power Rating 5%; MPN RC0402JR-074K7L; not fitted
R28, R29: 470K; R0402; Power Rating 1%; MPN RC0402FR-07470KL
R31, R98: 10K; R0402; Power Rating 1%; MPN RC0402FR-0710KL
R32, R33: 22R; R0402; Power Rating 5%; MPN RC0402JR-0722RL
R52, R61: 10K; R0402; Power Rating 1%; MPN RC0402FR-0710KL; not fitted
R59: 100K; R0402; Power Rating 1%; MPN RC0402FR-07100KL
R62: 330R; R0402; Power Rating 1%; MPN RC0402FR-07330RL; not fitted
R139: 0R; R0402; Power Rating 5%; MPN RC0402JR-070RL; not fitted
SW1: SK-22H07; SW6-2CH-12.7X7X4.7MM; MPN SK-22H07
TP4, TP6, TP7, TP9, TP12, TP13, TP25, TP26: TEST-POINT; TP-D45MIL; not fitted
TP28, TP40, TP46: Test Point; TP-D45MIL; Part Type Test Point; not fitted
U2: XU316-1024-QF60B-C24 ; QFN_F60B-C24_XMO; MPN XU316-1024-QF60B-C24 
U3: ZB25VQ32DSJG; SOIC8-1.27-5.3X5.3MM; MPN ZB25VQ32DSJG
U4, U5: MSM261DHP006; MIC8P-0.85-4X3X1MM; MPN MIC-MSM261DHP006
U6: SN74LVC125APWR; MPN SN74LVC125APWR; Mouser Part Number 595-SN74LVC125APWR
U14: SN74LVC1G17DCKR; MPN SN74LVC1G17DCKR; not fitted
U18: SGM2036S-3.3XXDH4G/TR; X2SON4-0.625-1x1x0.6mm; Rating Vin MAX=6.5V; MPN SGM2036S-3.3XXDH4G/TR
X1: 24MHz 12pF; X4-SMD-2.0X1.6MM; Rating 10ppm; MPN Y2400FE001

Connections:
0.9V: FB7.1; also elsewhere on the board
+1V8: C52.1, C53.1, C54.1, C142.1, J5.1, R31.2, U2.17 (VDDIOB18), U2.26 (VDDIOB18), U2.31 (USB_VDD18); also elsewhere on the board
+3V3: C58.1, FB9.1, R59.2, U2.30 (USB_VDD33); also elsewhere on the board
+5V: C10.1, C11.1, R28.2, U18.4 (IN); also elsewhere on the board
/XMOS/BOOT_SEL: R27.2, TP6.1 (T)
/XMOS/MIC_CLK: R2.2, U6.12 (4A)
/XMOS/MIC_CLK_M: C133.1, C135.1, C137.1, R5.1, R8.1, R109.1
/XMOS/MIC_DATA: U2.32 (X1D13), U6.8 (3Y)
/XMOS/MIC_DATA_M: C134.1, C136.1, R6.1, R7.2, R112.1, U6.9 (3A)
/XMOS/Mute_EN: R66.2, SW1.COM1, SW1.COM2
/XMOS/QSPI_CLK: R62.2, U2.5 (X0D10), U3.6 (CLK)
/XMOS/QSPI_CS_N: R1.1, U2.3 (X0D01), U3.1 (/CS)
/XMOS/QSPI_D0: U2.59 (X0D04), U3.5 (DI(IO0))
/XMOS/QSPI_D1: R27.1, U2.1 (X0D05), U3.2 (DO(IO1))
/XMOS/QSPI_D2: U2.60 (X0D06), U3.3 (/WP(IO2))
/XMOS/QSPI_D3: U2.2 (X0D07), U3.7 (/HOLD(IO3))
/XMOS/RST_N: C92.1, J5.10, Q3.3 (D), R31.1, TP46.1 (T), U2.21 (RST_N)
/XMOS/SPI_CLK: R62.1, TP7.1 (T)
/XMOS/SPI_CS_N: R61.1, TP4.1 (T), U2.6 (X0D00)
/XMOS/TCK: J5.4, U2.24 (TCK)
/XMOS/TDI: J5.8, U2.18 (TDI)
/XMOS/TDO: J5.6, U2.20 (TDO)
/XMOS/TMS: J5.2, U2.23 (TMS)
/XMOS/VBUS_DETEC: Q10.3 (D), R59.1, U2.11 (X1D09)
/XMOS/XL_DN0: J5.14, U2.35 (X1D17)
/XMOS/XL_DN1: J5.12, U2.33 (X1D16)
/XMOS/XL_UP0: J5.16, R32.2
/XMOS/XL_UP1: J5.18, R33.2
/XMOS/XMOS_MUTE_DET: D13.1, R52.1, U2.46 (X0D40)
/XMOS/XOD31: TP40.1 (T), U2.55 (X0D31)
/XMOS/XOD32: R41.1, U2.56 (X0D32)
/XMOS/XOD33: R143.1, U2.58 (X0D33)
/XMOS/XOD43: R142.1, U2.51 (X0D43)
BUT_A: U2.50 (X0D41); also elsewhere on the board
ESP_3V3: R98.2; also elsewhere on the board
ESP_IO40: R142.2; also elsewhere on the board
ESP_IO41: R143.2; also elsewhere on the board
ESP_MUTE_DET: D20.1, R98.1; also elsewhere on the board
GND: C1.2, C2.2, C3.2, C4.2, C5.2, C6.2, C9.2, C10.2, C11.2, C12.2, C41.2, C43.2, C44.2, C45.2, C46.2, C47.2, C48.2, C49.2, C50.2, C51.2, C52.2, C53.2, C54.2, C55.2, C56.2, C57.2, C58.2, C60.2, C92.2, C103.2, C110.2, C127.2, C128.2, C129.2, C133.2, C134.2, C135.2, C136.2, C137.2, C142.2, C143.2, D1.1, D4.1, D10.1, D12.1, D18.1, D19.1, J5.3, J5.5, J5.7, J5.9, J5.13, J5.15, J5.17, J5.19, Q3.2 (S), Q4.2 (E), Q10.2 (S), R7.1, R11.1, R29.1, R58.1, SW1.CH1A, SW1.CH2A, SW1.S1, SW1.S2, TP13.1 (T), U2.65 (GND), U3.4 (GND), U4.5 (GND1), U4.6 (GND2), U4.7 (GND3), U4.8 (GND4), U5.2 (L/R), U5.5 (GND1), U5.6 (GND2), U5.7 (GND3), U5.8 (GND4), U6.1 (1~OE), U6.2 (1A), U6.4 (2~OE), U6.7 (GND), U14.3 (GND), U18.2 (GND), U18.5 (EP), X1.2, X1.4; also elsewhere on the board
I2C2_SCL: U2.40 (X0D29); also elsewhere on the board
I2C2_SDA: U2.54 (X0D30); also elsewhere on the board
I2C_SCL: U2.44 (X0D37); also elsewhere on the board
I2C_SDA: U2.45 (X0D38); also elsewhere on the board
I2S2_BCLK: R104.2; also elsewhere on the board
I2S2_DATA: R103.2; also elsewhere on the board
I2S2_LRCLK: U2.47 (X0D39); also elsewhere on the board
I2S2_MCLK: R105.2; also elsewhere on the board
I2S_BCLK: C128.1, R71.2; also elsewhere on the board
I2S_DIN_ESP: R73.2; also elsewhere on the board
I2S_DIN_SEC: R60.2; also elsewhere on the board
I2S_LRCK: C127.1, R70.2; also elsewhere on the board
I2S_MCLK: C129.1, R72.2; also elsewhere on the board
MUTE_ON: R12.1, R114.2, R139.2, TP25.1 (T), U6.5 (2A), U6.10 (3~OE), U6.13 (4~OE), U14.4 (Y)
unnamed: C2.1, R4.2, X1.3
unnamed: D13.2, D20.2, R138.1, R139.1
unnamed: Q3.1 (G), R29.2, R63.1
unnamed: C103.1, Q4.1 (B), R12.2
unnamed: Q4.3 (C), R28.1, U18.3 (EN)
unnamed: C9.1, R10.1, R66.1, R114.1, TP28.1 (T), U14.2 (A)
unnamed: C41.1, FB6.1, U2.22 (PLL_AVDD)
unnamed: R103.1, U2.7 (X0D11)
unnamed: R104.1, U2.41 (X0D35)
unnamed: R105.1, U2.43 (X0D36)
unnamed: R60.1, U2.9 (X1D00)
unnamed: R70.1, U2.10 (X1D01)
unnamed: R71.1, U2.13 (X1D10)
unnamed: R72.1, U2.14 (X1D11)
unnamed: R32.1, U2.36 (X1D18)
unnamed: R33.1, U2.37 (X1D19)
unnamed: R2.1, U2.39 (X1D22)
unnamed: R73.1, U2.53 (X1D34)
unnamed: C3.1, R3.2, U2.16 (XIN), X1.1
unnamed: R3.1, R4.1, U2.15 (XOUT)
unnamed: D1.2, R109.2, U4.3 (CLK)
unnamed: D4.2, R6.2, U4.4 (DATA)
unnamed: D10.2, R110.1, U4.1 (VDD), U4.2 (L/R)
unnamed: D18.2, R5.2, U5.3 (CLK)
unnamed: D19.2, R112.2, U5.4 (DATA)
unnamed: D12.2, R30.1, U5.1 (VDD)
unnamed: R138.2, U6.6 (2Y)
unnamed: R8.2, U6.11 (4Y)
RST_DAC: R41.2; also elsewhere on the board
VBUS: Q10.1 (G), R58.2; also elsewhere on the board
VDD: C43.1, C44.1, C45.1, C46.1, C47.1, C48.1, C49.1, C50.1, C51.1, FB6.2, FB7.2, TP12.1 (T), U2.4 (VDD), U2.12 (VDD), U2.19 (VDD), U2.27 (VDD), U2.34 (VDD), U2.42 (VDD), U2.49 (VDD), U2.57 (VDD), U2.61 (VDD), U2.62 (VDD), U2.63 (VDD), U2.64 (VDD)
VDDIO: C1.1, C6.1, C55.1, C56.1, C57.1, C60.1, C143.1, FB9.2, J5.11, R1.2, R10.2, R52.2, R61.2, TP9.1 (T), U2.8 (VDDIOL), U2.38 (VDDIOR), U2.52 (VDDIOT), U3.8 (VCC), U6.14 (VCC), U14.5 (VCC)
VDD_MIC: C4.1, C5.1, C12.1, C110.1, R11.2, R30.2, R110.2, TP26.1 (T), U18.1 (OUT)
XMOS_USB_N: U2.28 (USB_DM); also elsewhere on the board
XMOS_USB_P: U2.29 (USB_DP); also elsewhere on the board
XU316_RST: R63.2; also elsewhere on the board
XU316_WS2812: U2.48 (X0D42); also elsewhere on the board

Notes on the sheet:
MUTE_ON
The distance between two microphones is 71mm.
DEBUG
Flash
Mute Switch
MIC Data Ctrl
OFF
MIC
MUTE
XMOS RST must after VDD and VDDIOB_18 Power Good.
0(Default)
MIC Power

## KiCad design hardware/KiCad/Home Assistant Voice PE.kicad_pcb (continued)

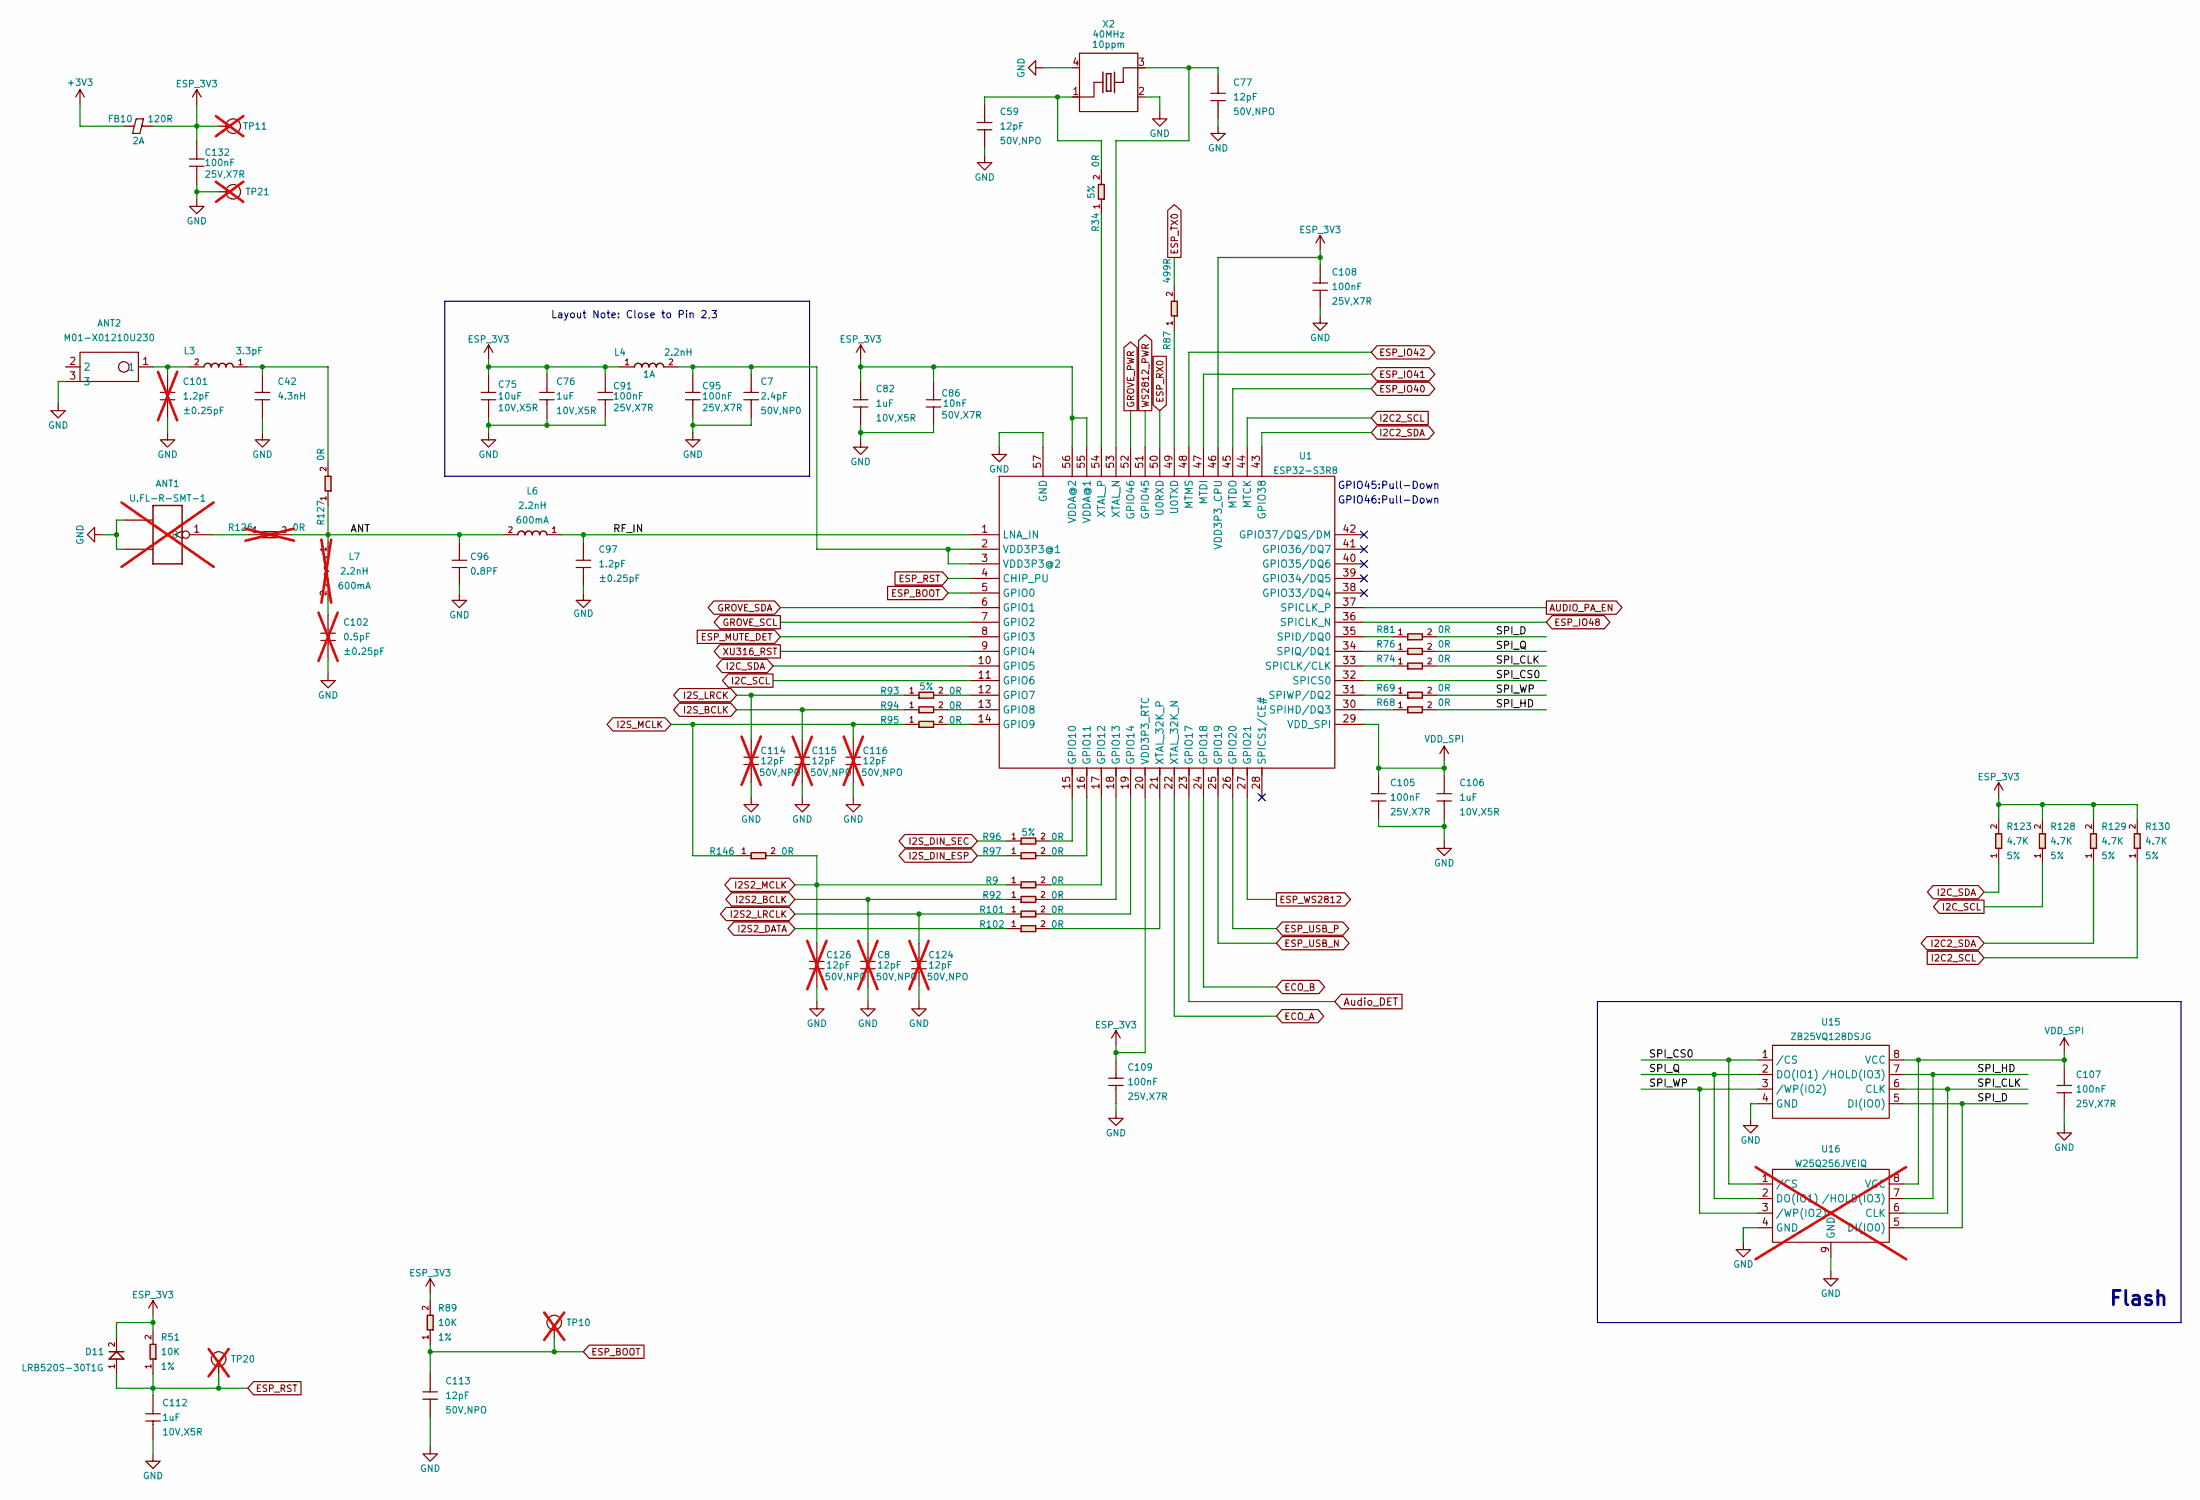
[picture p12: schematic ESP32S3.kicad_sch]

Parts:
ANT1: U.FL-R-SMT-1; U-FL3P-SMD-2.6X2.6X1.0MM; MPN U.FL-R-SMT-1; not fitted
ANT2: M01-X01210U230; ANT2P-12x10.45x3.0MM_3; MPN M01-X01210U230
C7: 2.4pF; C0402; Voltage Rating 50V,NP0; MPN CC0402CRNPO9BN2R4
C8, C114, C115, C116, C124, C126: 12pF; C0402; Voltage Rating 50V,NPO; MPN CC0402JRNPO9BN120; not fitted
C42: 4.3nH; C0201; MPN LQP03TN4N3H02D
C59, C77, C113: 12pF; C0402; Voltage Rating 50V,NPO; MPN CC0402JRNPO9BN120
C75: 10uF; C0603; Voltage Rating 10V,X5R; MPN CL10A106KP8NNNC
C76, C82, C106, C112: 1uF; C0402; Voltage Rating 10V,X5R; MPN CL05A105KP5NNNC
C86: 10nF; C0402; Voltage Rating 50V,X7R; MPN CC0402KRX7R9BB103
C91, C95, C105, C107, C108, C109, C132: 100nF; C0402; Voltage Rating 25V,X7R; MPN CC0402KRX7R8BB104
C96: 0.8PF; C0201; Voltage Rating 50V-0.01pF-C0G/NP0; MPN GRM0335C1HR80BA01D
C97: 1.2pF; C0201; Voltage Rating ±0.25pF; MPN CC0201CRNPO9BN1R2
C101: 1.2pF; C0201; Voltage Rating ±0.25pF; MPN CC0201CRNPO9BN1R2; not fitted
C102: 0.5pF; C0201; Voltage Rating ±0.25pF; MPN CC0201CRNPO9BN1R2; not fitted
D11: LRB520S-30T1G; SOD-523; Rating 30V,200mA; MPN LRB520S-30T1G
FB10: 120R; L0603; Rating 2A; MPN BLM18PG121SN1D
L3: 3.3pF; L0201; MPN CQ0201BRNPO8BN3R3
L4: 2.2nH; L0402; Rating 1A; MPN LQW15AN2N2C10D
L6: 2.2nH; L0201; Rating 600mA; MPN LQP03TQ2N2B02D
L7: 2.2nH; L0201; Rating 600mA; MPN LQP03TN1N5B02D; not fitted
R9, R34, R92, R93, R94, R95, R96, R97, R101, R102, R146: 0R; R0402; Power Rating 5%; MPN RC0402JR-070RL
R51, R89: 10K; R0402; Power Rating 1%; MPN RC0402FR-0710KL
R68, R69, R74, R76, R81, R127: 0R; R0201; Power Rating 1%; MPN RC0201FR-070RL
R87: 499R; R0402; Power Rating 1%; MPN RC0402FR-07499RL
R123, R128, R129, R130: 4.7K; R0402; Power Rating 5%; MPN RC0402JR-074K7L
R126: 0R; R0201; Power Rating 1%; MPN RC0201FR-070RL; not fitted
TP10, TP20, TP21: Test Point; TP-D45MIL; Part Type Test Point; not fitted
TP11: TEST-POINT; TP-D45MIL; not fitted
U1: ESP32-S3R8; QFN56G-0.4-7X7MM; MPN ESP32-S3R8
U15: ZB25VQ128DSJG; SOIC8-1.27-5.3X5.3MM; MPN ZB25VQ128DSJG
U16: W25Q256JVEIQ; WSON8-1.27-8x6x0.75mm; MPN W25Q256JVEIQ; not fitted
X2: 40MHz; X4-SMD-2.0X1.6MM; Rating 10ppm; MPN Y4000Fc001

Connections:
+3V3: FB10.1; also elsewhere on the board
/ESP32/ANT: C96.1, L6.2, L7.1, R126.2, R127.1
/ESP32/RF_IN: C97.1, L6.1, U1.1 (LNA_IN)
/ESP32/SPI_CLK: R74.2, U15.6 (CLK), U16.6 (CLK)
/ESP32/SPI_CS0: U1.32 (SPICS0), U15.1 (/CS), U16.1 (/CS)
/ESP32/SPI_D: R81.2, U15.5 (DI(IO0)), U16.5 (DI(IO0))
/ESP32/SPI_HD: R68.2, U15.7 (/HOLD(IO3)), U16.7 (/HOLD(IO3))
/ESP32/SPI_Q: R76.2, U15.2 (DO(IO1)), U16.2 (DO(IO1))
/ESP32/SPI_WP: R69.2, U15.3 (/WP(IO2)), U16.3 (/WP(IO2))
AUDIO_PA_EN: U1.37 (SPICLK_P); also elsewhere on the board
Audio_DET: U1.23 (GPIO17); also elsewhere on the board
ECO_A: U1.22 (XTAL_32K_N); also elsewhere on the board
ECO_B: U1.24 (GPIO18); also elsewhere on the board
ESP_3V3: C75.1, C76.1, C82.1, C86.1, C91.1, C108.1, C109.1, C132.1, D11.2, FB10.2, L4.1, R51.2, R89.2, R123.2, R128.2, R129.2, R130.2, TP11.1 (T), U1.20 (VDD3P3_RTC), U1.46 (VDD3P3_CPU), U1.55 (VDDA@1), U1.56 (VDDA@2); also elsewhere on the board
ESP_BOOT: C113.1, R89.1, TP10.1 (T), U1.5 (GPIO0); also elsewhere on the board
ESP_IO40: U1.45 (MTDO); also elsewhere on the board
ESP_IO41: U1.47 (MTDI); also elsewhere on the board
ESP_IO42: U1.48 (MTMS); also elsewhere on the board
ESP_IO48: U1.36 (SPICLK_N); also elsewhere on the board
ESP_MUTE_DET: U1.8 (GPIO3); also elsewhere on the board
ESP_RST: C112.1, D11.1, R51.1, TP20.1 (T), U1.4 (CHIP_PU)
ESP_RX0: U1.50 (U0RXD); also elsewhere on the board
ESP_TX0: R87.2; also elsewhere on the board
ESP_USB_N: U1.25 (GPIO19); also elsewhere on the board
ESP_USB_P: U1.26 (GPIO20); also elsewhere on the board
ESP_WS2812: U1.27 (GPIO21); also elsewhere on the board
GND: ANT1.2 (GND1), ANT1.3 (GND2), ANT2.3, C7.2, C8.2, C42.2, C59.2, C75.2, C76.2, C77.2, C82.2, C86.2, C91.2, C95.2, C96.2, C97.2, C101.2, C102.2, C105.2, C106.2, C107.2, C108.2, C109.2, C112.2, C113.2, C114.2, C115.2, C116.2, C124.2, C126.2, C132.2, TP21.1 (T), U1.57 (GND), U15.4 (GND), U16.4 (GND), U16.9 (GND), X2.2, X2.4; also elsewhere on the board
GROVE_PWR: U1.52 (GPIO46); also elsewhere on the board
GROVE_SCL: U1.7 (GPIO2); also elsewhere on the board
GROVE_SDA: U1.6 (GPIO1); also elsewhere on the board
I2C2_SCL: R130.1, U1.44 (MTCK); also elsewhere on the board
I2C2_SDA: R129.1, U1.43 (GPIO38); also elsewhere on the board
I2C_SCL: R128.1, U1.11 (GPIO6); also elsewhere on the board
I2C_SDA: R123.1, U1.10 (GPIO5); also elsewhere on the board
I2S2_BCLK: C8.1, R92.1; also elsewhere on the board
I2S2_DATA: R102.1; also elsewhere on the board
I2S2_LRCLK: C124.1, R101.1; also elsewhere on the board
I2S2_MCLK: C126.1, R9.1, R146.2; also elsewhere on the board
I2S_BCLK: C115.1, R94.1; also elsewhere on the board
I2S_DIN_ESP: R97.1; also elsewhere on the board
I2S_DIN_SEC: R96.1; also elsewhere on the board
I2S_LRCK: C114.1, R93.1; also elsewhere on the board
I2S_MCLK: C116.1, R95.1, R146.1; also elsewhere on the board
unnamed: ANT1.1 (D), R126.1
unnamed: ANT2.1, C101.1, L3.2
unnamed: C42.1, L3.1, R127.2
unnamed: C59.1, R34.2, X2.1
unnamed: C102.1, L7.2
unnamed: R93.2, U1.12 (GPIO7)
unnamed: R94.2, U1.13 (GPIO8)
unnamed: R95.2, U1.14 (GPIO9)
unnamed: R96.2, U1.15 (GPIO10)
unnamed: R97.2, U1.16 (GPIO11)
unnamed: R9.2, U1.17 (GPIO12)
unnamed: R92.2, U1.18 (GPIO13)
unnamed: R101.2, U1.19 (GPIO14)
unnamed: R74.1, U1.33 (SPICLK/CLK)
unnamed: R81.1, U1.35 (SPID/DQ0)
unnamed: R68.1, U1.30 (SPIHD/DQ3)
unnamed: R76.1, U1.34 (SPIQ/DQ1)
unnamed: R69.1, U1.31 (SPIWP/DQ2)
unnamed: R87.1, U1.49 (U0TXD)
unnamed: C7.1, C95.1, L4.2, U1.2 (VDD3P3@1), U1.3 (VDD3P3@2)
unnamed: R102.2, U1.21 (XTAL_32K_P)
unnamed: C77.1, U1.53 (XTAL_N), X2.3
unnamed: R34.1, U1.54 (XTAL_P)
VDD_SPI: C105.1, C106.1, C107.1, U1.29 (VDD_SPI), U15.8 (VCC), U16.8 (VCC)
WS2812_PWR: U1.51 (GPIO45); also elsewhere on the board
XU316_RST: U1.9 (GPIO4); also elsewhere on the board

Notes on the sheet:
GPIO45:Pull-Down
Layout Note: Close to Pin 2,3
GPIO46:Pull-Down
Flash

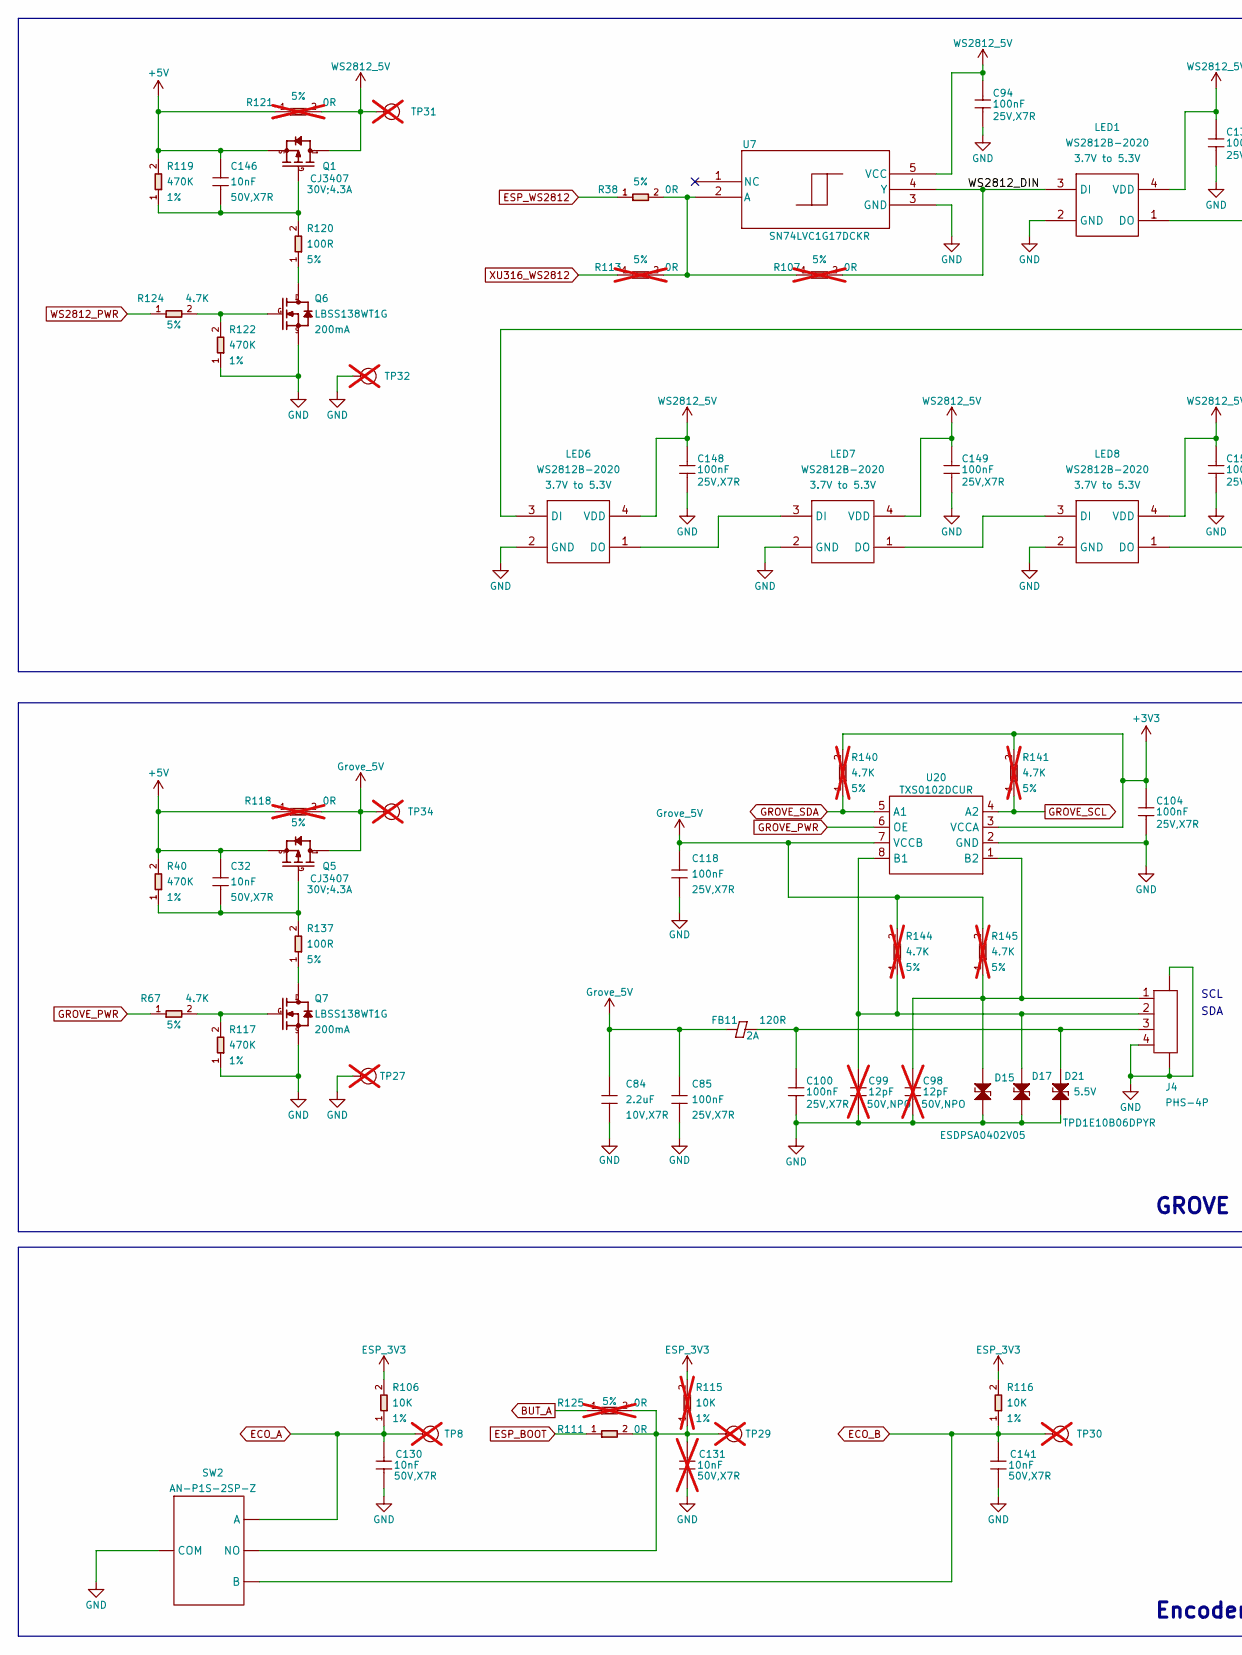
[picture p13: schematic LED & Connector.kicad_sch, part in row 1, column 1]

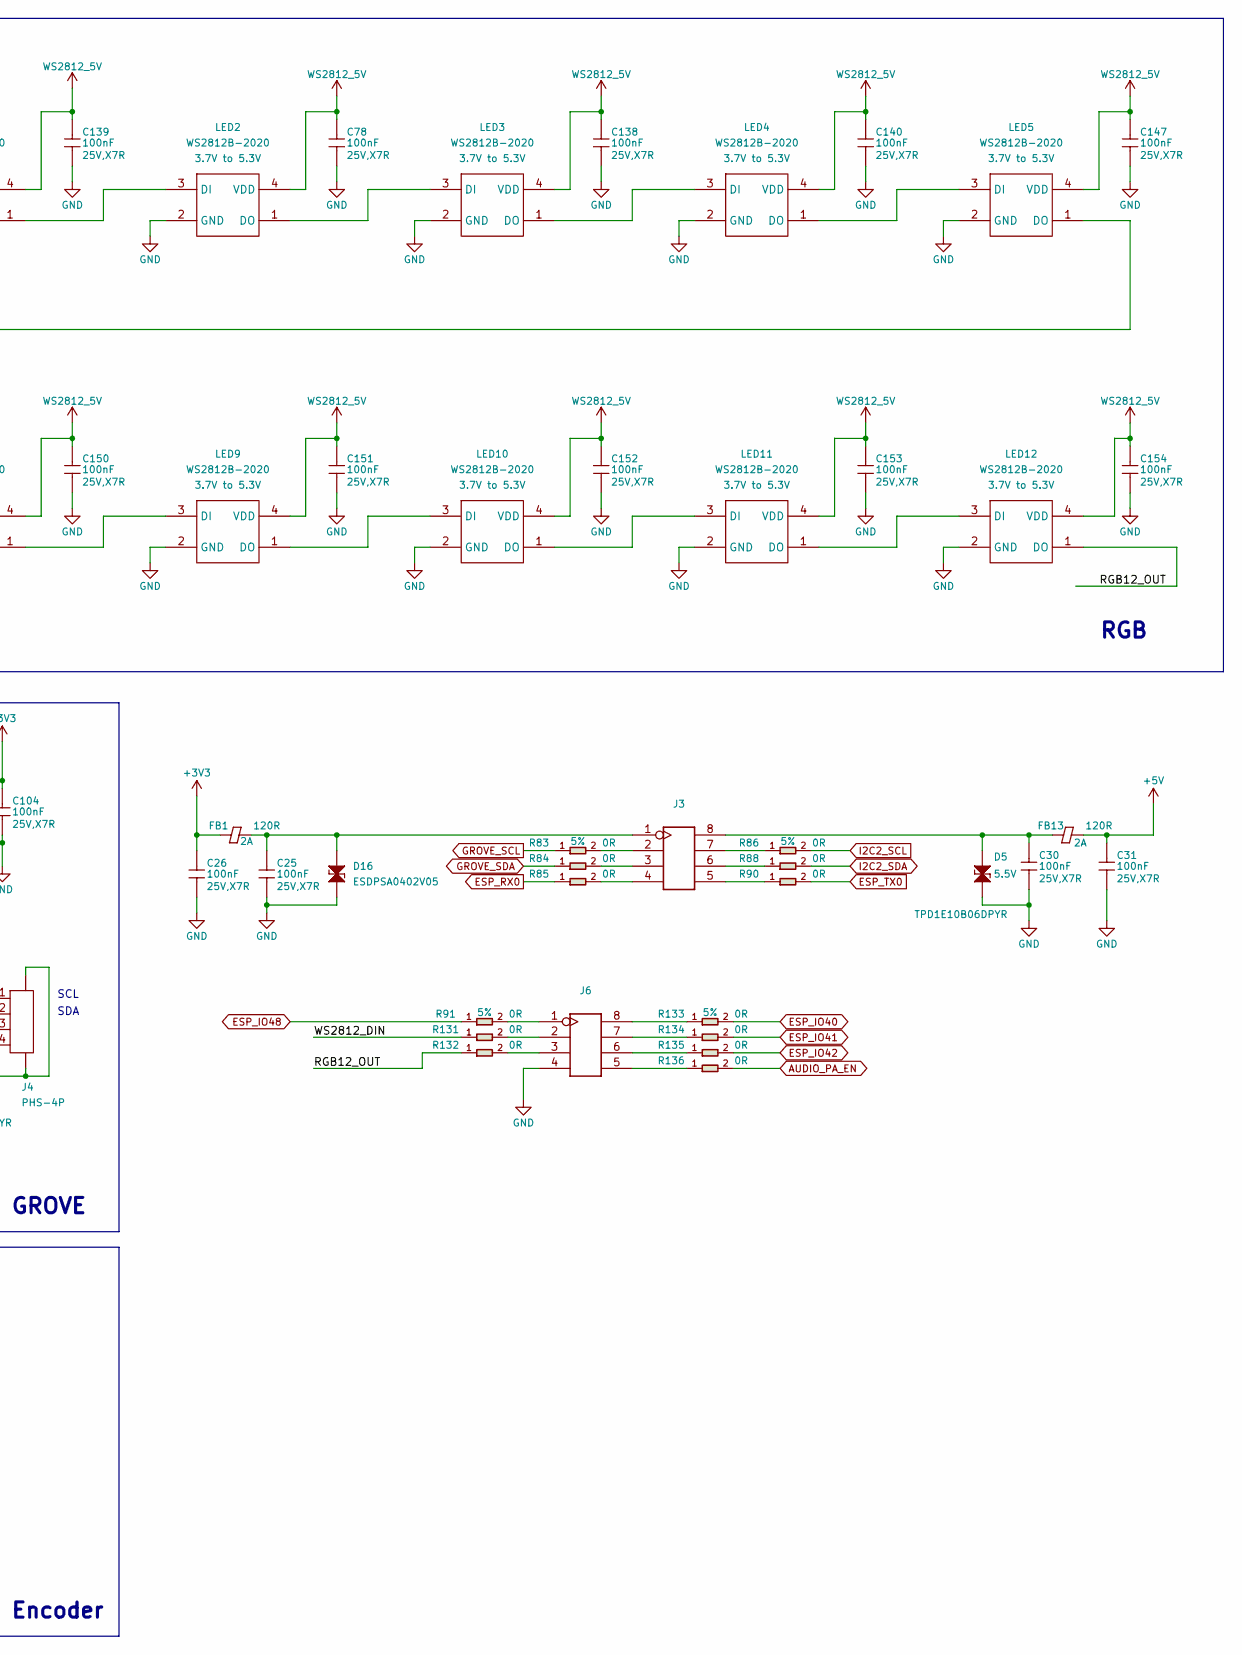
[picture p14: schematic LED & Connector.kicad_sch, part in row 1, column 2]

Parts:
C25, C26, C30, C31, C78, C85, C94, C100, C104, C118, C138, C139, C140, C147, C148, C149, C150, C151, C152, C153, C154: 100nF; C0402; Voltage Rating 25V,X7R; MPN CC0402KRX7R8BB104
C32, C130, C141, C146: 10nF; C0402; Voltage Rating 50V,X7R; MPN CC0402KRX7R9BB103
C84: 2.2uF; C0603; Voltage Rating 10V,X7R; MPN CC0603KRX7R6BB225
C98, C99: 12pF; C0402; Voltage Rating 50V,NPO; MPN CC0402JRNPO9BN120; not fitted
C131: 10nF; C0402; Voltage Rating 50V,X7R; MPN CC0402KRX7R9BB103; not fitted
D5, D21: TPD1E10B06DPYR; ESD-0402; Rating 5.5V; MPN TPD1E10B06DPYR
D15, D16, D17: ESDPSA0402V05; ESD-0402; MPN ESDPSA0402V05
FB1, FB11, FB13: 120R; L0603; Rating 2A; MPN BLM18PG121SN1D
J3, J6: H2X4-2.54-65_35MIL; Part Type Header
J4: PHS-4P; HW4-SMD-2.0; MPN PHS-4P
LED1, LED2, LED3, LED4, LED5, LED6, LED7, LED8, LED9, LED10, LED11, LED12: WS2812B-2020; LED4-1.0-2.2X2X0.84MM; Rating 3.7V to 5.3V; MPN WS2812B-2020
Q1, Q5: CJ3407; SOT23; Rating 30V;4.3A; MPN CJ3407
Q6, Q7: LBSS138WT1G; SOT-323; Rating 200mA; MPN LBSS138WT1G
R38, R83, R84, R85, R86, R88, R90, R91, R111, R131, R132, R133, R134, R135, R136: 0R; R0402; Power Rating 5%; MPN RC0402JR-070RL
R40, R117, R119, R122: 470K; R0402; Power Rating 1%; MPN RC0402FR-07470KL
R67, R124: 4.7K; R0402; Power Rating 5%; MPN RC0402JR-074K7L
R106, R116: 10K; R0402; Power Rating 1%; MPN RC0402FR-0710KL
R107, R113, R125: 0R; R0402; Power Rating 5%; MPN RC0402JR-070RL; not fitted
R115: 10K; R0402; Power Rating 1%; MPN RC0402FR-0710KL; not fitted
R118: 0R; R0603; Power Rating 5%; MPN RC0603JR-070RL; not fitted
R120, R137: 100R; R0402; Power Rating 5%; MPN RC0402JR-07100RL
R121: 0R; R1206; Power Rating 5%; MPN RC1206JR-070RL; not fitted
R140, R141, R144, R145: 4.7K; R0402; Power Rating 5%; MPN RC0402JR-074K7L; not fitted
SW2: AN-P1S-2SP-Z; MPN AN-P1S-2SP-Z
TP8: TEST-POINT; TP-D45MIL; not fitted
TP27, TP29, TP30, TP31, TP32, TP34: Test Point; TP-D45MIL; Part Type Test Point; not fitted
U7: SN74LVC1G17DCKR; MPN SN74LVC1G17DCKR
U20: TXS0102DCUR; VSSOP8-0.5-2.3X2X0.9MM; MPN TXS0102DCUR

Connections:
+3V3: C26.1, C104.1, FB1.1, R140.2, R141.2, U20.3 (VCCA); also elsewhere on the board
+5V: C31.1, C32.1, C146.1, FB13.2, Q1.2 (S), Q5.2 (S), R40.2, R118.1, R119.2, R121.1; also elsewhere on the board
/LED & Connector/RGB12_OUT: LED12.1 (DO), R132.1
/LED & Connector/WS2812_DIN: LED1.3 (DI), R107.2, R131.1, U7.4 (Y)
AUDIO_PA_EN: R136.2; also elsewhere on the board
BUT_A: R125.1; also elsewhere on the board
ECO_A: C130.1, R106.1, SW2.A, TP8.1 (T); also elsewhere on the board
ECO_B: C141.1, R116.1, SW2.B, TP30.1 (T); also elsewhere on the board
ESP_3V3: R106.2, R115.2, R116.2; also elsewhere on the board
ESP_BOOT: R111.1; also elsewhere on the board
ESP_IO40: R133.2; also elsewhere on the board
ESP_IO41: R134.2; also elsewhere on the board
ESP_IO42: R135.2; also elsewhere on the board
ESP_IO48: R91.1; also elsewhere on the board
ESP_RX0: R85.1; also elsewhere on the board
ESP_TX0: R90.2; also elsewhere on the board
ESP_WS2812: R38.1; also elsewhere on the board
GND: C25.2, C26.2, C30.2, C31.2, C78.2, C84.2, C85.2, C94.2, C98.2, C99.2, C100.2, C104.2, C118.2, C130.2, C131.2, C138.2, C139.2, C140.2, C141.2, C147.2, C148.2, C149.2, C150.2, C151.2, C152.2, C153.2, C154.2, D5.1, D15.1, D16.1, D17.1, D21.1, J4.4, J4.5, J4.6, J6.4, LED1.2 (GND), LED2.2 (GND), LED3.2 (GND), LED4.2 (GND), LED5.2 (GND), LED6.2 (GND), LED7.2 (GND), LED8.2 (GND), LED9.2 (GND), LED10.2 (GND), LED11.2 (GND), LED12.2 (GND), Q6.2 (S), Q7.2 (S), R117.1, R122.1, SW2.COM, TP27.1 (T), TP32.1 (T), U7.3 (GND), U20.2 (GND); also elsewhere on the board
GROVE_PWR: R67.1, U20.6 (OE); also elsewhere on the board
GROVE_SCL: R83.1, R141.1, U20.4 (A2); also elsewhere on the board
GROVE_SDA: R84.1, R140.1, U20.5 (A1); also elsewhere on the board
Grove_5V: C84.1, C85.1, C118.1, FB11.1, Q5.3 (D), R118.2, R144.2, R145.2, TP34.1 (T), U20.7 (VCCB)
I2C2_SCL: R86.2; also elsewhere on the board
I2C2_SDA: R88.2; also elsewhere on the board
unnamed: C25.1, D16.2, FB1.2, J3.1
unnamed: C30.1, D5.2, FB13.1, J3.8
unnamed: C100.1, D21.2, FB11.2, J4.3
unnamed: J3.2, R83.2
unnamed: J3.3, R84.2
unnamed: J3.4, R85.2
unnamed: J3.5, R90.1
unnamed: J3.6, R88.1
unnamed: J3.7, R86.1
unnamed: J6.1, R91.2
unnamed: J6.2, R131.2
unnamed: J6.3, R132.2
unnamed: J6.5, R136.1
unnamed: J6.6, R135.1
unnamed: J6.7, R134.1
unnamed: J6.8, R133.1
unnamed: LED1.1 (DO), LED2.3 (DI)
unnamed: LED2.1 (DO), LED3.3 (DI)
unnamed: LED3.1 (DO), LED4.3 (DI)
unnamed: LED4.1 (DO), LED5.3 (DI)
unnamed: LED5.1 (DO), LED6.3 (DI)
unnamed: LED6.1 (DO), LED7.3 (DI)
unnamed: LED7.1 (DO), LED8.3 (DI)
unnamed: LED8.1 (DO), LED9.3 (DI)
unnamed: LED9.1 (DO), LED10.3 (DI)
unnamed: LED10.1 (DO), LED11.3 (DI)
unnamed: LED11.1 (DO), LED12.3 (DI)
unnamed: C146.2, Q1.1 (G), R119.1, R120.2
unnamed: C32.2, Q5.1 (G), R40.1, R137.2
unnamed: Q6.3 (D), R120.1
unnamed: Q6.1 (G), R122.2, R124.2
unnamed: Q7.3 (D), R137.1
unnamed: Q7.1 (G), R67.2, R117.2
unnamed: C131.1, R111.2, R115.1, R125.2, SW2.NO, TP29.1 (T)
unnamed: R38.2, R107.1, R113.2, U7.2 (A)
unnamed: C99.1, D17.2, J4.2, R144.1, U20.8 (B1)
unnamed: C98.1, D15.2, J4.1, R145.1, U20.1 (B2)
WS2812_5V: C78.1, C94.1, C138.1, C139.1, C140.1, C147.1, C148.1, C149.1, C150.1, C151.1, C152.1, C153.1, C154.1, LED1.4 (VDD), LED2.4 (VDD), LED3.4 (VDD), LED4.4 (VDD), LED5.4 (VDD), LED6.4 (VDD), LED7.4 (VDD), LED8.4 (VDD), LED9.4 (VDD), LED10.4 (VDD), LED11.4 (VDD), LED12.4 (VDD), Q1.3 (D), R121.2, TP31.1 (T), U7.5 (VCC)
WS2812_PWR: R124.1; also elsewhere on the board
XU316_WS2812: R113.1; also elsewhere on the board

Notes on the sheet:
Encoder
SCL
SDA
GROVE
RGB

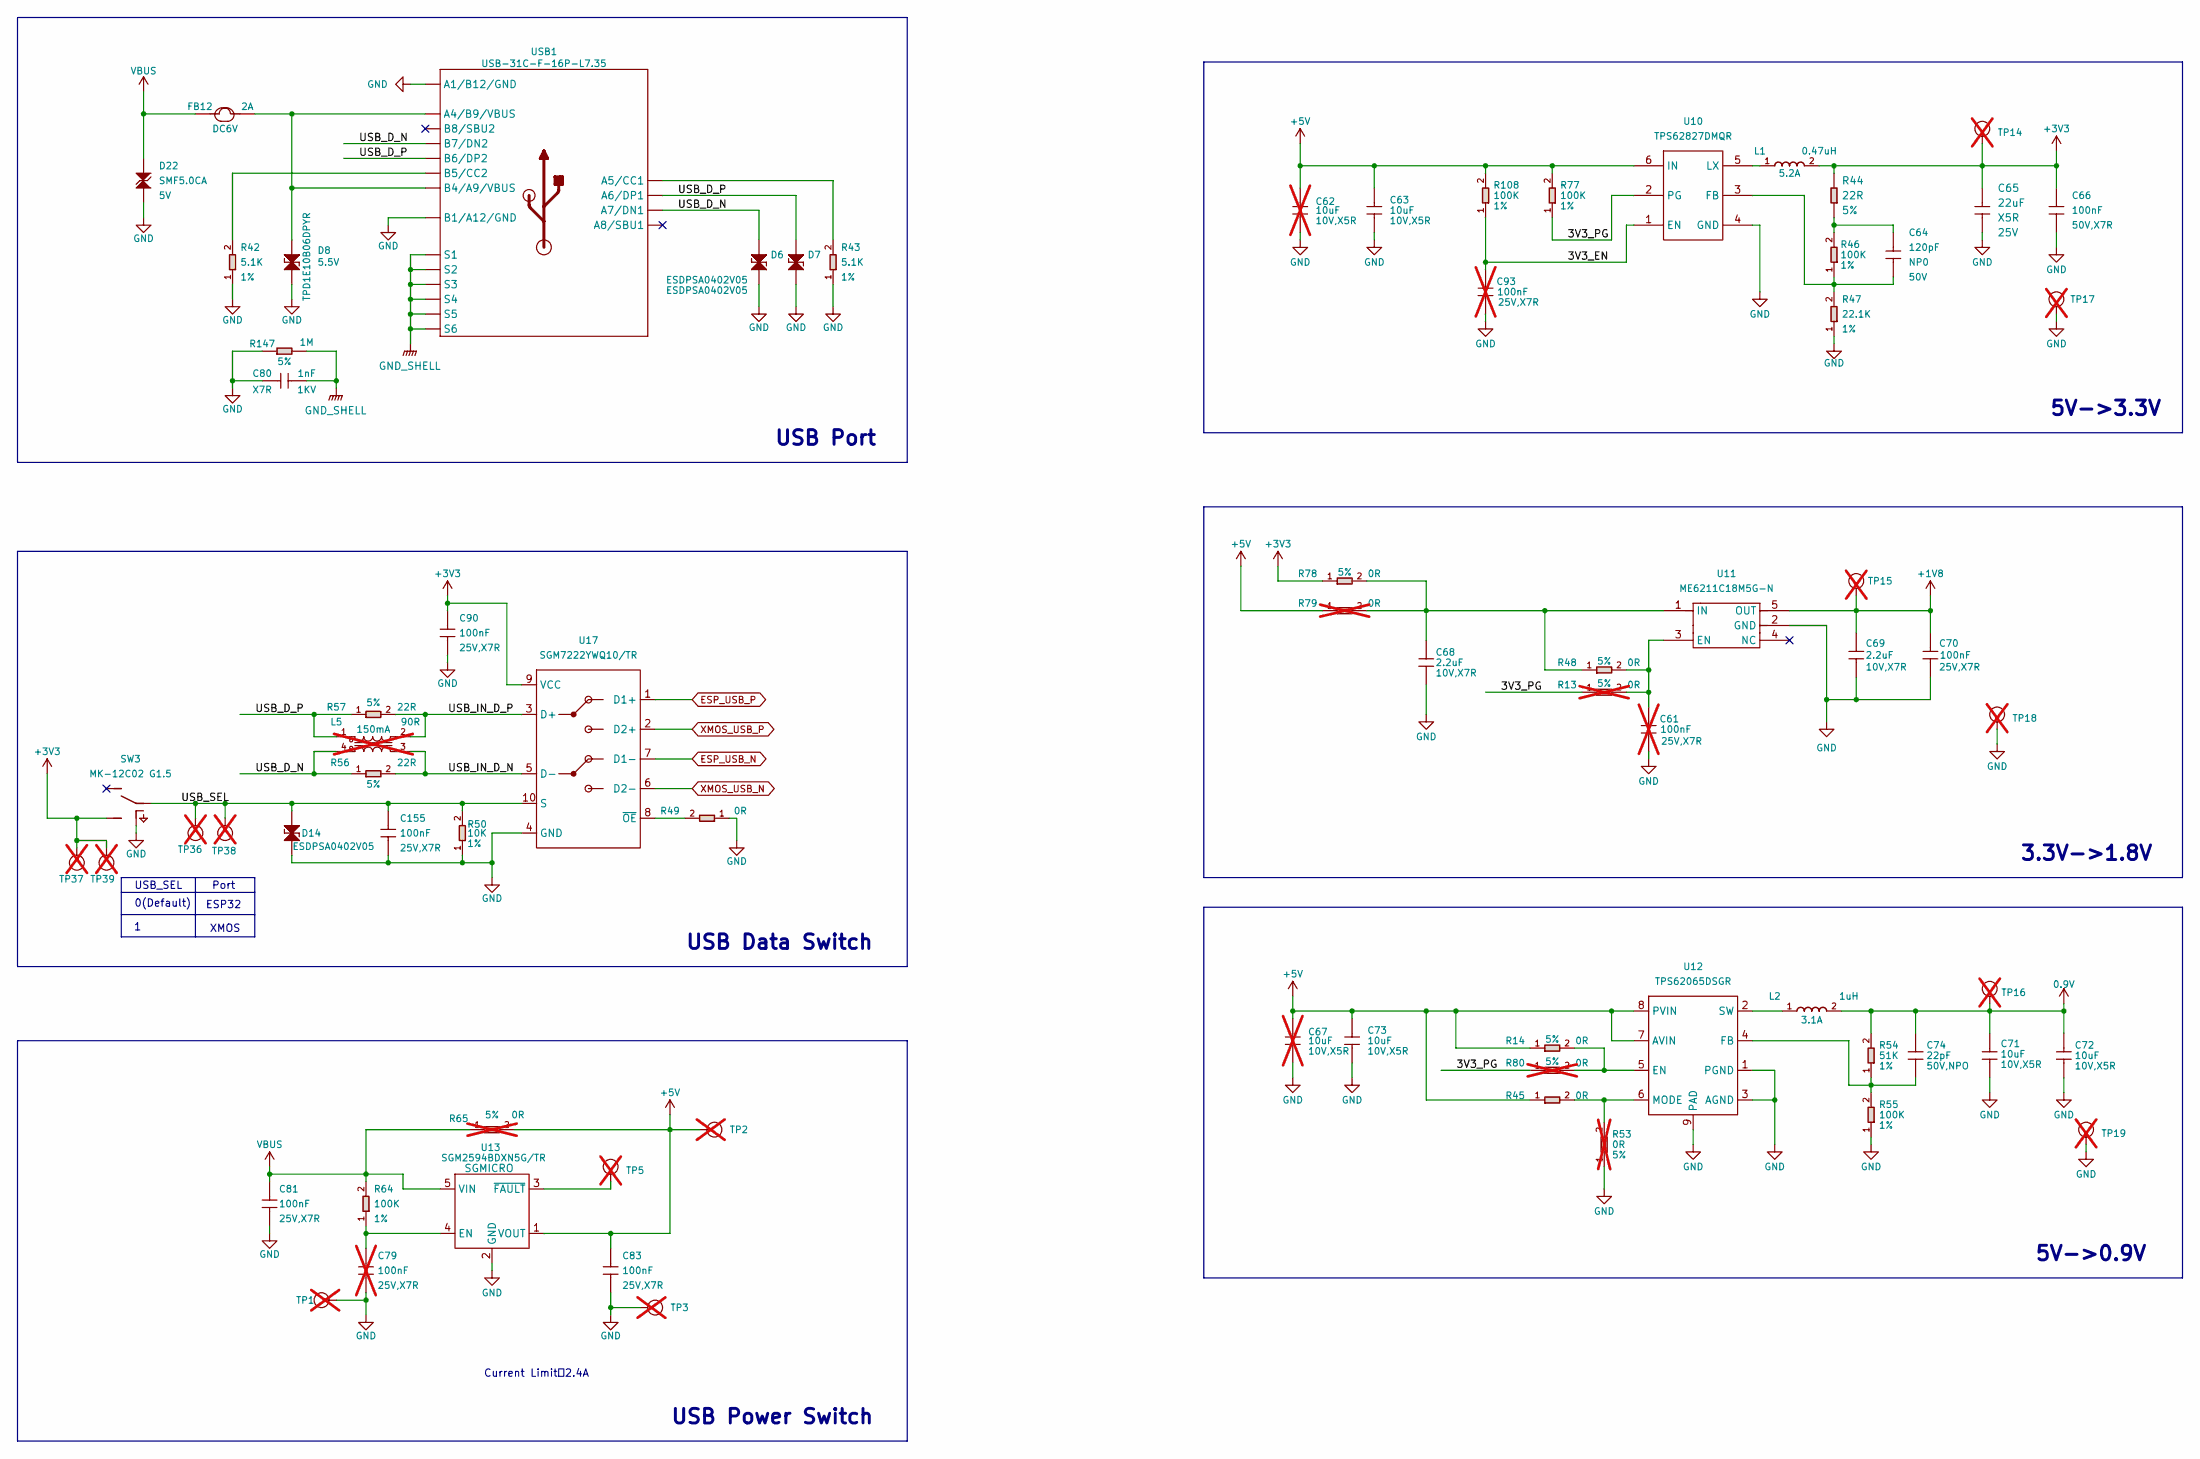
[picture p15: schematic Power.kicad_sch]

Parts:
C61, C79, C93: 100nF; C0402; Voltage Rating 25V,X7R; MPN CC0402KRX7R8BB104; not fitted
C62, C67: 10uF; C0603; Voltage Rating 10V,X5R; MPN CL10A106KP8NNNC; not fitted
C63, C71, C72, C73: 10uF; C0603; Voltage Rating 10V,X5R; MPN CL10A106KP8NNNC
C64: 120pF; C0402; Voltage Rating 50V; MPN CC0402JRNPO9BN121
C65: 22uF; C0805; Voltage Rating 25V; MPN CL21A226MAYNNNE
C66: 100nF; C0603; Voltage Rating 50V,X7R; MPN CC0603KRX7R9BB104
C68, C69: 2.2uF; C0603; Voltage Rating 10V,X7R; MPN CC0603KRX7R6BB225
C70, C81, C83, C90, C155: 100nF; C0402; Voltage Rating 25V,X7R; MPN CC0402KRX7R8BB104
C74: 22pF; C0402; Voltage Rating 50V,NPO; MPN CC0402JRNPO9BN220
C80: 1nF; C1206; Voltage Rating 1KV; MPN CC1206KKX7RCBB102
D6, D7, D14: ESDPSA0402V05; ESD-0402; MPN ESDPSA0402V05
D8: TPD1E10B06DPYR; ESD-0402; Rating 5.5V; MPN TPD1E10B06DPYR
D22: SMF5.0CA; SOD-123; Rating 5V; MPN SMF5.0CA
FB12: 2A; F1206; Rating DC6V; MPN SMD1206R200SF
L1: 0.47uH; L0805; Rating 5.2A; MPN WPN201610MR47MT
L2: 1uH; L2016; Rating 3.1A; MPN WPN201610U1R0MTY01
L5: 90R; INT4-SMD-1X1.25X0.82MM; Rating 150mA; MPN DLP11SN900HL2L; not fitted
R13, R53, R79, R80: 0R; R0402; Power Rating 5%; MPN RC0402JR-070RL; not fitted
R14, R45, R48, R49, R78: 0R; R0402; Power Rating 5%; MPN RC0402JR-070RL
R42, R43: 5.1K; R0402; Power Rating 1%; MPN RC0402FR-075K1L
R44, R56, R57: 22R; R0402; Power Rating 5%; MPN RC0402JR-0722RL
R46, R55, R64, R77, R108: 100K; R0402; Power Rating 1%; MPN RC0402FR-07100KL
R47: 22.1K; R0402; Power Rating 1%; MPN RC0402FR-0722K1L
R50: 10K; R0402; Power Rating 1%; MPN RC0402FR-0710KL
R54: 51K; R0402; Power Rating 1%; MPN RC0402FR-0751KL
R65: 0R; R1206; Power Rating 5%; MPN RC1206JR-070RL; not fitted
R147: 1M; R0805; Power Rating 5%; MPN RC0805JR-071ML
SW3: MK-12C02 G1.5; SW7-SMD-L6.7X2.7X3.2MM; MPN MK-12C02 G1.5
TP1, TP5, TP14, TP15, TP16, TP17, TP18, TP19: TEST-POINT; TP-D45MIL; not fitted
TP2, TP3: Test Point; TP-1.6MM-ROUND; Part Type Test Point; not fitted
TP36, TP37: Test Point; TP-D120MIL; Part Type Test Point; not fitted
TP38, TP39: Test Point; TP-D45MIL; Part Type Test Point; not fitted
U10: TPS62827DMQR; DFN6-0.5-1.5X1.5X0.65MM; MPN TPS62827DMQR
U11: ME6211C18M5G-N; SOT-23-5; MPN ME6211C18M5G-N
U12: TPS62065DSGR; DFN8G-0.5-2X2MM; MPN TPS62065DSGR
U13: SGM2594BDXN5G/TR; SOT-23-5; MPN SGM2594BDXN5G/TR
U17: SGM7222YWQ10/TR; WQFN10_0d4_1_8x1_4x0_75mm; MPN SGM7222YWQ10/TR
USB1: USB-31C-F-16P-L7.35; USB2.0-TYPE-C; MPN USB-31C-F-16P-L7.35

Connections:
0.9V: C71.1, C72.1, C74.1, L2.2, R54.2, TP16.1 (T); also elsewhere on the board
+1V8: C69.1, C70.1, TP15.1 (T), U11.5 (OUT); also elsewhere on the board
+3V3: C65.1, C66.1, C90.1, L1.2, R44.2, R78.1, SW3.3 (B), TP14.1 (T), TP37.1 (T), TP39.1 (T), U17.9 (VCC); also elsewhere on the board
+5V: C62.1, C63.1, C67.1, C73.1, C83.1, R14.1, R45.1, R65.2, R77.2, R79.1, R108.2, TP2.1 (T), U10.6 (IN), U12.7 (AVIN), U12.8 (PVIN), U13.1 (VOUT); also elsewhere on the board
/Power/3V3_EN: C93.1, R108.1, U10.1 (EN)
/Power/3V3_PG: R13.1, R77.1, R80.1, U10.2 (PG)
/Power/USB_D_N: D6.2, L5.4, R56.1, USB1.A7 (A7/DN1), USB1.B7 (B7/DN2)
/Power/USB_D_P: D7.2, L5.1, R57.1, USB1.A6 (A6/DP1), USB1.B6 (B6/DP2)
/Power/USB_IN_D_N: L5.3, R56.2, U17.5 (D-)
/Power/USB_IN_D_P: L5.2, R57.2, U17.3 (D+)
/Power/USB_SEL: C155.1, D14.1, R50.2, SW3.2 (COM), TP36.1 (T), TP38.1 (T), U17.10 (S)
ESP_USB_N: U17.7 (D1-); also elsewhere on the board
ESP_USB_P: U17.1 (D1+); also elsewhere on the board
GND: C61.2, C62.2, C63.2, C65.2, C66.2, C67.2, C68.2, C69.2, C70.2, C71.2, C72.2, C73.2, C79.2, C80.1, C81.2, C83.2, C90.2, C93.2, C155.2, D6.1, D7.1, D8.1, D14.2, D22.1, R42.1, R43.1, R47.1, R49.1, R50.1, R53.1, R55.1, R147.1, SW3.P1 (SS2), SW3.P2 (SS2), SW3.P3 (SS2), SW3.P4 (SS2), TP1.1 (T), TP3.1 (T), TP17.1 (T), TP18.1 (T), TP19.1 (T), U10.4 (GND), U11.2 (GND), U12.1 (PGND), U12.3 (AGND), U12.9 (PAD), U13.2 (GND), U17.4 (GND), USB1.A1_B12 (A1/B12/GND), USB1.B1_A12 (B1/A12/GND); also elsewhere on the board
GND_SHELL: C80.2, R147.2, USB1.S1, USB1.S2, USB1.S3, USB1.S4, USB1.S5, USB1.S6
unnamed: C64.1, R44.1, R46.2
unnamed: TP5.1 (T), U13.3 (~FAULT)
unnamed: C64.2, R46.1, R47.2, U10.3 (FB)
unnamed: L1.1, U10.5 (LX)
unnamed: C61.1, R13.2, R48.2, U11.3 (EN)
unnamed: C68.1, R48.1, R78.2, R79.2, U11.1 (IN)
unnamed: R14.2, R80.2, U12.5 (EN)
unnamed: C74.2, R54.1, R55.2, U12.4 (FB)
unnamed: R45.2, R53.2, U12.6 (MODE)
unnamed: L2.1, U12.2 (SW)
unnamed: C79.1, R64.1, U13.4 (EN)
unnamed: R49.2, U17.8 (~OE)
unnamed: D8.2, FB12.2, USB1.A4_B9 (A4/B9/VBUS), USB1.B4_A9 (B4/A9/VBUS)
unnamed: R43.2, USB1.A5 (A5/CC1)
unnamed: R42.2, USB1.B5 (B5/CC2)
VBUS: C81.1, D22.2, FB12.1, R64.2, R65.1, U13.5 (VIN); also elsewhere on the board
XMOS_USB_N: U17.6 (D2-); also elsewhere on the board
XMOS_USB_P: U17.2 (D2+); also elsewhere on the board

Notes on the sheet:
Current Limit：2.4A
USB Port
Port
3.3V->1.8V
0(Default)
5V->0.9V
ESP32
5V->3.3V
USB Power Switch
XMOS
USB Data Switch
USB_SEL

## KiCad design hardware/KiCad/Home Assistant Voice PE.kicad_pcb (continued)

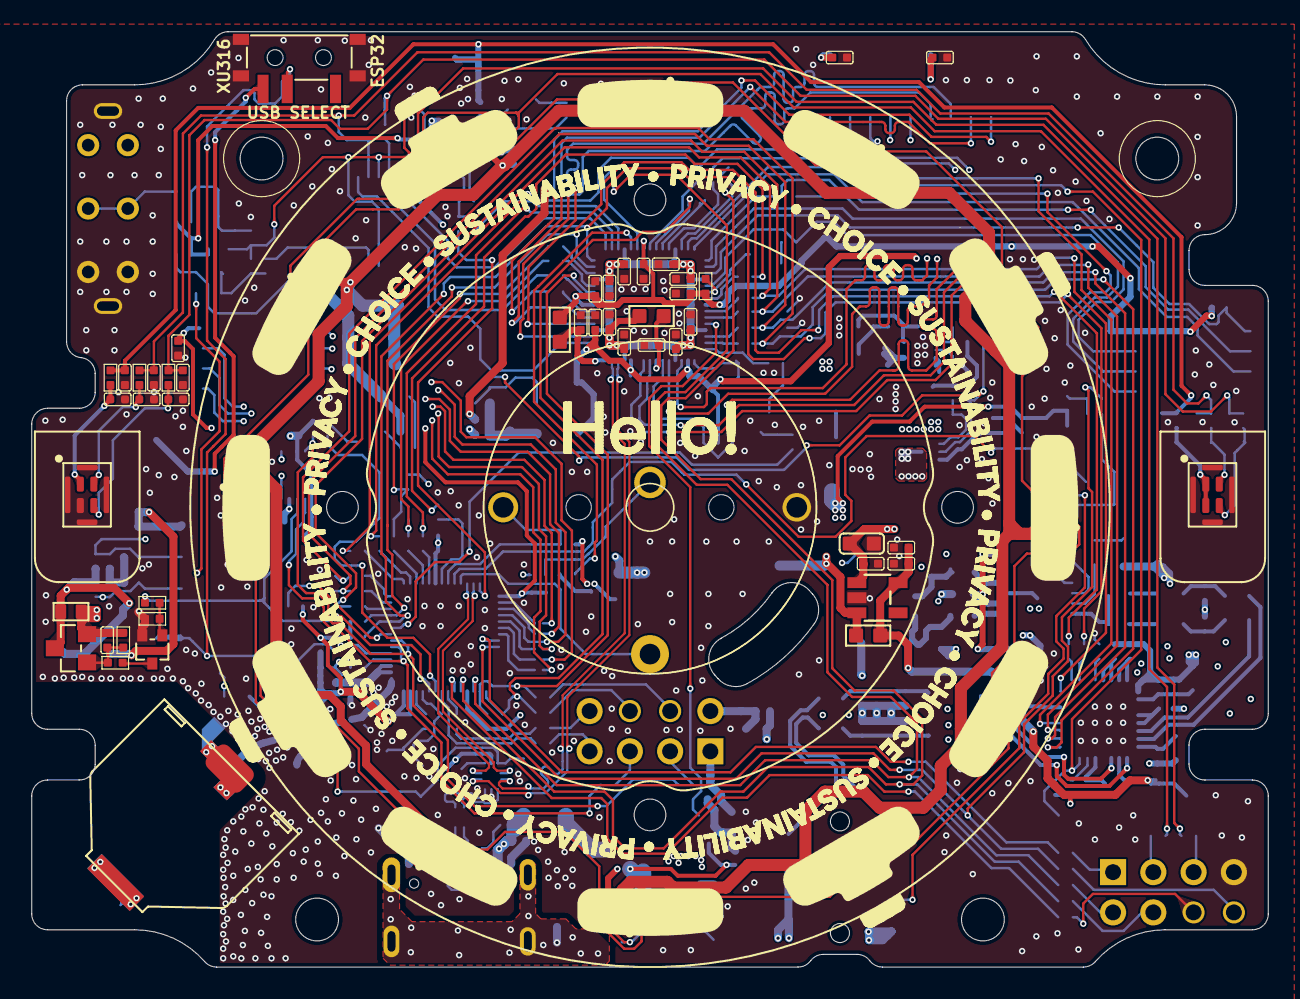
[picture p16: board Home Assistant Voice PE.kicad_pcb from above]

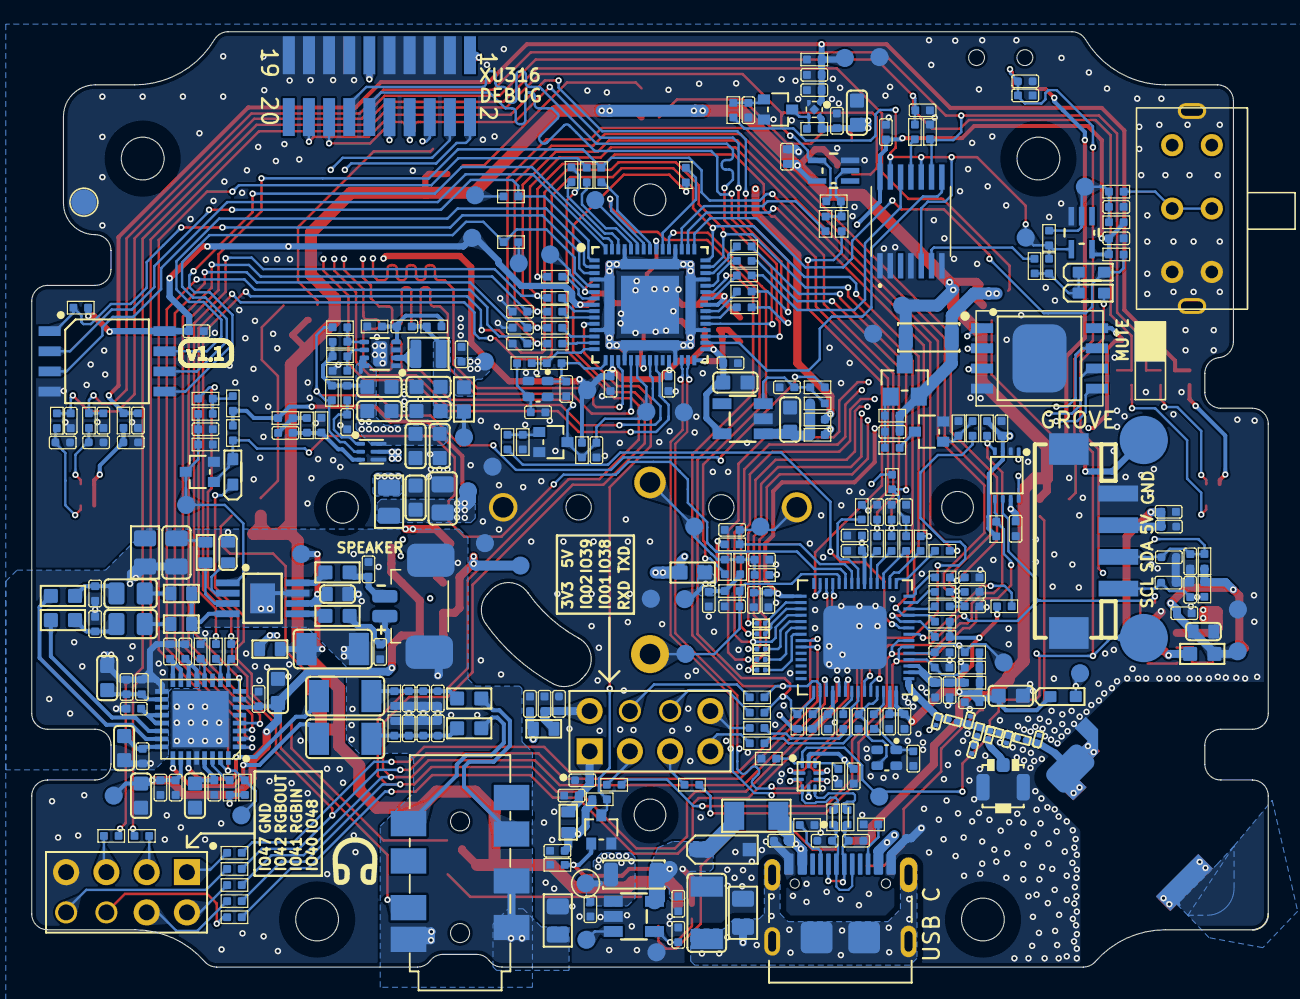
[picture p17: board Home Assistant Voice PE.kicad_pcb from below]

Board: 4 copper layers, 78.0 x 59.0 mm, 438 parts (365 on the bottom side), 239 nets.

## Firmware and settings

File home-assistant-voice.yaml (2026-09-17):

substitutions:
  # Phases of the Voice Assistant
  # The voice assistant is ready to be triggered by a wake word
  voice_assist_idle_phase_id: '1'
  # The voice assistant is waiting for a voice command (after being triggered by the wake word)
  voice_assist_waiting_for_command_phase_id: '2'
  # The voice assistant is listening for a voice command
  voice_assist_listening_for_command_phase_id: '3'
  # The voice assistant is currently processing the command
  voice_assist_thinking_phase_id: '4'
  # The voice assistant is replying to the command
  voice_assist_replying_phase_id: '5'
  # The voice assistant is not ready
  voice_assist_not_ready_phase_id: '10'
  # The voice assistant encountered an error
  voice_assist_error_phase_id: '11'
  # Change this to true in case you ahve a hidden SSID at home.
  hidden_ssid: "false"
  # Substitutions for audio files
  jack_connected_sound_file: https://github.com/esphome/home-assistant-voice-pe/raw/dev/sounds/jack_connected.flac
  jack_disconnected_sound_file: https://github.com/esphome/home-assistant-voice-pe/raw/dev/sounds/jack_disconnected.flac
  mute_switch_on_sound_file: https://github.com/esphome/home-assistant-voice-pe/raw/dev/sounds/mute_switch_on.flac
  mute_switch_off_sound_file: https://github.com/esphome/home-assistant-voice-pe/raw/dev/sounds/mute_switch_off.flac
  timer_finished_sound_file: https://github.com/esphome/home-assistant-voice-pe/raw/dev/sounds/timer_finished.flac
  wake_word_triggered_sound_file: https://github.com/esphome/home-assistant-voice-pe/raw/dev/sounds/wake_word_triggered.flac
  center_button_press_sound_file: https://github.com/esphome/home-assistant-voice-pe/raw/dev/sounds/center_button_press.flac
  center_button_double_press_sound_file: https://github.com/esphome/home-assistant-voice-pe/raw/dev/sounds/center_button_double_press.flac
  center_button_triple_press_sound_file: https://github.com/esphome/home-assistant-voice-pe/raw/dev/sounds/center_button_triple_press.flac
  center_button_long_press_sound_file: https://github.com/esphome/home-assistant-voice-pe/raw/dev/sounds/center_button_long_press.flac
  factory_reset_initiated_sound_file: https://github.com/esphome/home-assistant-voice-pe/raw/dev/sounds/factory_reset_initiated.mp3
  factory_reset_cancelled_sound_file: https://github.com/esphome/home-assistant-voice-pe/raw/dev/sounds/factory_reset_cancelled.mp3
  factory_reset_confirmed_sound_file: https://github.com/esphome/home-assistant-voice-pe/raw/dev/sounds/factory_reset_confirmed.mp3
  easter_egg_tick_sound_file: https://github.com/esphome/home-assistant-voice-pe/raw/dev/sounds/easter_egg_tick.mp3
  easter_egg_tada_sound_file: https://github.com/esphome/home-assistant-voice-pe/raw/dev/sounds/easter_egg_tada.mp3
  error_cloud_expired_sound_file: https://github.com/esphome/home-assistant-voice-pe/raw/dev/sounds/error_cloud_expired.mp3

esphome:
  name: home-assistant-voice
  friendly_name: Home Assistant Voice
  name_add_mac_suffix: true
  min_version: 2026.9.0
  on_boot:
    priority: 375
    then:
      # Run the script to refresh the LED status
      - script.execute: control_leds
      - delay: 1s
      - switch.turn_on: internal_speaker_amp
      # If after 10 minutes, the device is still initializing (It did not yet connect to Home Assistant), turn off the init_in_progress variable and run the script to refresh the LED status
      - delay: 10min
      - if:
          condition:
            lambda: return id(init_in_progress);
          then:
            - lambda: id(init_in_progress) = false;
            - script.execute: control_leds

esp32:
  board: esp32-s3-devkitc-1
  cpu_frequency: 240MHz
  variant: esp32s3
  flash_size: 16MB
  framework:
    type: esp-idf
    version: recommended
    sdkconfig_options:
      CONFIG_ESP32S3_DATA_CACHE_64KB: "y"
      CONFIG_ESP32S3_DATA_CACHE_LINE_64B: "y"
      CONFIG_ESP32S3_INSTRUCTION_CACHE_32KB: "y"

      # Moves instructions and read only data from flash into PSRAM on boot.
      # Both enabled allows instructions to execute while a flash operation is in progress without needing to be placed in IRAM.
      # Considerably speeds up mWW at the cost of using more PSRAM.
      CONFIG_SPIRAM_RODATA: "y"
      CONFIG_SPIRAM_FETCH_INSTRUCTIONS: "y"

      CONFIG_BT_ALLOCATION_FROM_SPIRAM_FIRST: "y"
      CONFIG_BT_BLE_DYNAMIC_ENV_MEMORY: "y"

      CONFIG_MBEDTLS_EXTERNAL_MEM_ALLOC: "y"
      CONFIG_MBEDTLS_SSL_PROTO_TLS1_3: "y"  # TLS1.3 support isn't enabled by default in IDF 5.1.5
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

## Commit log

2026-05-20 Add handover document for voice assistant microphone restart bug
    Documents the bug where Voice PE starts listening before TTS audio
    finishes playing, causing the device to hear itself. Includes root
    cause analysis, proposed fix for esphome/esphome, and testing instructions.
    Related to issue #563.
    https://claude.ai/code/session_011kcHDsjrPxynfQQEwRDSxx
2026-05-25 Remove the second microphone channel from being sent to HA
    - Workaround for a bug where the `voice_assistant` component in 2026.5.0 can send an audio packet with zero length, which makes HA assume mic audio is done. This could potentially truncate commands.
    [home-assistant-voice.yaml]
2026-09-17 Use explicit LED strip timings instead of WS2812 chipset preset (#640)
2026-09-17 Add hardware design files (#5)
    [Block.kicad_sch, DAC.kicad_sch, ESP32S3.kicad_sch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]
2026-11-13 Support wake word audio (#653)
    * Support wake word audio
    When Home Assistant asks for wake word audio, microWakeWord only proposes
    detections and Home Assistant verifies them:
    - The okay_nabu, hey_jarvis and hey_mycroft cutoffs drop to 0.5/0.4/0.3
    depending on the sensitivity select. The stop model and timer stopping
    keep the normal cutoffs.
    - The LEDs light on detection and turn off if Home Assistant rejects it.
    A verification timeout shows the error briefly.
    - No wake sound is played, so the command can follow the wake word.
    - Media is ducked only once Home Assistant accepts the wake word.
    * Send the unprocessed channel with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

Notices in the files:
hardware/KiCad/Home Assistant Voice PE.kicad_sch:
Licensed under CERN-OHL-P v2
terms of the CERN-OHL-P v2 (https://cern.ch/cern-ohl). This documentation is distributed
